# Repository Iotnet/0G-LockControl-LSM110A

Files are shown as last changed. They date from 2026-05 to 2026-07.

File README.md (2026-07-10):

# 0G LockControl — Alarma IoT dual (acelerómetro + magnético)

> Alarma inalámbrica compacta con detección de movimiento y apertura de puerta/ventana, comunicación Sigfox RC2 sobre el SoC LSM110A.

## Descripción

**0G LockControl** es un dispositivo electrónico autónomo que combina **dos modos de detección de eventos** y los transmite por la red **Sigfox (0G)**:

- **Movimiento / vibración** vía acelerómetro **LIS2DW12** (I²C).
- **Apertura de puerta o ventana** vía sensor magnético — **reed switch NA** o **hall DRV5032** (ambos footprints en la PCB).

El dispositivo es **event-driven**: duerme en modo Stop2 (~3 µA total) y solo despierta por interrupción de hardware. El firmware se ejecuta directamente sobre el **STM32WL** integrado en el LSM110A (firmware API, sin MCU externo).

### Características

- Comunicación **Sigfox RC2** (902-928 MHz, México) — sin WiFi ni red celular.
- Tamaño objetivo **< 5 cm** — instalación adhesiva en interior (oficina, bodega, cuarto frío).
- Batería desechable **CR2450 (3 V, 620 mAh)** + capacitor de soporte 470 µF para pulsos de TX.
- Vida útil estimada de meses a años según frecuencia de eventos.
- Costo reducido de operación y manufactura.

## Arquitectura del sistema

### Ciclo de operación

```
Sleep (3µA)  →  Wake por INT (accel o magnético)  →  Leer sensor
        →  Armar payload 12 bytes  →  TX Sigfox (~50 mA × 2 s)  →  Sleep
```

### Bloques del sistema

Arquitectura del producto — 0G LockControl

<details>
<summary>Ver arquitectura del sistema completo (dispositivo → Sigfox → nube → app)</summary>

Sistema completo

</details>

<details>
<summary>Ver diagrama anterior (v1)</summary>

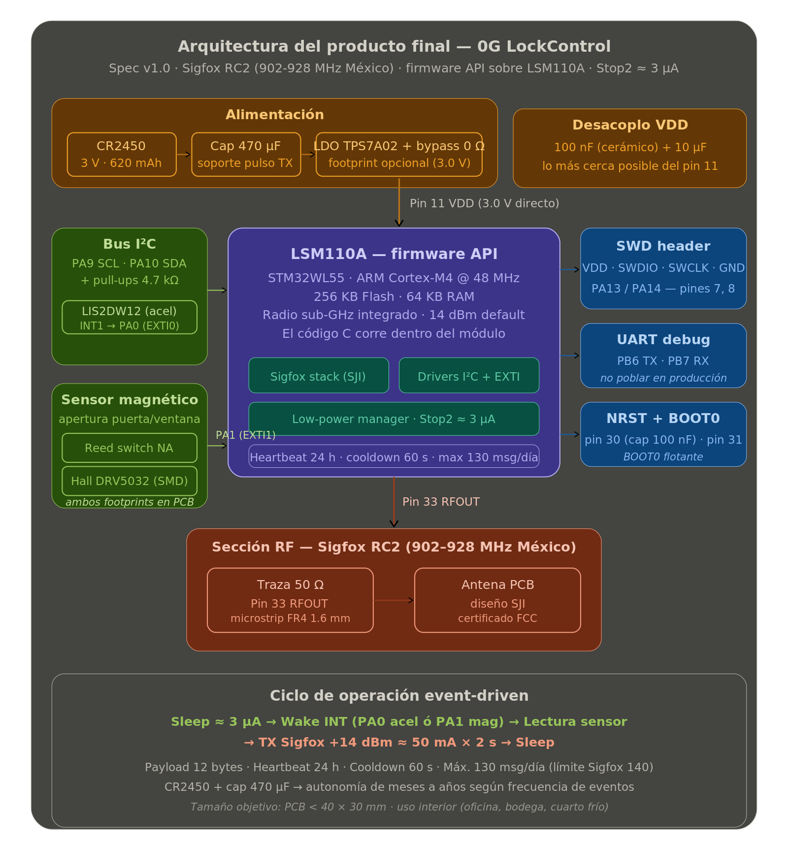
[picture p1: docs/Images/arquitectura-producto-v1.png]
Arquitectura del producto final — 0G LockControl (v1)


> Diagrama disponible también en formato vectorial: [arquitectura-producto-v1.svg](./docs/Images/arquitectura-producto-v1.svg)

</details>

### Flujo de operación

1. **Detección.** El acelerómetro o el sensor magnético genera una interrupción de hardware.
2. **Despierta.** El LSM110A sale del modo Stop2 vía EXTI.
3. **Lectura.** Se leen sensores (accel via I²C, estado del magnético).
4. **Transmisión.** Se arma el payload de 12 bytes y se envía un mensaje Sigfox.
5. **Entrega.** El backend de Sigfox ejecuta un callback HTTP hacia el servidor de la app.
6. **Notificación.** La app móvil muestra la alerta con timestamp e ID del dispositivo.

## Justificación de arquitectura y cumplimiento normativo

Este dispositivo utiliza el LSM110A con **firmware API** — el código de aplicación corre directamente dentro del STM32WL del módulo, sin MCU externo. Esta es una variante oficial ofrecida por el fabricante SJI.

**¿Por qué no se usa un MCU externo con comandos AT?**
- Menor consumo (un solo MCU en sleep vs dos)
- Menor tamaño (cumple objetivo <5cm)
- Menor costo (~$2-4 USD menos por unidad)
- Menor complejidad de firmware

**¿Se pierden certificaciones?**
No. La certificación Sigfox Verified cubre la capa de RF/protocolo, que es la misma en las versiones AT y API. Para nuestro producto final aplicaremos el enfoque modular de Sigfox Ready, que hereda la conformidad RF del módulo certificado. La FCC del módulo tampoco se afecta mientras no se modifique la capa de radio ni la antena.

Ver documento completo: [docs/arquitectura-justificacion.md](docs/arquitectura-justificacion.md)

### Certificaciones requeridas para comercialización

| Certificación | Qué cubre | Estado |
|---|---|---|
| Sigfox Verified | RF y protocolo del módulo | ✅ Heredada del LSM110A |
| Sigfox Ready | Rendimiento radiado del producto final | ☐ Post-MVP (prueba en lab acreditado) |
| FCC | Radiofrecuencia (USA) | ✅ Heredada del LSM110A (ID: 2AS8LLSM110A) |
| NOM-208 / IFT-008 | Regulación México 902-928 MHz | ☐ Post-MVP (homologación IFT) |

## Componentes principales

| Componente | Parte | Función |
|---|---|---|
| SoC + radio | **LSM110A** (STM32WL55) | MCU Cortex-M4 + radio Sigfox integrado |
| Acelerómetro | **LIS2DW12** (I²C) | Detección de movimiento, INT1 → PA0 |
| Sensor magnético A | **Reed switch NA** | Detección de apertura (opción A) |
| Sensor magnético B | **DRV5032** (hall) | Detección de apertura (opción B) |
| Batería | **CR2450** (3 V, 620 mAh) | Alimentación desechable |
| Cap. soporte | 470 µF electrolítico | Soporte para el pulso de TX Sigfox |
| LDO (opcional) | **TPS7A02** + bypass 0 Ω | Regulación opcional |
| Antena | Traza PCB 50 Ω | Diseño SJI (certificado FCC) |

## Plataforma de desarrollo

| Herramienta | Uso |
|---|---|
| **STM32CubeIDE** | Desarrollo de firmware (C, bare-metal) |
| **STM32CubeMX** | Configuración de periféricos y clocks |
| **KiCad** | Diseño esquemático y PCB |
| **ST-Link + SWD** | Programación y debug |
| **Sigfox Backend** | Dashboard y callbacks |

## Plan de milestones

| Milestone | Entregable | Semana |
|---|---|---|
| **M0** | Repo + spec + CubeIDE setup | 1-2 |
| **M1** | Esquemático KiCad | 2-5 |
| **M2** | FW en Nucleo (accel + reed + Sigfox) | 2-5 |
| **M3** | PCB layout + gerbers | 5-7 |
| **M4** | Low power validado en Nucleo | 7-8 |
| **M5** | PCB fabricada y ensamblada | 8-11 |
| **M6** | Integración FW en PCB custom | 11-12 |
| **M7** | Prueba de campo | 12 |

> **[Ver dashboard interactivo del plan MVP](https://jdiaznxt.github.io/0G-LockControl-LSM110A/docs/dashboard-mvp.html)** — Gantt con checklist por tarea, clic para expandir detalles.

## Estructura del repositorio

```
0G-LockControl-LSM110A/
├── Hardware/
│   ├── kicad/             # Proyecto KiCad (esquemático + PCB)
│   ├── Datasheets/        # Hojas de datos de componentes clave
│   ├── Schematic/
│   ├── PCB/
│   └── BOM/
├── Firmware/
│   ├── sdk/               # Fork del SDK de SJI (LSM110A)
│   ├── app/               # Código de aplicación
│   ├── drivers/           # Drivers de sensores I2C
│   ├── src/
│   ├── libs/
│   ├── config/
│   └── tools/
├── 3D-Models/
│   ├── Enclosure/
│   └── Assembly/
├── Tests/
│   ├── Lab/
│   └── Field/
├── App/
│   ├── Mobile/
│   └── Backend/
├── docs/
│   ├── spec-producto.md       # Especificación completa v1.0
│   ├── decisiones-tecnicas.md # Decisiones arquitectónicas (ADRs)
│   ├── pinout-lsm110a.md      # Asignación de pines
│   ├── Architecture/
│   ├── Images/
│   ├── References/
│   └── Guides/
├── .gitignore
└── README.md
```

## Antecedentes del desarrollo

Este proyecto es la evolución del trabajo realizado con la placa **NUCLEO-WL55JC2**, donde se validaron los siguientes hitos:

- Conexión exitosa a la red Sigfox (registro en backend, envío de mensajes).
- Conexión exitosa a LORIOT vía LoRaWAN (validación de stack).
- Implementación de detección de flanco con reed switch.
- Envío de payload Sigfox al detectar apertura.
- Caracterización del microcontrolador y periféricos del STM32WL55.

La transición al **LSM110A** permite pasar de una placa de desarrollo a un SoC integrado, habilitando el diseño de una PCB compacta y de bajo costo para producción. El firmware se programa directamente sobre el STM32WL del módulo (firmware API), sin necesidad de MCU externo ni de comandos AT.

## Protocolos de comunicación

### Sigfox (protocolo principal)

- **Zona:** RCZ2 (México / América Latina).
- **Frecuencia:** 902-928 MHz uplink.
- **Mensajes:** hasta 140 mensajes/día uplink, 4 downlink/día.
- **Payload:** máximo 12 bytes por mensaje.
- **Alcance:** hasta 50 km en zona rural, 3-10 km en zona urbana.
- **Potencia TX:** configurable, default +14 dBm (~50 mA).

### Comunicación local (futuro)

- BLE (Bluetooth Low Energy) para activación y configuración desde la app móvil.

## Documentación adicional

- 📕 **[Especificación de producto v1.0 (PDF)](./docs/References/spec-producto-lsm110a-v1.pdf)
- 📄 [Especificación de producto v1.0 (Markdown)](./docs/spec-producto.md)
- 📄 [Decisiones técnicas (ADRs)](./docs/decisiones-tecnicas.md)
- 📄 [Asignación de pines del LSM110A](./docs/pinout-lsm110a.md)
- 📄 [Justificación de arquitectura API + certificaciones](./docs/arquitectura-justificacion.md)

## Empresa

**0G IoT Net Solutions** — [iotnet.mx](https://iotnet.mx)

## Desarrollador

**José Francisco Díaz Figueroa** — Embedded Systems R&D Engineer
jdiaz@iotnet.mx

## Referencias

- [Documentación STM32WL Series](https://www.st.com/en/microcontrollers-microprocessors/stm32wl-series.html)
- [Repositorio LSM110A (Support-SJI)](https://github.com/Support-SJI/LSM110A)
- [Sigfox Build — Development](https://build.sigfox.com/development)
- [Sigfox Build — Industrialization](https://build.sigfox.com/industrialization#the-sigfox-credentials)
- [STM32CubeWL GitHub](https://github.com/STMicroelectronics/STM32CubeWL)
- [RF Board Layout Guide (AN5457)](https://www.st.com/resource/en/application_note/dm00660594.pdf)

## Licencia

Por definir.

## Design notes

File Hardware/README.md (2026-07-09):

# Hardware

Diseño electrónico del dispositivo 0G LockControl basado en el SoC LSM110A.

## Subcarpetas

### Schematic/
Esquemáticos del circuito. Incluye el sistema mínimo del LSM110A: alimentación (LDO), oscilador, protección ESD, conector de programación (SWD/UART), reed switch, y matching network de la antena.

### PCB/
Diseño de la tarjeta de circuito impreso. PCB de una sola capa para reducir costos. Considera separación entre circuitos digitales y RF, plano de tierra, y rutas críticas aisladas según guía AN5457 de ST.

### BOM/
Lista de materiales con referencias de proveedores (Mouser, DigiKey, LCSC), cantidades, costos unitarios y alternativas.

### Datasheets/
Hojas de datos de los componentes principales: LSM110A, reed switch, regulador LDO, antena, conectores.

### validation/
Evidencia de los gates de validación de hardware. `gate2-tx-pulse/` contiene la
[guía de fuente variable y emulación de CR2450](validation/gate2-tx-pulse/setup-fuente-variable.md)
para medir el pulso TX (issue #6); el reporte GO/NO-GO va en `REPORT.md`.

## Consideraciones de Diseño

- El LSM110A integra el STM32WL (Cortex-M4 + radio Sub-GHz), eliminando la necesidad de un módulo RF externo
- Programación vía ST-LINK externo o UART para reducir costo del BOM
- Diseño EMC/EMI según guía de ST para RF layout optimizado
- Antena: PCB trace antenna o chip antenna (868 MHz) por evaluar

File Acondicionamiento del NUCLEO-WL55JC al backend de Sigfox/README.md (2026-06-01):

# Acondicionamiento del NUCLEO-WL55JC al backend de Sigfox

Guía resumida del procedimiento de vinculación end-to-end de una placa **STMicroelectronics NUCLEO-WL55JC** (MB1389, MCU `STM32WL55JCI`) a la red Sigfox 0G bajo **Radio Configuration 2 (RC2 México)**, operada por **0G IoT Solutions** (previamente WND México). Procedimiento ejecutado y validado el **29 de mayo de 2026**.

El flujo cubre desde la instalación del entorno de desarrollo hasta el primer uplink confirmado en el backend de Sigfox, incluyendo los 10 errores reales encontrados durante el proceso y sus soluciones.

Empresa operadora: **0G IoT Solutions** — [0giotsolutions.com](https://0giotsolutions.com/)

---

# Contenido

- [Resultado obtenido](#resultado-obtenido)
- [Requisitos](#requisitos)
- [Mapa de las 8 fases](#mapa-de-las-8-fases)
- [Fase 1 · Instalar entorno](#fase-1--instalar-entorno)
- [Fase 2 · Conexión física](#fase-2--conexión-física)
- [Fase 3 · Compilar y flashear firmware](#fase-3--compilar-y-flashear-firmware)
- [Fase 4 · Extraer chip certificate](#fase-4--extraer-chip-certificate)
- [Fase 5 · Portal sfxp y credentials.zip](#fase-5--portal-sfxp-y-credentialszip)
- [Fase 6 · Escribir sigfox_data al flash](#fase-6--escribir-sigfox_data-al-flash)
- [Fase 7 · Registro en backend](#fase-7--registro-en-backend)
- [Fase 8 · Primer uplink](#fase-8--primer-uplink)
- [Errores frecuentes (los 10 reales encontrados)](#errores-frecuentes-los-10-reales-encontrados)
- [Direcciones de memoria críticas](#direcciones-de-memoria-críticas)
- [Comandos AT V1.5.0](#comandos-at-v150)
- [Documento completo](#documento-completo)
- [Referencias](#referencias)

---

# Resultado obtenido

| Variable | Valor |
|---|---|
| **Device ID Sigfox** | `033E07FC` |
| **PAC inicial (emitido por ST)** | `B06EA49C9E0F11F4` |
| **PAC post-registro (rotado)** | `BC07485F3FFF8B71` |
| **Device Type** | `Nucleo_WL` |
| **Group** | `DHW` |
| **Contract** | `UnaTag_test` |
| **Frecuencia uplink medida** | `902.1782 MHz` |
| **Base station receptora** | `6BCE` |
| **RSSI primer uplink** | `-127.00 dBm` |
| **Link Quality** | AVERAGE (3/5) |
| **Frames recibidos** | 1 de 3 |
| **Payload** | `48656C6C6F` ("Hello") |
| **Delay backend** | 3.2 s |
| **Versiones firmware** | APP V1.5.0 · MW_SIGFOX V1.8.0 · MW_RADIO V1.4.0 |



---

# Requisitos

**Hardware:**

- Placa NUCLEO-WL55JC (MB1389) con MCU `STM32WL55JCI`.
- Antena SMA compatible con banda 868/915 MHz (incluida en el kit).
- Cable USB micro-B.

**Software:**

- STM32CubeIDE 2.0.0+
- **STM32CubeProgrammer 2.6+** (crítico: el menú Sigfox Credentials existe desde 2.6).
- **STM32CubeWL V1.5.0** descargado de [st.com](https://www.st.com/en/embedded-software/stm32cubewl.html) — **NO** clonar desde GitHub (ver error #1).
- Cliente serial (Arduino Serial Monitor, `screen`, CoolTerm).

**Cuentas:**

- myST con acceso a `my.st.com/sfxp`.
- Admin en `backend.sigfox.com` con permisos en el grupo correspondiente.

---

# Mapa de las 8 fases

```
┌──────────────────────┐   ┌──────────────────────┐
│ 1 · Instalar entorno │ → │ 5 · Portal sfxp      │
└──────────┬───────────┘   └──────────┬───────────┘
           ↓                          ↓
┌──────────────────────┐   ┌──────────────────────┐
│ 2 · Conexión física  │   │ 6 · Escribir flash   │
└──────────┬───────────┘   └──────────┬───────────┘
           ↓                          ↓
┌──────────────────────┐   ┌──────────────────────┐
│ 3 · Flashear firmware│   │ 7 · Registro backend │
└──────────┬───────────┘   └──────────┬───────────┘
           ↓                          ↓
┌──────────────────────┐   ┌──────────────────────┐
│ 4 · Chip certificate │ ⮕ │ 8 · Primer uplink ✓  │
└──────────────────────┘   └──────────────────────┘
```

Las fases **4 y 5** son la extracción y validación de credenciales (etapa crítica). La fase **8** es la validación end-to-end del flujo completo.

---

# Fase 1 · Instalar entorno

```bash
# Crear carpeta limpia para el SDK
mkdir -p ~/ST
cd ~/Downloads
unzip stm32cubewl-v1-5-0.zip -d ~/ST/

# Verificar que SÍ trae la app Sigfox (a diferencia del GitHub público)
find ~/ST -type d -name "Sigfox_AT_Slave"
```

Salida esperada:

```
~/ST/STM32Cube_FW_WL_V1.5.0/Projects/NUCLEO-WL55JC1/Applications/Sigfox/Sigfox_AT_Slave
```

> El proyecto del SDK se llama `NUCLEO-WL55JC1` (banda alta 865–928 MHz), que es la apropiada para Sigfox RC2 México (902.2 MHz uplink).

---

# Fase 2 · Conexión física

1. Antena SMA → conector **CN12**.
2. Jumpers de fábrica: JP1 ON, JP3 ON, JP4 [1-2], JP7 ON.
3. USB micro-B → **CN1** (lado ST-LINK).
4. **LED5 verde (PWR)** encendido.

Verificación en macOS:

```bash
ls /dev/cu.usbmodem*                 # Debe enumerar al menos un puerto
ioreg -p IOUSB -l | grep -i stlink   # Debe mostrar STLINK-V3
```

En STM32CubeProgrammer:

| Parámetro | Valor |
|---|---|
| Port | SWD |
| **Mode** | **Under reset** ⚠️ |
| **Reset mode** | **Hardware reset** ⚠️ |
| Frequency | 12000 kHz |
| Speed | Reliable |

Click **Connect**. Target esperado: `STM32WLxx · Device ID 0x497 · Rev Y · 256 KB · Cortex-M4 · 3.27 V`.

---

# Fase 3 · Compilar y flashear firmware

**Importar proyecto en STM32CubeIDE:**

`File → Open Projects from File System` → ruta:

```
~/ST/STM32Cube_FW_WL_V1.5.0/Projects/NUCLEO-WL55JC1/Applications/Sigfox/Sigfox_AT_Slave/STM32CubeIDE/
```

**Build:** click derecho sobre `Sigfox_AT_Slave` → Clean → Build.

Resultado esperado:

```
text     data    bss    dec    hex   filename
75512    312     10544  86368  15160 Sigfox_AT_Slave.elf
Build Finished. 0 errors, 0 warnings.
```

**Flashear con CubeProgrammer** (NO usar `Run As` de CubeIDE — pide ST-Link Server, ver error #2):

1. Connect (Mode: Under reset).
2. Erasing & Programming → Browse → seleccionar `Sigfox_AT_Slave.elf`.
3. ✓ Verify programming · ✓ Run after programming.
4. **Start Programming**.

> Tras `Run`, aparece `Warning: Connection to device is lost`. **Es esperado**, el firmware Sigfox entra en low-power y suelta SWD (ver error #4).

**Verificación AT (Serial Monitor 9600 baud, Carriage return):**

Boot banner esperado:

```
APPLICATION_VERSION: V1.5.0
MW_SIGFOX_VERSION:   V1.8.0
MW_RADIO_VERSION:    V1.4.0
ATtention command interface
SIGFOX APPLICATION READY
```

Test:

```
AT             → OK
AT$ID          → FEDCBA98          (valor TEST, sin credenciales)
AT$PAC         → 0000000000000000  (valor TEST, sin credenciales)
```

> **Sintaxis V1.5.0:** comando sin `?` (`AT$ID`, no `AT$ID?`). El `?` muestra ayuda en lugar del valor.

---

# Fase 4 · Extraer chip certificate

1. Cerrar Serial Monitor (libera VCP/ST-LINK).
2. CubeProgrammer → Connect (Mode: Under reset).
3. Sidebar izquierdo → ícono **Sigfox Credentials**.
4. Pestaña **Read** → botón **Read** → aparecen 136 bytes en hex.
5. **Save chip certificate** → guardar como `chip_cert_<id_o_descripcion>.bin`.
6. **Copy chip certificate** → queda en clipboard.

Log esperado:

```
Size:    136 Bytes
Address: 0x1FFF3F04
Data read successfully
```

---

# Fase 5 · Portal sfxp y credentials.zip

1. Abrir [my.st.com/sfxp](https://my.st.com/sfxp) → login myST.
2. Pegar el chip certificate en el textarea (Cmd+V) o subir el `.bin`.
3. Click el botón **Sigfox™ credentials**.
4. Descarga automática de `sigfox_credentials.zip`.

Contenido del ZIP:

```bash
unzip -l sigfox_credentials.zip
  Length      Date    Time    Name
       48  ...                sigfox_data_033E07FC.bin   ← este flashearemos
     1607  ...                sigfox_data_033E07FC.h     ← header alternativo
```

> El sufijo del nombre **es el Device ID Sigfox**. En este caso `033E07FC`.

---

# Fase 6 · Escribir sigfox_data al flash

**Estructura del .bin (48 bytes):**

```bash
xxd sigfox_data_033E07FC.bin
00000000: fc07 3e03 b06e a49c 9e0f 11f4 0100 0000  ← ID LE + PAC + flags
00000010: 51ad 0eba 0e92 e90b 7fa6 78f1 bf23 3e5d  ← KEY AES-128 cifrada
00000020: 4d5f 3030 3438 5f41 4237 375f 3031 3fd5  ← chip serial ASCII + CRC
```

| Offset | Contenido |
|---|---|
| `0x00-0x03` | Device ID (little-endian) |
| `0x04-0x0B` | PAC |
| `0x0C-0x0F` | Flags |
| `0x10-0x1F` | KEY AES-128 cifrada |
| `0x20-0x2D` | Identificador interno ASCII |
| `0x2E-0x2F` | Checksum |

**Procedimiento en CubeProgrammer:**

1. Click ícono **Sigfox Credentials**.
2. Sección **SigFox credential provisioning** (abajo):
   - Configuration: `Binary-Raw`
   - **Address: `0x0803E500`** (autocompletado)
   - Binary file: Browse → `sigfox_data_033E07FC.bin`
   - Header file: vacío
3. Click **Write data** → mensaje `SigFox credential provisioning succeeded`.

**Verificación tras reset (botón B4):**

```
AT$ID    → 033E07FC          ✓ (ya no FEDCBA98)
AT$PAC   → B06EA49C9E0F11F4  ✓ (ya no ceros)
```

---

# Fase 7 · Registro en backend

URL: [backend.sigfox.com](https://backend.sigfox.com/auth/login)

**Caso A — Device pre-existente** (el más frecuente con placas de lab reutilizadas):

El device ya aparece en el backend con un PAC **diferente** al del `.h`. Esto es **normal**: el PAC se consume y rota al primer registro. La KEY AES-128 (que es lo que importa) no cambia y el device transmite correctamente.

**Caso B — Device nuevo:**

```
Menu Group       → New (si no existe)
Menu Device Type → New:
    Name: NUCLEO-WL55JC-RC2-DevTest
    Keep alive period: 0 (o 1440 min para 1/día)
    Payload display: Regular (raw)
    Downlink mode: Direct
Menu Device      → New:
    Device ID: 033E07FC
    PAC: B06EA49C9E0F11F4  ← se consumirá
    Device Type: el creado arriba
    Prototype: ☐ (producción real)
```

---

# Fase 8 · Primer uplink

Con la placa lista, Arduino Serial Monitor abierto (9600 baud, CR):

```
AT$RC=2                   → OK   (región RC2 México, persistida en EEPROM)
ATS302=22                 → OK   (potencia TX 22 dBm, máx FCC RC2)
AT$SF=48656C6C6F          → OK   (después de ~6 s)
```

`48656C6C6F` = "Hello" en hex. La placa transmite 3 réplicas (TX1/TX2/TX3) en frecuencias de hopping distintas.

**Verificar en backend:**

`Device 033E07FC → Messages`. En 2–30 segundos debe aparecer:

| Time | Data | Station | RSSI | Freq | Frames | LQI |
|---|---|---|---|---|---|---|
| 2026-05-29 11:41:05 | `48656c6c6f` | `6BCE` | `-127 dBm` | `902.1782 MHz` | 1 | AVERAGE |

---

# Errores frecuentes (los 10 reales encontrados)

| # | Síntoma | Solución express |
|---|---|---|
| **1** | GitHub clone de STM32CubeWL no trae carpeta `Sigfox/` | Descargar ZIP de [st.com](https://www.st.com/en/embedded-software/stm32cubewl.html) (incluye licencia UnaBiz). |
| **2** | CubeIDE 2.0.0 pide *ST-Link Server* al hacer Run | Flashear el `.elf` directamente con CubeProgrammer (acepta ELF). |
| **3** | Error `Unable to get core ID` / `No STM32 target found` | Mode: **Under reset** + Reset mode: **Hardware reset** en CubeProgrammer. |
| **4** | `Connection to device is lost` después de Run | **No es error** — firmware Sigfox entra en low-power y suelta SWD. Es esperado. |
| **5** | `AT$ID?` devuelve texto de ayuda en lugar del valor | Usar el comando **sin `?`** en V1.5.0: `AT$ID` (no `AT$ID?`). |
| **6** | No existe `rfconf.h` para definir `REGION_RC2` | En V1.5.0 la región es **runtime**, no compile-time. Usar `AT$RC=2`. |
| **7** | Workspace de CubeIDE muestra dos proyectos con Sigfox | Cerrar el SDK genérico (`LSM1x0A_SDK_LoRaWAN_Sigfox`), trabajar solo en `Sigfox_AT_Slave`. |
| **8** | PAC en backend ≠ PAC del `.h` | Normal: PAC rota al primer registro. KEY (lo que firma uplinks) no cambia. |
| **9** | Portal sfxp descarga ZIP de 0 bytes / Service unavailable | Cache, browser distinto, horario distinto. Inestabilidad documentada desde 2023. |
| **10** | Mass storage `NODE_WL55JC` no monta en macOS | No bloqueante — flasheamos por SWD, no por drag-and-drop. |

---

# Direcciones de memoria críticas

| Dirección | Tamaño | Región | Contenido |
|---|---|---|---|
| `0x08000000` | 256 KB | Flash | Firmware `Sigfox_AT_Slave_CM4` |
| `0x0803E500` | 2 KB | `USER_Key_region_ROM` | `sigfox_data.bin` (credenciales) |
| `0x1FFF3F04` | 136 B | System memory | Chip certificate (wafer probe) |
| `0x20000000` | 64 KB | SRAM | RAM de trabajo |

---

# Comandos AT V1.5.0

| Comando | Función |
|---|---|
| `AT` | Test (responde OK) |
| `AT$ID` | Lee Device ID (4 bytes hex) |
| `AT$PAC` | Lee PAC (8 bytes hex) |
| `AT$RC=N` | Configura región (N=1..7), persiste en EEPROM |
| `AT$SF=<hex>` | Envía uplink (≤ 12 bytes payload) |
| `AT$SF=<hex>,1` | Uplink con downlink request (consume 2 tokens) |
| `AT$SB=<bit>` | Envía 1 bit (mínimo overhead) |
| `ATS302=N` | Potencia TX en dBm (máx 22 para RC2 FCC) |
| `AT$RST` | Reset del MCU |

---

# Documento completo

La guía detallada de 29 páginas en LaTeX está en:

```
~/Documents/VS/Latex/Aprovisionamiento_Sigfox_RC2_NUCLEO-WL55JC2/
├── Guia_Sigfox_RC2_NUCLEO-WL55JC2.tex   ← fuente LaTeX
├── Guia_Sigfox_RC2_NUCLEO-WL55JC2.pdf   ← PDF compilado
└── img/                                 ← assets (logo 0G)
```

El PDF incluye portada, índice, las 8 fases con tablas y código, el diagrama TikZ del flujo, sección extendida de errores y soluciones, anexos técnicos (memory map, parámetros RF de RC2 México, comandos AT), referencias completas y resumen ejecutivo.

---

# Referencias

| Documento | URL |
|---|---|
| Producto NUCLEO-WL55JC | https://www.st.com/en/evaluation-tools/nucleo-wl55jc.html |
| UM2592 (HW manual MB1389) | https://www.st.com/resource/en/user_manual/um2592-stm32wl-nucleo64-board-mb1389-stmicroelectronics.pdf |
| AN5480 (Sigfox + CubeWL) | https://www.st.com/resource/en/application_note/an5480-how-to-build-a-sigfox-application-with-stm32cubewl-stmicroelectronics.pdf |
| STM32CubeWL (st.com, **NO GitHub**) | https://www.st.com/en/embedded-software/stm32cubewl.html |
| Portal credenciales sfxp | https://my.st.com/sfxp |
| Backend Sigfox | https://backend.sigfox.com/ |
| Sigfox API docs | https://support.sigfox.com/apidocs |
| Cobertura Sigfox México | https://coverage.sigfox.com |
| 0G IoT Solutions | https://0giotsolutions.com/ |

---

**Autor:** Yahir Flores — `yflores@iotnet.mx`
**Empresa:** 0G IoT Solutions (previamente WND México)
**Fecha:** 29 de mayo de 2026
**Versión:** 1.0

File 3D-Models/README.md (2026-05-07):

# 3D Models

Diseño mecánico del encapsulado (carcasa) del dispositivo 0G LockControl.

## Subcarpetas

### Enclosure/
Archivos CAD de la carcasa (STL, STEP, F3D):
- Protección IP54 mínima (polvo y salpicaduras)
- Resistencia a impactos
- Orificios/ranuras para antena
- Montaje mediante tornillos o cinta adhesiva industrial
- Compatible con marcos, muros y estructuras metálicas

### Assembly/
Ensamblaje completo del dispositivo mostrando la integración de PCB, batería, sensor y carcasa.

## Notas

- Prototipado inicial por impresión 3D (FDM/SLA)
- Futuras iteraciones: moldeo por inyección
- Considerar interferencia electromagnética del encapsulado sobre la antena

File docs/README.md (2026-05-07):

# Documentación

Documentación técnica, de arquitectura y guías del proyecto 0G LockControl.

## Subcarpetas

### Architecture/
Documentos de arquitectura del sistema, decisiones de diseño (ADR), y diagramas de bloques.

### Images/
Diagramas, fotos de prototipos, capturas de pantalla, y material visual del proyecto.

### References/
PDFs de referencia:
- Application notes de ST (AN5457 - RF Board Layout)
- Guías de activación Sigfox
- Documentación de Sigfox Build
- Paper: "Sigfox and LoRaWAN combined for Smarter Meters"

### Guides/
Guías operativas:
- Guía de instalación del dispositivo
- Guía de manufactura y ensamblaje
- Guía de activación y registro en red Sigfox
- Manual de usuario

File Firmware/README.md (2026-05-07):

# Firmware

Código fuente y configuración del firmware para el LSM110A (STM32WL core).

## Subcarpetas

### src/
Código fuente principal: `main.c`, handlers de interrupción, rutinas de transmisión Sigfox, gestión de bajo consumo, y detección de flancos del reed switch.

### libs/
Librerías y stacks externos:
- HAL STM32WLxx (Hardware Abstraction Layer)
- Stack Sigfox (SIGFOX_API)
- BSP del LSM110A
- CMSIS

### config/
Archivos de configuración del proyecto:
- `.ioc` (STM32CubeMX pinout y periféricos)
- Linker scripts (`.ld`)
- Archivos de configuración de credenciales Sigfox (ID, PAC, KEY)

### tools/
Scripts auxiliares:
- Scripts de programación (flash via UART/SWD)
- Scripts de pruebas automatizadas
- Utilidades de compilación

## Flujo del Firmware

```
[RESET/Power On]
       │
       ▼
[Inicialización]
  - HAL_Init()
  - SystemClock_Config()
  - GPIO_Init() (reed switch en EXTI)
  - Sigfox_Init()
       │
       ▼
[Modo STOP/Sleep] ◄──────────────┐
  (ultra bajo consumo)            │
       │                          │
  [Interrupción EXTI]            │
  (flanco del reed switch)       │
       │                          │
       ▼                          │
[Procesar Evento]                │
  - Debounce (filtro anti-rebote) │
  - Armar payload Sigfox          │
  - SIGFOX_API_send_frame()       │
  - Confirmar transmisión         │
       │                          │
       └──────────────────────────┘
```

## Referencia del Código Base (NUCLEO-WL55JC2)

El firmware se basa en el código validado con la placa NUCLEO:
- Detección de flanco en PB1 (reed switch)
- Función `GestionarFlancoPB1()` con anti-rebote
- Función `EnviarMensajeFranco()` para transmisión Sigfox
- Configuración de reloj MSI a 32 MHz

## Herramientas

| Herramienta | Uso |
|---|---|
| STM32CubeIDE v1.18.1+ | Compilación y depuración |
| STM32CubeProgrammer | Flash del binario |
| Repositorio LSM110A | [Support-SJI/LSM110A](https://github.com/Support-SJI/LSM110A) |

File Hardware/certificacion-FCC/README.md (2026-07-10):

# Certificación FCC — LSM110A (FCC ID: 2AS8LLSM110A / IC: 25119-LSM110A)

Documentos del expediente FCC. Fuente: fcc.report/FCC-ID/2AS8LLSM110A

## Datos críticos de diseño (User Manual, doc 5937666)

**PCB de referencia SJI:** 50×80 mm · 2 capas · FR4 1.6 mm · εr = 4.3

**Línea RF:** CPWG 50 Ω — ancho 1.0 mm / clearance 0.15 mm (NO es microstrip)

**Matching network (pin 33 RFOUT → antena):** L101 = 0 Ω serie · C101 = 2.2 pF shunt · C102 = DNI

**Antena:** patrón "EVB_LSM ANT" de SJI · monopolo serpentín · 1.9 dBi pico · cuasi-omni.
SOLO se acepta este patrón — otra antena invalida la certificación modular.
El Gerber es CONFIDENCIAL: solicitar a GREATECH (distribuidor) o SJI bajo NDA.

## Requisitos de integración (KDB 996369 D03)
- Separación mínima antena-personas: 20 cm (documentar en manual del producto)
- Etiquetado del producto final: "Contains FCC ID: 2AS8LLSM110A" y "Contains IC: 25119-LSM110A"
- El producto final requiere prueba Part 15 Subpart B (radiadores no intencionales)
- TX máx +21 dBm ±2 dB

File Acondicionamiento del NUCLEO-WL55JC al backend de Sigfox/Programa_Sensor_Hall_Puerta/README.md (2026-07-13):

# Programa Sensor Hall Puerta (NUCLEO-WL55JC1 → Sigfox)

Monitoreo de **apertura de puerta** con sensor magnético **sin polaridad** (contacto reed de 2 hilos o Hall omnipolar AH1815/SL353/DRV5032-FB/FC). Envía uplink Sigfox al **ABRIR y al CERRAR**, por **interrupción EXTI de ambos flancos** — ya no por sondeo como `Programa_Sensor_Hall_Magnetico`.

Backend Sigfox de **0G IoT Solutions** (previamente WND México) — https://0giotsolutions.com/

---

## ⚠️ Este programa es un proyecto STANDALONE (regla nueva)

A diferencia de los programas anteriores (parches sobre el `Sigfox_AT_Slave` compartido), este es el **primer programa bajo la regla "1 programa = 1 proyecto = 1 `.ioc` = 1 app"**:

- El proyecto CubeIDE completo vive en **`~/Documents/Programa_Sensor_Hall_Puerta/`** (árbol autocontenido: Drivers + Middlewares con libs Sigfox + Utilities + proyecto). GitHub solo documenta el código.
- El pin del sensor se declara en el **`.ioc` propio** y CubeMX genera `gpio.c` / EXTI1 / NVIC — cero hacks manuales de interrupciones.
- Los módulos de otros programas (buttons/distance/hall/flow) **no existen** en este proyecto.
- Esta carpeta contiene el módulo completo (`src/*.c/.h`) y los deltas vs el AT_Slave base (`src/*.patch`) para entender/reproducir el proyecto.

## Contenido de la carpeta

```
Programa_Sensor_Hall_Puerta/
├── README.md
├── backend/
│   └── sigfox_time_server.py    Callback BIDIR de hora (pruebas laptop+túnel)
└── src/
    ├── hall_door_app.c / .h     Módulo de la app (EXTI→debounce→task→TX)   [NUEVO -> Sigfox/App]
    ├── app_features.h           Un solo flag: USE_DOOR_APP                  [NUEVO -> Core/Inc]
    ├── ioc.patch                PA1=HALL_DOOR ambos flancos + NVIC EXTI1    [MOD -> .ioc]
    ├── sgfx_app.c.patch         DoorHall_Init() en Sigfox_Init()            [MOD]
    ├── utilities_def.h.patch    Task CFG_SEQ_Task_DoorTx                    [MOD]
    ├── stm32wlxx_it.c.patch     EXTI1 generado + callback → módulo          [MOD]
    ├── gpio.c.patch             PA1 rising+falling + NVIC (como CubeMX)     [MOD]
    ├── main.h.patch             Defines HALL_DOOR_Pin                       [MOD]
    ├── at_time.patch            Comando AT$TIME=HH:MM:SS (hora del payload) [MOD]
    └── dot_project.patch        Linked resource de hall_door_app.c          [MOD]
```

## Hardware / cableado

Contacto seco de 2 hilos (reed de puerta) — sin polaridad, sin alimentación:

| Sensor | Pin Nucleo | Header |
|---|---|---|
| Hilo 1 | **PA1** | Morpho **CN10 pin 36** |
| Hilo 2 | GND | Morpho **CN10 pin 20** |

- Pull-up **interno** activado desde el `.ioc`. Imán presente (puerta cerrada) = contacto cerrado = PA1 en BAJO.
- **B2 comparte PA1**: sirve de simulador sin cablear nada (presionado = puerta cerrada).
- Hall omnipolar de 3 pines: VDD→3V3, GND→GND, OUT→PA1 (misma lógica activo-bajo).
- Si el reed fuera normalmente-cerrado (lectura invertida): `DOOR_ACTIVE_LOW = 0` en `hall_door_app.h`.
- Instalación real con cable largo: filtro RC en el pin (10 kΩ a 3V3 + 1 nF a GND).

## Cómo funciona

```
EXTI (cualquier flanco en PA1)
  └─► re-arma DebounceTimer (one-shot 200 ms)
        └─► agenda CFG_SEQ_Task_DoorTx en el sequencer
              └─► lee nivel ESTABLE; si cambió vs último TX:
                    ├─ ventana libre → TX Sigfox + arma GapTimer (10 s)
                    └─ en ventana   → queda pendiente; al expirar GapTimer
                                      se re-chequea y se reporta el estado FINAL
```

- Una ráfaga de aperturas/cierres colapsa en **un solo uplink coherente** (el estado final nunca se pierde).
- Tope diario `DOOR_MAX_TX_PER_DAY = 100` (contrato RC2: 140/día) + reset por timer de 24 h.
- La interfaz AT (LPUART1 115200) sigue activa en paralelo.

### Parámetros (`hall_door_app.h`)

| Define | Default | Controla |
|---|---|---|
| `DOOR_DEBOUNCE_MS` | 200 | Estabilidad tras el último flanco |
| `DOOR_TX_MIN_GAP_MS` | 10000 | Ventana mínima entre uplinks |
| `DOOR_MAX_TX_PER_DAY` | 100 | Tope diario (0 = sin tope) |
| `DOOR_TX_STARTUP_STATE` | 0 | 1 = reporta estado inicial al arrancar |
| `DOOR_ACTIVE_LOW` | 1 | Nivel con imán presente |

## Payload Sigfox (6 bytes)

| Byte | Contenido |
|---|---|
| 0 | bit1 = estado (**0=ABIERTA / 1=CERRADA**) · bit0 = **hora confiable** (1 = reloj sincronizado por downlink). Valores: `0x00`/`0x01` abierta, `0x02`/`0x03` cerrada |
| 1–3  | Hora del evento **HH MM SS** (hora local, `DOOR_TZ_OFFSET_S` = UTC-6) |
| 4–5  | Contador de eventos confirmados (uint16 BE, con wrap) |

Ej.: `03 10 05 2A 00 07` = CERRADA a las 16:05:42 con hora confiable, 7.º evento. El uplink `F0` es la **petición de hora** (no es evento de puerta). El backend además timestampea cada mensaje del lado servidor. En el producto LSM110A este evento migra al payload de 12 bytes (spec §4.4, byte 5 = estado magnético).

**Hora automática — 3 niveles** (todo en `hall_door_app.c`, flags en el `.h`):

1. **Downlink Sigfox**: al boot (+8 s) manda `F0` con `initiate_downlink_flag`; el backend responde **8 bytes = epoch Unix UTC uint32 BE + 4 reservados** → reloj exacto con fecha, guardado en hora local. Sin respuesta: reintento cada 24 h; sincronizado: re-sync cada `DOOR_TIME_RESYNC_DAYS` (7). Máximo 1 downlink/día de los 4 que permite Sigfox. **Requiere callback BIDIR en el backend** (pendiente de configurar).
2. **Siembra de compilación** (`__TIME__`): automática al arrancar si el reloj viene en cero (best-effort, bit0=0, base epoch-2000).
3. **Manual**: `AT$TIME=HH:MM:SS` / `AT$TIME?` (ver `src/at_time.patch`; best-effort, sin fecha).

El reloj sobrevive resets/re-flasheos (backup domain); un power-cycle regresa a la siembra hasta el siguiente downlink. Umbral de confiabilidad: epoch ≥ 2025-01-01 (`DOOR_CLOCK_REAL_EPOCH_MIN`), que solo el downlink puede producir. **Importante**: el reset NO corrige un desfase de la siembra — el reloj sobrevive con todo y su error (que nace del gap compilar→encender); la hora exacta solo llega por downlink (o `AT$TIME`).

### Configurar el callback BIDIR (hora por downlink) — pruebas con laptop

1. **Servidor** (Terminal 1):
   ```
   python3 backend/sigfox_time_server.py     # escucha en :8000, solo stdlib
   ```
2. **Túnel público** (Terminal 2), cualquiera de los dos:
   ```
   ngrok http 8000                                        # requiere cuenta
   cloudflared tunnel --url http://localhost:8000         # sin cuenta
   ```
   Copiar la URL `https://...` que entregue.
3. **backend.sigfox.com** → Device Type del dispositivo → **Callbacks → New → Custom callback**:

   | Campo | Valor |
   |---|---|
   | Type | **DATA / BIDIR** |
   | Channel | URL |
   | Url pattern | `https://<tu-tunel>/sigfox/time` |
   | HTTP method | POST |
   | Content-Type | `application/json` |
   | Body | `{"device":"{device}","time":{time},"data":"{data}","ack":{ack}}` |

   ⚠️ En la lista de callbacks, marcar el **radiobutton de la columna "Downlink"** en este callback, y en el Device Type verificar **Downlink data = CALLBACK**.
4. Reset a la Nucleo → a los ~8 s pide (`F0`), el servidor loguea la petición y responde el epoch → en la serie: `Reloj sincronizado por downlink: HH:MM:SS (local, UTC-6)`. Desde ahí los eventos salen con bit0=1 y hora exacta.

El servidor responde `{"<device>":{"downlinkData":"<epoch hex 8c>00000000"}}` solo cuando `ack=true` (petición `F0`); a los uplinks normales responde 204 sin downlink. Para producción, mover la misma lógica a una función serverless o UnaConnect (URL permanente).

## Compilación / flasheo

1. Importar `~/Documents/Programa_Sensor_Hall_Puerta/` en CubeIDE (*Import → Existing Projects*, sin copiar).
2. Build → Run (ST-LINK). El linker ya trae el fix **NOLOAD**: las credenciales Sigfox en `0x0803E500` sobreviven al re-flasheo (ver `Persistencia_Credenciales_NOLOAD/`).
3. Serie 115200: banner `DOOR HALL APP LISTA` + eventos `[DOOR] >> TX evento #N: puerta CERRADA/ABIERTA`.

> Nota macOS: si CubeIDE pide "ST-Link Server", instalar el paquete **ST-LINK-SERVER** de st.com; si el GUI no lo encuentra (macOS 15+), lanzar CubeIDE desde Terminal.

---
*Fecha: Julio 2026 · Autor: Yahir Flores · Base: Sigfox_AT_Slave V1.5.0 (NUCLEO-WL55JC1, RC2 México)*
*Empresa: 0G IoT Solutions (previamente WND México) — https://0giotsolutions.com/*

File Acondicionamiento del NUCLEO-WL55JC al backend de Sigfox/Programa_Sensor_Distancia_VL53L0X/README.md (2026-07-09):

# Programa Sensor de Distancia / Puerta — VL53L0X (NUCLEO-WL55JC → Sigfox)

Añade al firmware `Sigfox_AT_Slave` V1.5.0 la lectura de un sensor ToF **VL53L0X** por I2C y la detección **puerta abierta / cerrada** con histéresis, con envío Sigfox **solo por evento**. Mantiene en paralelo la interfaz AT.

Backend Sigfox de **0G IoT Solutions** (previamente WND México) — https://0giotsolutions.com/

---

## Contenido de la carpeta

```
Programa_Sensor_Distancia_VL53L0X/
├── README.md
└── src/
    ├── app_features.h            Selector de apps (feature flags)         [NUEVO -> Core/Inc]
    ├── i2c.h / i2c.c             Periférico I2C2 (bus del VL53)           [NUEVO -> Core/Inc, Core/Src]
    ├── distance_app.h / .c       Lógica de distancia / puerta             [NUEVO -> Sigfox/App]
    ├── vl53l0x.h / .c            Driver propio VL53L0X (8 bits)           [NUEVO -> Sigfox/App]
    ├── vl53l1_platform.h / .c    Shim ULD VL53L1X (opcional, no usado)    [NUEVO -> Sigfox/App]
    ├── sgfx_app.c.patch          Llamada Distance_Init() en Sigfox_Init() [MOD]
    ├── utilities_def.h.patch     ID de tarea CFG_SEQ_Task_DistanceTx      [MOD]
    ├── stm32wlxx_hal_conf.h.patch Habilita HAL_I2C_MODULE_ENABLED         [MOD]
    └── dot_project.patch         Recursos enlazados (.c + driver I2C)     [MOD]
```

---

## Hardware / cableado

Sensor **VL53L0X** (ToF, registros de 8 bits, WHO_AM_I `0xC0 = 0xEE`) por **I2C2**:

| Señal sensor | Pin Nucleo | Header |
|---|---|---|
| SCL | **PA12** | Arduino D15 ("SCL") |
| SDA | **PA11** | Arduino D14 ("SDA") |
| VIN | 3.3 V | |
| GND | GND | |
| XSHUT | 3.3 V | (habilita el sensor) |

Pull-ups **4.7 kΩ a 3.3 V** en SDA y SCL. Se usó PA11/PA12 porque **PB7 (D0) está cargado por el ST-LINK**.

> El multiplexor **PCA9548A** (para 2 sensores) resultó **dañado**; este programa corre con **un sensor directo** (`DIST_DIRECT_ONE_SENSOR=1`). El soporte de mux queda en el código para reactivarlo.

---

## Cómo funciona

- Driver **VL53L0X propio y autocontenido** (`vl53l0x.c`): init estándar (config 2.8 V, SPAD, tuning, calibración de referencia, presupuesto de medición) + lectura por **disparo único**.
- `distance_app` muestrea cada 5 s y decide **puerta**:
  - CERRADA si distancia `< DIST_NEAR_MM` (45 mm)
  - ABIERTA si distancia `> DIST_FAR_MM` (60 mm)
  - banda `[NEAR, FAR]` = **histéresis** (no rebota en el límite).
- **Envío solo por cambio de estado** (sin periodicidad); tope diario `DIST_MAX_TX_PER_DAY` (100).

### Parámetros (`distance_app.h`)
```c
#define DIST_USE_VL53L0X        1     // usa el driver L0X (8 bits)
#define DIST_DIRECT_ONE_SENSOR  1     // sin mux (1 sensor directo)
#define DIST_PAYLOAD_MODE       DIST_MODE_FLAGS
#define DIST_NEAR_MM            45U   // < 45 mm -> CERRADA
#define DIST_FAR_MM            60U    // > 60 mm -> ABIERTA
#define DIST_SAMPLE_MS         5000U  // muestreo
#define DIST_HEARTBEAT_MS      0U     // solo evento
```
El VL53L0X trae offset de fábrica → para mm exactos requiere calibración; para umbral/puerta no importa. **Ajusta NEAR/FAR según lo que veas en el log** de tu montaje.

---

## Payload Sigfox

Modo FLAGS → **1 byte**: `bit0` = sensor A cerca/CERRADA, `bit1` = sensor B.
(`0x00` abierta, `0x01` cerrada.)

---

## Integración y compilación

1. Copiar de `src/`: `app_features.h`, `i2c.h` → `Core/Inc`; `i2c.c` → `Core/Src`; `distance_app.*`, `vl53l0x.*`, `vl53l1_platform.*` → `Sigfox/App`.
2. Aplicar los `.patch` (`sgfx_app.c`, `utilities_def.h`, `stm32wlxx_hal_conf.h`, `.project`).
3. En `app_features.h`: `USE_DISTANCE_APP=1` (y las demás en 0).
4. Cerrar/reabrir el proyecto → Clean → Build → flash.

---

## Notas / aprendizajes

- El chip es **VL53L0X (8 bits)**, no L1X (leerlo en 16 bits daba `0x0F01`).
- **I2C no sobrevive STOP2** → `distance_app` bloquea el modo STOP mientras corre (`UTIL_LPM_SetStopMode`).
- Conectar **XSHUT a 3.3V** o el sensor no arranca.

---
*0G IoT Solutions (previamente WND México) — https://0giotsolutions.com/*

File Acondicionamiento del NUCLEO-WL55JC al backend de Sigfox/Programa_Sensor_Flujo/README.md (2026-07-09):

# Programa Sensor de Flujo — YF-S201 (NUCLEO-WL55JC → Sigfox)

Añade al firmware `Sigfox_AT_Slave` V1.5.0 la medición de un **sensor de flujo de efecto Hall (YF-S201, 1-30 L/min)** como **totalizador de volumen**, con envío Sigfox del total acumulado. Pensado para **caracterización** (log por Vcom) y para reporte a backend. Mantiene en paralelo la interfaz AT.

Backend Sigfox de **0G IoT Solutions** (previamente WND México) — https://0giotsolutions.com/

---

## Contenido de la carpeta

```
Programa_Sensor_Flujo/
├── README.md
└── src/
    ├── app_features.h        Selector de apps (feature flags)          [NUEVO -> Core/Inc]
    ├── flow_app.h / .c       Lógica del sensor de flujo                [NUEVO -> Sigfox/App]
    ├── sgfx_app.c.patch      Llamada Flow_Init() en Sigfox_Init()      [MOD]
    ├── utilities_def.h.patch ID de tarea CFG_SEQ_Task_FlowTx           [MOD]
    └── dot_project.patch     Recurso enlazado (flow_app.c)             [MOD]
```

---

## Hardware / cableado

El YF-S201 tiene una turbina cuyo Hall genera un **tren de pulsos** cuya frecuencia es proporcional al caudal.

| Cable sensor | Pin Nucleo | Nota |
|---|---|---|
| Señal (amarillo) | **PB8 / D5** | open-collector → pull-up **10k a 3.3V** |
| VCC (rojo) | **5 V** | el sensor requiere 5 V |
| GND (negro) | GND | |
| Botón externo | **PB5 / D4** | pull-up + cierre a GND (uplink manual) |

---

## Cómo funciona

- Cuenta pulsos por **interrupción (EXTI)**; cada 1 s calcula **frecuencia (Hz) → caudal (L/min)** y acumula **volumen total (totalizador)**.
- Relación típica YF-S201: `F(Hz) = 7.5 × Q(L/min)` ≈ **450 pulsos/litro** (verificar en caracterización).
- **Envío (totalizador):**
  - Automático: un uplink **cada `FLOW_UPLINK_LITERS` (10 L)** acumulados.
  - Manual: **botón** → envía el total actual sin reiniciar (con `FLOW_BTN_TX=1`).
  - El total es **acumulativo** y no se reinicia → robusto ante mensajes perdidos.

### Parámetros (`flow_app.h`)
```c
#define FLOW_PULSES_PER_LITER 450U   // K típico. AJUSTAR por caracterización con agua
#define FLOW_WINDOW_MS        1000U
#define FLOW_UPLINK_LITERS    10U    // uplink cada 10 L
#define FLOW_TX_ENABLE        1
#define FLOW_BTN_TX           0/1    // 1 = boton fuerza uplink del total actual
```

### Caracterización (con agua)
Pasar volúmenes conocidos, leer `pulsos`, calcular `K = pulsos / litro`, ajustar `FLOW_PULSES_PER_LITER` y verificar linealidad en 1-30 L/min.

Salida por Vcom (115200):
```
[FLOW] f=84 Hz  Q=11200 mL/min (11.20 L/min)  Vol=20177 mL  pulsos=9080  btn=0
[FLOW] >> UPLINK (10 L) total=20177 mL (20.177 L)  caudal=11200 mL/min
```

---

## Payload Sigfox (6 de 12 bytes)

```
byte 0..3 : volumen total acumulado en mL (uint32, big-endian)
byte 4..5 : caudal instantáneo en mL/min  (uint16, big-endian)
```
Decodificación backend: `litros = bytes[0..3] / 1000`, `L/min = bytes[4..5] / 1000`.
**Ejemplo:** `000027626ef0` → `0x2762 = 10082 mL = 10.082 L` y `0x6EF0 = 28400 mL/min = 28.4 L/min`.

> Sigfox: máx 12 bytes, ~140 msg/día → con 10 L/uplink cubres ~1400 L/día. Sube `FLOW_UPLINK_LITERS` para caudales altos. Quedan 6 bytes libres (batería, flags, contador de resets).

---

## Integración y compilación

1. Copiar de `src/`: `app_features.h` → `Core/Inc`; `flow_app.*` → `Sigfox/App`.
2. Aplicar los `.patch` (`sgfx_app.c`, `utilities_def.h`, `.project`).
3. En `app_features.h`: `USE_FLOW_APP=1` (y las demás en 0, en especial `USE_BUTTONS_APP=0`, ver nota EXTI).
4. Cerrar/reabrir el proyecto → Clean → Build → flash.

---

## Notas / aprendizajes

- `flow_app.c` define su **propio `EXTI9_5_IRQHandler` + `HAL_GPIO_EXTI_Callback`** (pulsos + botón) → **no activar junto con `buttons_app`** (colisión de handlers).
- **Brown-out por energía:** el pico del TX Sigfox (o un corto por mal cableado del botón a una salida de voltaje) hunde el VDD → reset. Mitigación: fuente sólida + **capacitores de bulk (100–470 µF + 100 nF)** en 3.3V/5V y GND firme.
- El total está en **RAM** → se pierde en un reset. Pendiente: **persistencia en EEPROM** para un totalizador real.

---
*0G IoT Solutions (previamente WND México) — https://0giotsolutions.com/*

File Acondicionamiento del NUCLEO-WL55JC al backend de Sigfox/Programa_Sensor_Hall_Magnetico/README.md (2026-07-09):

# Programa Sensor Hall Magnético + Botón (NUCLEO-WL55JC → Sigfox)

Añade al firmware `Sigfox_AT_Slave` V1.5.0 la lectura de un **sensor Hall magnético** (tipo puerta: imán presente / ausente) y un **botón externo**, ambos con **filtro RC por hardware (10k + 1nF)**, con envío Sigfox **solo por evento**. Mantiene en paralelo la interfaz AT.

Backend Sigfox de **0G IoT Solutions** (previamente WND México) — https://0giotsolutions.com/

---

## Contenido de la carpeta

```
Programa_Sensor_Hall_Magnetico/
├── README.md
└── src/
    ├── app_features.h        Selector de apps (feature flags)          [NUEVO -> Core/Inc]
    ├── hall_app.h / .c       Lógica Hall + botón                       [NUEVO -> Sigfox/App]
    ├── sgfx_app.c.patch      Llamada Hall_Init() en Sigfox_Init()      [MOD]
    ├── utilities_def.h.patch ID de tarea CFG_SEQ_Task_HallTx           [MOD]
    └── dot_project.patch     Recurso enlazado (hall_app.c)             [MOD]
```

---

## Hardware / cableado

Dos entradas digitales, cada una con filtro RC (10k a 3.3V + 1nF a GND; el sensor/botón cierra a GND → reposo ALTO, activo en BAJO):

| Entrada | Pin Nucleo | Header |
|---|---|---|
| Sensor Hall (salida) | **PB8** | Arduino D5 |
| Botón externo | **PB5** | Arduino D4 |

> El filtro RC (`fc ≈ 16 kHz`) filtra ruido/EMI y limpia flancos; el rebote mecánico lo termina el debounce por software.

---

## Cómo funciona

- Sondeo cada **200 ms** (`hall_app`), con debounce por software (2 lecturas coincidentes).
- **Envío solo por cambio de estado** (sin periodicidad); tope diario `HALL_MAX_TX_PER_DAY` (100).
- Activo en bajo por defecto (`HALL_ACTIVE_LOW=1`).

### Parámetros (`hall_app.h`)
```c
#define HALL_Pin            GPIO_PIN_8   // PB8 / D5
#define BTN_EXT_Pin         GPIO_PIN_5   // PB5 / D4
#define HALL_SAMPLE_MS      200U
#define HALL_MAX_TX_PER_DAY 100U
```

---

## Payload Sigfox

**1 byte**: `bit0` = Hall (imán presente / puerta CERRADA), `bit1` = botón presionado.
(`0x00` abierta/suelto, `0x01` cerrada, `0x02` botón, `0x03` ambos.)

---

## Integración y compilación

1. Copiar de `src/`: `app_features.h` → `Core/Inc`; `hall_app.*` → `Sigfox/App`.
2. Aplicar los `.patch` (`sgfx_app.c`, `utilities_def.h`, `.project`).
3. En `app_features.h`: `USE_HALL_APP=1` (y las demás en 0).
4. Cerrar/reabrir el proyecto → Clean → Build → flash.

---

## Notas

- Usa **sondeo** (no EXTI) → sin conflicto con otros handlers y compatible con bajo consumo (solo GPIO).
- **PB5 (D4):** cablear con cuidado; un mal cableado a una salida de voltaje provoca corto → *brown-out* → reinicio.

---
*0G IoT Solutions (previamente WND México) — https://0giotsolutions.com/*

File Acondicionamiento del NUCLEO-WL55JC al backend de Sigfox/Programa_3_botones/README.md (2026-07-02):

# Programa de los 3 botones — Envío Sigfox por push-button

Documentación técnica del código que añade envíos Sigfox disparados por los botones **B1**, **B2** y **B3** de la placa **NUCLEO-WL55JC**, manteniendo en paralelo la interfaz AT del firmware `Sigfox_AT_Slave` V1.5.0.

- **B1 (PA0)** → payload `"Hola"` = hex `48 6F 6C 61` (4 bytes)
- **B2 (PA1)** → payload `"Mundo"` = hex `4D 75 6E 64 6F` (5 bytes)
- **B3 (PC6)** → payload `"0G"` = hex `30 47` (2 bytes)

Al presionar los 3 botones en secuencia se forma la frase **"Hola Mundo 0G"** — demo end-to-end del backend Sigfox operado por **0G IoT Solutions**.

---

## Contenido

- [Arquitectura general](#arquitectura-general)
- [Mapa de pines](#mapa-de-pines)
- [Flujo de ejecución paso a paso](#flujo-de-ejecución-paso-a-paso)
- [Debounce, rate-limit y feedback visual](#debounce-rate-limit-y-feedback-visual)
- [Archivos nuevos](#archivos-nuevos)
- [Archivos modificados y por qué](#archivos-modificados-y-por-qué)
- [Cómo compilar](#cómo-compilar)
- [Cómo probar](#cómo-probar)
- [Interacción con la interfaz AT](#interacción-con-la-interfaz-at)
- [Notas de bajo consumo](#notas-de-bajo-consumo)

---

## Arquitectura general

El diseño sigue el patrón oficial del SDK **STM32CubeWL** con **stm32_seq** (sequencer cooperativo de bajo consumo). El flujo de un click es:

```
┌────────────┐  presión física
│   BOTÓN    │──────────────┐
│  (Bx)      │              │
└────────────┘              ▼
                   ┌──────────────────────┐
                   │  EXTI0/EXTI1/EXTI9_5 │ ISR corta
                   │  IRQ Handler         │ (~microsegundos)
                   └──────────┬───────────┘
                              │
                              ▼
                   ┌──────────────────────┐
                   │ HAL_GPIO_EXTI_       │ limpia pending bit
                   │ Callback()           │ delega en app
                   └──────────┬───────────┘
                              │
                              ▼
                   ┌──────────────────────┐
                   │ Buttons_HandleEXTI() │ debounce SW
                   │ [contexto ISR]       │ setea pendingButton
                   └──────────┬───────────┘
                              │
                              ▼
                   ┌──────────────────────┐
                   │ UTIL_SEQ_SetTask()   │ marca tarea pendiente
                   │ (retorna a main loop)│
                   └──────────┬───────────┘
                              │
              ═══════════════ ISR termina ═══════════════
                              │
                              ▼
                   ┌──────────────────────┐
                   │ Buttons_Process()    │ CONTEXTO MAIN LOOP
                   │ (sequencer task)     │ Verifica rate-limit
                   └──────────┬───────────┘
                              │
                              ▼
                   ┌──────────────────────┐
                   │ SIGFOX_API_send_     │ Bloquea ~6 s
                   │ frame()              │ TX1/TX2/TX3 en 902 MHz
                   └──────────┬───────────┘
                              │
                              ▼
                   ┌──────────────────────┐
                   │ LEDs + log en VCP    │ Feedback visual
                   └──────────────────────┘
```

**Principio clave:** la ISR **NO** llama directamente a `SIGFOX_API_send_frame()`. Esa función bloquea ~6 segundos mientras la radio transmite las 3 réplicas — hacerlo en contexto ISR bloquearía el resto del sistema. En su lugar, la ISR sólo _marca_ que hay una TX pendiente y retorna. El main loop, vía el sequencer `stm32_seq`, ejecuta la TX en contexto de usuario.

---

## Mapa de pines

Verificado desde `Core/Inc/main.h` del proyecto:

| Función | Pin MCU | EXTI line | ISR handler |
|---|---|---|---|
| Botón B1 | PA0 | EXTI0 | `EXTI0_IRQHandler` |
| Botón B2 | PA1 | EXTI1 | `EXTI1_IRQHandler` |
| Botón B3 | PC6 | EXTI6 (grupo [5:9]) | `EXTI9_5_IRQHandler` |
| LED azul LD1 | PB15 | — | (output) |
| LED verde LD2 | PB9 | — | (output) |
| LED rojo LD3 | PB11 | — | (output) |

Los 3 botones ya venían **configurados** desde el `gpio.c` del proyecto original (`GPIO_MODE_IT_FALLING` + `GPIO_PULLUP`). Lo que faltaba —y que el código nuevo agrega— es habilitar las NVIC interrupts, escribir los handlers, y la lógica de aplicación.

---

## Flujo de ejecución paso a paso

### 1. Inicialización (una sola vez, al boot)

En `Sigfox_Init()` de `sgfx_app.c` se agrega la llamada a `Buttons_Init()`. Dentro se ejecuta:

```c
void Buttons_Init(void)
{
  /* Apaga los 3 LEDs */
  LED_BUSY_OFF(); LED_OK_OFF(); LED_ERR_OFF();

  /* Habilita NVIC para las 3 lineas EXTI */
  HAL_NVIC_SetPriority(EXTI0_IRQn, 5, 0);   HAL_NVIC_EnableIRQ(EXTI0_IRQn);
  HAL_NVIC_SetPriority(EXTI1_IRQn, 5, 0);   HAL_NVIC_EnableIRQ(EXTI1_IRQn);
  HAL_NVIC_SetPriority(EXTI9_5_IRQn, 5, 0); HAL_NVIC_EnableIRQ(EXTI9_5_IRQn);

  /* Registra la tarea del sequencer */
  UTIL_SEQ_RegTask((1U << CFG_SEQ_Task_ButtonTx), UTIL_SEQ_RFU, Buttons_Process);

  APP_PPRINTF("BOTONES LISTOS: B1=Hola  B2=Mundo  B3=0G\r\n");
}
```

**Prioridad NVIC 5:** intermedia. No pisa al radio Sigfox (que corre en prioridades más altas, típicamente 0-3) y garantiza que la ISR se ejecute rápido después de una presión.

### 2. Presión del botón (evento asíncrono)

Cuando el usuario presiona físicamente un botón:

1. La línea EXTI genera IRQ.
2. El **NVIC** llama al handler correspondiente en `stm32wlxx_it.c`:

   ```c
   void EXTI0_IRQHandler(void) {  HAL_GPIO_EXTI_IRQHandler(BUT1_Pin);  }
   ```

3. `HAL_GPIO_EXTI_IRQHandler()` (de HAL, no lo escribimos nosotros):
   - Limpia el pending bit de EXTI.
   - Llama a la función `__weak` `HAL_GPIO_EXTI_Callback(GPIO_Pin)`.

4. Nuestro override de `HAL_GPIO_EXTI_Callback()` (también en `stm32wlxx_it.c`):

   ```c
   void HAL_GPIO_EXTI_Callback(uint16_t GPIO_Pin) {
     Buttons_HandleEXTI(GPIO_Pin);
   }
   ```

5. `Buttons_HandleEXTI()` (en `buttons_app.c`):

   ```c
   void Buttons_HandleEXTI(uint16_t GPIO_Pin)
   {
     uint32_t now = HAL_GetTick();

     /* --- Debounce software --- */
     if ((now - lastIsrTick) < BTN_DEBOUNCE_MS) return;
     lastIsrTick = now;

     /* --- Mapea pin a ID --- */
     ButtonId_t btn = BTN_NONE;
     if (GPIO_Pin == BUT1_Pin)      btn = BTN_B1;
     else if (GPIO_Pin == BUT2_Pin) btn = BTN_B2;
     else if (GPIO_Pin == BUT3_Pin) btn = BTN_B3;
     if (btn == BTN_NONE) return;

     /* --- Set flag + agenda tarea --- */
     if (pendingButton == BTN_NONE) {
       pendingButton = btn;
       UTIL_SEQ_SetTask((1U << CFG_SEQ_Task_ButtonTx), CFG_SEQ_Prio_0);
     }
   }
   ```

   Puntos clave:

   - **Debounce por software:** si dos ISR llegan en < 200 ms, se descarta la segunda. Los pulsadores mecánicos rebotan varios milisegundos al cierre — sin debounce, un solo click podría ser leído como 2-3 pulsaciones y disparar múltiples uplinks (**cada uno consume 1 token del contrato Sigfox**).
   - **Descartar dobles:** si `pendingButton` ya tiene un ID, no se sobreescribe. La primera pulsación gana.
   - **No hay `printf` ni operaciones largas** en la ISR — solo comparaciones y una asignación atómica.

6. `UTIL_SEQ_SetTask()` marca el bit correspondiente al `CFG_SEQ_Task_ButtonTx` en un bitmask global del sequencer. La ISR termina inmediatamente y el MCU vuelve al main loop.

### 3. Ejecución de la tarea (contexto main loop)

En el ciclo `while(1)` de `main.c` se llama continuamente a `MX_Sigfox_Process()`, que a su vez llama a `UTIL_SEQ_Run(UTIL_SEQ_DEFAULT)`. Éste chequea el bitmask, ve que `CFG_SEQ_Task_ButtonTx` está pendiente y ejecuta `Buttons_Process()`:

```c
static void Buttons_Process(void)
{
  ButtonId_t btn = pendingButton;
  pendingButton = BTN_NONE;                 /* Listo para el siguiente click */
  if (btn == BTN_NONE) return;

  /* --- Rate limit --- */
  uint32_t now = HAL_GetTick();
  if (lastTxTick != 0U && (now - lastTxTick) < BTN_RATE_LIMIT_MS) {
    APP_PPRINTF("[BTN] Rate limit activo. Faltan %u ms\r\n",
                (unsigned)(BTN_RATE_LIMIT_MS - (now - lastTxTick)));
    Buttons_BlinkBlue(6);                   /* Feedback: 6 parpadeos rapidos */
    return;
  }

  Buttons_SendPayload(btn);
}
```

**Rate limit:** rechaza el envío si han pasado menos de **30 segundos** desde el último uplink exitoso. Diseño intencional: cada uplink consume un token del contrato Sigfox `UnaTag_test` (recordar el budget limitado del device de laboratorio). El rate limit previene el gasto masivo si alguien presiona en ráfaga.

### 4. Envío efectivo

`Buttons_SendPayload()` es donde se llama al stack Sigfox:

```c
static void Buttons_SendPayload(ButtonId_t button)
{
  const uint8_t *payload; uint8_t length; const char *label;

  switch (button) {
    case BTN_B1: payload = PAYLOAD_B1; length = 4; label = "B1 = Hola";  break;
    case BTN_B2: payload = PAYLOAD_B2; length = 5; label = "B2 = Mundo"; break;
    case BTN_B3: payload = PAYLOAD_B3; length = 2; label = "B3 = 0G";    break;
    default: return;
  }

  APP_PPRINTF("[BTN] >> TX %s (%u bytes)\r\n", label, length);
  LED_OK_OFF(); LED_ERR_OFF();
  LED_BUSY_ON();                                     /* LED rojo durante TX */

  uint8_t dl_msg[8] = {0};
  sfx_error_t err = SIGFOX_API_send_frame(
      (sfx_u8*)payload,
      (sfx_u8)length,
      dl_msg,
      (sfx_u8)BTN_TX_REPLICAS,                       /* 1 replica */
      SFX_FALSE                                      /* Sin downlink request */
  );

  LED_BUSY_OFF();

  if (err == SFX_ERR_NONE) {
    LED_OK_ON();                                     /* LED verde */
    lastTxTick = HAL_GetTick();                      /* Arranca rate-limit */
    APP_PPRINTF("[BTN] << TX OK\r\n");
    HAL_Delay(BTN_LED_OK_HOLD_MS);
    LED_OK_OFF();
  } else {
    LED_ERR_ON();                                    /* LED azul */
    APP_PPRINTF("[BTN] << TX ERROR 0x%04X\r\n", err);
    HAL_Delay(BTN_LED_ERR_HOLD_MS);
    LED_ERR_OFF();
  }
}
```

Payloads como constantes en `.rodata` (no ocupan RAM):

```c
static const uint8_t PAYLOAD_B1[] = { 0x48, 0x6F, 0x6C, 0x61 };          /* "Hola" */
static const uint8_t PAYLOAD_B2[] = { 0x4D, 0x75, 0x6E, 0x64, 0x6F };    /* "Mundo" */
static const uint8_t PAYLOAD_B3[] = { 0x30, 0x47 };                       /* "0G" */
```

---

## Debounce, rate-limit y feedback visual

| Parámetro | Valor default | Símbolo (buttons_app.h) | Rationale |
|---|---|---|---|
| Debounce ISR | 200 ms | `BTN_DEBOUNCE_MS` | Suprime rebotes mecánicos y triple-click accidental. |
| Rate limit entre TX | 30 s | `BTN_RATE_LIMIT_MS` | Presupuesto de tokens Sigfox (contrato `UnaTag_test` limitado). |
| Réplicas TX | 1 | `BTN_TX_REPLICAS` | Uplinks de bajo costo. Aumentar a 3 para link más robusto (consume 1 token igual, pero más energía). |
| LED verde tras TX OK | 3 s | `BTN_LED_OK_HOLD_MS` | Confirmación visual, evita duda del operador. |
| LED azul tras TX ERR | 3 s | `BTN_LED_ERR_HOLD_MS` | Idem para error. |

**Codificación de LEDs:**

| LED | Pin | Color | Significa |
|---|---|---|---|
| LD3 | PB11 | Rojo | TX en curso (radio activo) |
| LD2 | PB9 | Verde | TX OK — mensaje aceptado por el stack |
| LD1 | PB15 | Azul | TX error o rate-limit rechazado (6 parpadeos rápidos si es rate-limit) |

---

## Archivos nuevos

### `Sigfox/App/buttons_app.h`

API pública del módulo. Solo declara `Buttons_Init()` y `Buttons_HandleEXTI()`. Ver [`src/buttons_app.h`](src/buttons_app.h) para el contenido completo.

### `Sigfox/App/buttons_app.c`

Implementación completa: init, ISR handler, tarea del sequencer, send payload, blink azul. **Único archivo con lógica de aplicación nueva.** Ver [`src/buttons_app.c`](src/buttons_app.c).

---

## Archivos modificados y por qué

Se hicieron 4 modificaciones puntuales en archivos existentes del SDK. Cada una está documentada con su diff conceptual en la carpeta `src/`:

| Archivo | Cambio | Motivo | Diff |
|---|---|---|---|
| `Core/Inc/utilities_def.h` | +1 línea en enum de tareas del sequencer | Registrar `CFG_SEQ_Task_ButtonTx` para poder invocar `UTIL_SEQ_SetTask()` desde la ISR | [`utilities_def.h.patch`](src/utilities_def.h.patch) |
| `Core/Src/stm32wlxx_it.c` | +37 líneas: 3 EXTI handlers + `HAL_GPIO_EXTI_Callback` | El proyecto original NO tenía handlers para EXTI0/1/9_5. Sin ellos, la IRQ dispararía el `Default_Handler` (loop infinito) | [`stm32wlxx_it.c.patch`](src/stm32wlxx_it.c.patch) |
| `Sigfox/App/sgfx_app.c` | 2 líneas: `#include "buttons_app.h"` + llamada a `Buttons_Init()` | Enganchar el módulo al ciclo de inicialización oficial del stack Sigfox | [`sgfx_app.c.patch`](src/sgfx_app.c.patch) |
| `STM32CubeIDE/.project` | +5 líneas: `<link>` a `buttons_app.c` | STM32CubeIDE usa **linked resources**; sin este entry, el `.c` no entra al build (linker tira "undefined reference to Buttons_Init") | [`dot_project.patch`](src/dot_project.patch) |

> **Nota importante:** todos los cambios se realizaron dentro de bloques `USER CODE BEGIN` / `USER CODE END` de CubeMX/CubeIDE. Esto significa que **si en el futuro se regenera el proyecto desde el `.ioc` de CubeMX, las modificaciones se preservan**. Es una práctica obligatoria para no perder trabajo custom al re-generar código.

---

## Cómo compilar

Con el proyecto abierto en STM32CubeIDE:

1. Confirmar que en Project Explorer aparece `buttons_app.c` bajo:
   `Sigfox_AT_Slave/Application/User/Sigfox/App/`
   Si no aparece → click derecho en el proyecto → **Refresh** (F5).
2. Click derecho sobre `Sigfox_AT_Slave` → **Clean Project**.
3. Click derecho → **Build Project** (o `Cmd+B`).

**Salida esperada:**

```
arm-none-eabi-size Sigfox_AT_Slave.elf
   text    data     bss     dec     hex   filename
  ~77500    312    ~10550  ~88K   16XXX   Sigfox_AT_Slave.elf

Build Finished. 0 errors, X warnings.
```

Los `X warnings` son cosméticos del SDK (encoding, unused variable en `lora_at.c` de otra región). Ignorables.

**El firmware compilado queda en:**

```
STM32CubeIDE/Debug/Sigfox_AT_Slave.elf
```

---

## Cómo probar

### 1. Flashear el firmware nuevo

Con STM32CubeProgrammer (o `STM32_Programmer_CLI`):

- Mode: `Under reset` · Reset mode: `Hardware reset` · Connect.
- Erasing & Programming → Browse → `Sigfox_AT_Slave.elf`.
- ✓ Verify programming · ✓ Run after programming · ☐ Skip flash erase.
- Start Programming.

> **⚠️ Credenciales Sigfox:** el fix del linker documentado en la carpeta `Persistencia_Credenciales_NOLOAD/` garantiza que este flasheo **no borre** las credenciales `sigfox_data_<ID>.bin` en `0x0803E500`. Si es la primera vez que flasheas este firmware sobre un chip que aún tenía credenciales TEST, tienes que hacer un `Write data` con el `.bin` real del portal sfxp primero. Ver README de esa carpeta.

### 2. Abrir Serial Monitor

Configuración: **9600 baud · Carriage return · sin flow control**.

**Boot banner esperado:**

```
APPLICATION_VERSION: V1.5.0
MW_SIGFOX_VERSION:   V1.8.0
MW_RADIO_VERSION:    V1.4.0
ATtention command interface

SIGFOX APPLICATION READY

BOTONES LISTOS:
  B1 (PA0) --> Hola  (48 6F 6C 61)
  B2 (PA1) --> Mundo (4D 75 6E 64 6F)
  B3 (PC6) --> 0G    (30 47)
  Debounce: 200 ms  |  Rate limit: 30 s
```

Si aparece **`BOTONES LISTOS`**, el módulo se compiló y se ejecutó correctamente.

### 3. Probar cada botón

Con el device previamente registrado en `backend.sigfox.com`:

1. Presionar **B1** → esperar ~6 s.
2. En el Serial Monitor debe aparecer:
   ```
   [BTN] >> TX B1 = Hola (4 bytes)
   [BTN] << TX OK
   ```
3. En backend Sigfox → **Messages**: aparece nueva fila con payload `486f6c61` en 2-30 s.
4. Esperar **30 segundos** (rate limit).
5. Presionar **B2** → verificar `4d756e646f`.
6. Esperar 30 s. Presionar **B3** → verificar `3047`.

Los 3 mensajes juntos forman la frase **"Hola Mundo 0G"** en el backend.

### 4. Comportamientos secundarios a probar

- **Doble-click rápido en el mismo botón (< 200 ms):** solo debe llegar 1 mensaje al backend (debounce funcionando).
- **Segundo click antes de 30 s desde el primero:** LED azul parpadea 6 veces, Serial imprime `[BTN] Rate limit activo. Faltan XXXX ms`, NO se envía.
- **Comandos AT sin presionar botón:** siguen funcionando en paralelo (`AT`, `AT$ID`, `AT$SF=...`), ver siguiente sección.

---

## Interacción con la interfaz AT

**El módulo de botones NO reemplaza la interfaz AT.** Ambos coexisten:

- La ISR de UART sigue registrada y escuchando comandos.
- La tarea `CFG_SEQ_Task_Vcom` sigue registrada y procesando comandos AT en el main loop.
- La nueva tarea `CFG_SEQ_Task_ButtonTx` se ejecuta en paralelo (no simultáneamente — el sequencer es cooperativo, pero ambas tareas alternan cuando corresponde).

**Casos típicos:**

- Enviar `AT$SF=48656C6C6F` por Serial → envía "Hello" (5 bytes).
- Presionar B1 → envía "Hola" (4 bytes).
- Los dos canales comparten el mismo device ID, KEY, región RC2, y el mismo budget de tokens del contrato Sigfox.

**No debes:** llamar `SIGFOX_API_send_frame()` desde AT mientras un envío por botón está en curso. El stack Sigfox es single-threaded en cuanto al radio. En la práctica, dado que ambos canales atraviesan `SIGFOX_API_send_frame()` en la misma capa de aplicación y el radio se turna via sequencer, no hay condición de carrera si el usuario espera el `OK` de una operación antes de disparar la siguiente.

---

## Notas de bajo consumo

El proyecto original `Sigfox_AT_Slave` usa **stm32_lpm** (Low Power Manager) para poner al MCU en modo **STOP** entre eventos. Esto es lo que causa el mensaje `Warning: Connection to device is lost` en CubeProgrammer post-flasheo — el MCU se durmió y las patas SWD se apagaron.

**Los botones despiertan al MCU correctamente** porque:

1. Las líneas EXTI0/EXTI1/EXTI9_5 son **wakeup-capable** en STM32WL: cualquier IRQ EXTI configurada saca al chip de STOP y ejecuta la ISR normalmente.
2. En particular, **PA0 corresponde a `WAKEUP1`**, uno de los pines más eficientes para wakeup en STM32WL.
3. Después de ejecutar la tarea (`Buttons_Process()` + `SIGFOX_API_send_frame`), el sequencer devuelve control al `MX_Sigfox_Process()` que vuelve a permitir modo bajo consumo hasta el próximo evento.

**Consecuencia:** el firmware es apto para operación con batería. En idle, consumo típico STM32WL55JC en STOP2 con RTC = ~2-5 µA (según datasheet). Durante un TX Sigfox: pico de ~90 mA por ~1.5 s totales (3 réplicas de 500 ms cada una), lo cual promedia bien para presiones ocasionales.

---

## Referencias

- Guía completa (PDF, 29 páginas): [`../Guia_completa.pdf`](../Guia_completa.pdf)
- Fix del linker que protege credenciales al re-flashear: [`../Persistencia_Credenciales_NOLOAD/`](../Persistencia_Credenciales_NOLOAD/)
- ST **AN5480 Rev 8** — How to build a Sigfox application with STM32CubeWL
- ST **UM2609** — STM32CubeIDE user guide (Modificar linker script)
- ST **UM2592** — NUCLEO-WL55JC (MB1389) hardware manual

---

**Autor:** Yahir Flores — `yflores@iotnet.mx`
**Empresa:** 0G IoT Solutions (previamente WND México) — [0giotsolutions.com](https://0giotsolutions.com/)
**Versión:** 1.0 · Julio 2026

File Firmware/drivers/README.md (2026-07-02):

# Drivers

Drivers de bajo nivel para los sensores del 0G LockControl LSM110A.

## Archivos

| Archivo | Sensor | Pin | Funcion |
|---|---|---|---|
| `lis2dw12.c/.h` | Acelerometro LIS2DW12 | PA0 (INT1) + PA9/PA10 (I2C1) | Wake-up por movimiento |
| `reed_switch.c/.h` | Reed switch / DRV5032 | PA1 (EXTI1) | Apertura puerta |

---

## Uso conjunto — patron ISR + main loop

Ambos drivers siguen el mismo patron:
1. Una funcion `*_on_interrupt()` se llama desde el callback EXTI (contexto ISR, sin I/O).
2. Una funcion `*_process_event()` se llama desde el main loop para leer registros / pines y decidir si transmitir.

### 1. Configurar pines en CubeMX (.ioc del proyecto SDK)

| Pin | Modo | Pull | EXTI |
|---|---|---|---|
| PA0 | GPIO_EXTI0 | Pull-down | Rising edge |
| PA1 | GPIO_EXTI1 | Pull-up | Both edges  |
| PA9 | I2C1_SCL | None | — |
| PA10 | I2C1_SDA | None | — |

Habilitar `EXTI Line0 interrupt` y `EXTI Line1 interrupt` en NVIC con prioridad media (ej. 5).
Habilitar `I2C1` en Fast Mode (400 kHz).

### 2. En `app_sigfox.c` (o `main.c` segun donde manejes la app)

```c
#include "lis2dw12.h"
#include "reed_switch.h"

extern I2C_HandleTypeDef hi2c1;

static lis2dw12_t   g_accel;
static reed_switch_t g_reed;

void app_sensors_init(void)
{
    /* Acelerometro */
    lis2dw12_init_handle(&g_accel, &hi2c1);

    uint8_t id = 0;
    if (lis2dw12_who_am_i(&g_accel, &id) != LIS2DW12_OK) {
        /* I2C roto o chip no responde 0x44 */
        Error_Handler();
    }
    lis2dw12_config_wakeup(&g_accel, 200);   /* 200 mg default */

    /* Reed switch */
    reed_switch_init(&g_reed, GPIOA, GPIO_PIN_1, 50);  /* 50 ms debounce */
}

void app_sensors_poll(void)
{
    /* Eventos del acelerometro */
    if (lis2dw12_has_pending_event(&g_accel)) {
        lis2dw12_event_t evt;
        if (lis2dw12_process_event(&g_accel, &evt) == LIS2DW12_OK
            && evt.detected) {
            /* TODO: armar payload con bit0 = 1 (accel) y enviar Sigfox */
        }
    }

    /* Eventos del reed switch */
    if (reed_switch_has_pending_event(&g_reed)) {
        reed_state_t st;
        reed_switch_process_event(&g_reed, &st);
        /* TODO: armar payload con bit1 = 1 (magnetico) y estado st */
    }
}
```

### 3. En `stm32wlxx_it.c` o donde tengas el callback EXTI

El HAL provee un weak `HAL_GPIO_EXTI_Callback(uint16_t GPIO_Pin)`. Override en
**un solo lugar** del proyecto. Sugerido: en `app_sigfox.c` o en un nuevo
`event_dispatch.c` colgando de `Application/User/`.

```c
extern lis2dw12_t   g_accel;
extern reed_switch_t g_reed;

void HAL_GPIO_EXTI_Callback(uint16_t GPIO_Pin)
{
    if (GPIO_Pin == GPIO_PIN_0) {
        lis2dw12_on_interrupt(&g_accel);
    }
    else if (GPIO_Pin == GPIO_PIN_1) {
        reed_switch_on_interrupt(&g_reed);
    }
}
```

### 4. En el main loop (o stm32_seq task)

Llamar `app_sensors_poll()` periodicamente, o despues de salir de Stop2 por
EXTI. Si usas el scheduler del SDK (`stm32_seq.h`), registra `app_sensors_poll`
como una tarea y dispara `UTIL_SEQ_SetTask` desde el callback EXTI.

---

## Integracion al proyecto CubeIDE del SDK

El SDK SJI vive en `~/GitHub/LSM110A`. El proyecto Eclipse esta en:

```
Projects/NUCLEO-WL55JC/Applications/LoRaWAN_SigFox/LSM1x0A/STM32CubeIDE/
```

Pasos para sumar estos drivers al proyecto:

1. En CubeIDE, click derecho sobre el proyecto -> `New` -> `Folder`.
   Nombrelo `drivers` colgando de `Application/User/`.
2. Click derecho sobre la carpeta -> `Import` -> `General` ->
   `File System` -> seleccionar `Firmware/drivers/` del repo principal.
   Marcar los 4 archivos `.c/.h`. En `Advanced`, marcar **"Create links
   in workspace"** para que no se copien — asi quedan versionados
   en `0G-LockControl-LSM110A`.
3. `Project -> Properties -> C/C++ General -> Paths and Symbols -> Includes`:
   agregar la ruta de los headers.
4. Habilitar I2C1 + EXTI0/1 en el `.ioc` (ver tabla arriba) y
   regenerar el codigo.
5. Build. Debe quedar 0 errores.

---

## Notas de diseño

### LIS2DW12
- Umbral configurable en runtime (default 200 mg, spec sec 4.4).
- En FS=2g, 1 LSB ≈ 31 mg (6 bits).
- En low-power mode 1 a 12.5 Hz consume ~1 uA.
- Anti-rebote: `WAKE_UP_DUR=0` (instantaneo). Subir a 1-2 si hay falsos.

### Reed switch / DRV5032
- Debounce por software con `HAL_GetTick()`. Default 50 ms.
- Misma logica para reed y DRV5032 (ambos open-drain con pull-up).
- Convencion: LOW = iman presente = CLOSED. HIGH = sin iman = OPEN = alarma.

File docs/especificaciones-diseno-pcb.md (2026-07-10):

# Especificaciones de diseño PCB — 0G LockControl v1

Fuentes: User Manual FCC 5937666 · datasheet LSM110A R03 · decisiones DT-001 a DT-011

## Stackup
- 2 capas, FR4 1.6 mm, 1 oz cobre, εr = 4.3 (igual a referencia SJI)
- Top: componentes + señales · Bottom: plano GND sólido SIN cortes bajo módulo ni antena

## Reglas RF (obligatorias — certificación)
- Línea RF: CPWG 50 Ω, 1.0 mm ancho / 0.15 mm clearance a GND coplanar
- Matching en pin 33: L101 0 Ω (serie) + C101 2.2 pF (shunt) + C102 DNI — footprints 0402
- Antena: patrón EVB_LSM ANT de SJI, copia exacta del Gerber (pendiente NDA GREATECH)
- Keepout total bajo/alrededor de antena: sin cobre, sin componentes, sin plano
- Via stitching perimetral en zona RF (paso ≈ 8 mm ≈ λ/20 @ 915 MHz)
- Línea RF: mínima longitud, sin ángulos de 90° (usar 45° o curvas)

## Dimensiones
- Referencia SJI: 50×80 mm — la antena serpentín + keepout dominan un extremo
- El ancho de la antena puede forzar ≥ 50 mm en un eje; confirmar al recibir Gerber
- Restricción de producto: caja compacta (objetivo < 5 cm en el eje visible) — revisar contra antena real

## Placement (orden de prioridad)
1. Antena en borde superior, keepout respetado, lejos de batería y metal
2. LSM110A adyacente al matching, línea RF corta y recta
3. CR2450 + 470 µF en extremo opuesto a la antena (la pila es plano metálico → detuning)
4. LIS2DW12 cerca del módulo (I²C corto), fuera de la zona RF
5. Reed/DRV5032 en el borde que da al imán (definir orientación de montaje)
6. SWD accesible con el dispositivo ensamblado

## Reglas generales
- Desacoplo 100 nF a < 2 mm de cada pin VDD; 10 µF bulk en la entrada del rail
- 470 µF lo más cerca del lazo batería→módulo (corriente de TX)
- GPIOs sin usar: no rutear (se configuran analog en FW)
- Serigrafía: versión, polaridad batería, pinout SWD, "Contains FCC ID: 2AS8LLSM110A"
- DRC JLCPCB 2 capas: track/space ≥ 0.127 mm, via ≥ 0.3/0.6 mm

## Checklist pre-gerber
- [ ] Impedancia CPWG verificada (1.0 / 0.15 / 1.6 mm / εr 4.3 ≈ 50 Ω)
- [ ] Antena importada del Gerber oficial SJI (NO redibujada a mano)
- [ ] GND continuo bajo módulo + stitching RF
- [ ] GATE 2 cerrado → confirma CR2450 + 470 µF (o pivot CR2477 / 1000 µF)
- [ ] Revisión cruzada con Yahir (pines vs firmware)
- [ ] DRC = 0 errores

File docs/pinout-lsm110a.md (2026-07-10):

# Asignación de pines — LSM110A en 0G LockControl

| Pin LSM110A | GPIO STM32WL | Función | Configuración | Notas |
|---|---|---|---|---|
| 11 | VDD | Alimentación | 3.0V directo o 2.5V LDO | 100nF + 10µF desacoplo |
| 1,10,12,20,23,32,34 | GND | Tierra | Plano GND | Todos conectados |
| 7 | PA13 | SWDIO | Debug SWD | Header 4 pines |
| 8 | PA14 | SWCLK | Debug SWD | Header 4 pines |
| 26 | PA9 | I2C1_SCL | Open-drain + pullup 4.7kΩ | Acelerómetro LIS2DW12 |
| 27 | PA10 | I2C1_SDA | Open-drain + pullup 4.7kΩ | Acelerómetro LIS2DW12 |
| 14 | PA0 | EXTI0 wake-up | Input, pull-down | INT1 del LIS2DW12 |
| 15 | PA1 | EXTI1 wake-up | Input | Reed switch o DRV5032 |
| 18 | PB7 | UART1_RX | Input (debug) | No poblar en producción |
| 19 | PB6 | UART1_TX | Output (debug) | No poblar en producción |
| 16 | PA2 | GPIO | Output push-pull | LED debug |
| 30 | NRST | Reset | Cap 100nF a GND | Botón reset opcional |
| 31 | BOOT0 | Boot mode | Flotante (pulldown interno) | No conectar |
| 33 | RF_OUT | Salida RF 50Ω | Traza CPWG 50 Ω (1.0 mm / gap 0.15 mm) | Antena PCB diseño SJI |

## Notas de diseño
- Todos los pines GND deben conectarse al plano de tierra sólido
- Capacitores de desacoplo lo más cerca posible de pin VDD
- Traza RF: CPWG 50 Ω, 1.0 mm ancho / 0.15 mm gap (FR4 1.6 mm, εr 4.3 — User Manual FCC doc 5937666). Matching: 0 Ω + 2.2 pF + DNI.
- UART y LED debug: poner footprint pero no poblar en producción

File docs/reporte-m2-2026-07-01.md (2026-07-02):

# Reporte de avance M2 — Pipeline de sensores completo (Y1/Y2/Y3/Y5)

**Empresa:** 0G IoT Solutions (previamente WND México)
**Proyecto:** 0G LockControl LSM110A
**Autor:** Yahir Flores — yflores@iotnet.mx (con Claude Code)
**Fecha:** 1 de julio de 2026
**Milestone:** M2 Firmware (semanas 2-5)

---

## ⚠️ Estado: trabajo 100% LOCAL — todavía NO está en la nube

Todo lo descrito en este reporte se realizó **directamente sobre los
repositorios locales de la Mac de Yahir**:

| Repo | Ruta local | Estado |
|---|---|---|
| `0G-LockControl-LSM110A` | `~/GitHub/0G-LockControl-LSM110A` | Archivos nuevos y modificados **en working tree, SIN commit y SIN push** |
| SDK `Support-SJI/LSM110A` | `~/GitHub/LSM110A` | Parches aplicados directo al clone (nunca se versiona en nuestro remoto) |

**Nada de esto existe aún en GitHub.** Hasta que no se hagan los commits y el
`git push` (ver sección 7), el único respaldo es esta máquina. Si se trabaja
desde otro equipo o Franco hace pull, **no verá ninguno de estos cambios**.

---

## 1. Resumen ejecutivo

Se implementó, compiló y linkeó **el pipeline completo de eventos por primera
vez**: EXTI → task del sequencer → lectura del sensor → payload de 12 bytes →
transmisión Sigfox real con cooldown.

Del backlog de Yahir quedaron cerradas **Y1, Y2, Y3 y Y5** (esta última con un
rediseño necesario, ver hallazgo 3). Solo falta **Y4** (test bench físico en el
Nucleo). Además quedaron **desbloqueadas F3 y F4 de Franco** con la API
`app_sensors_get_last_event()` + helpers de batería/temperatura.

**Build verificado (headless STM32CubeIDE, local):** `0 errors, 6 warnings`
(los 6 pre-existentes del SDK, cero de nuestro código), 18.7 s. El
`LSM1x0A_SDK_LoRaWAN_Sigfox.hex` flasheable quedó regenerado en el `Debug/`
local del proyecto.

---

## 2. Las 3 trampas encontradas (y desactivadas)

### Hallazgo 1 — Los drivers custom nunca se habían compilado
El "build 0 errors" registrado en el handoff era de las 08:46 del 2-jun; los
linked resources de los drivers se importaron al proyecto a las 16:47 del mismo
día. **Ningún build había incluido realmente nuestros archivos.**

### Hallazgo 2 — El primer build real habría fallado
- `HAL_I2C_MODULE_ENABLED` estaba **comentado** en `stm32wlxx_hal_conf.h` y
  `stm32wlxx_hal_i2c.c/_ex.c` no estaban en el proyecto → sin ellos no existe
  `I2C_HandleTypeDef` y el BSP no compila.
- Los include paths `../Application/User/*` apuntan a **carpetas virtuales de
  Eclipse que no existen en disco** — GCC jamás los resuelve. Se añadieron las
  rutas físicas reales al `.cproject`.

### Hallazgo 3 — El IWDG de 4 s (Y5 original) era una bomba doble
- `SIGFOX_API_send_frame` bloquea **7-9 s** en RC2 (3 frames de 12 bytes a
  600 bps) → un watchdog de 4 s cortaría **cada transmisión**.
- El build define `LPUART` → `LOW_POWER_DISABLE=0` → el MCU duerme en **Stop2**
  en idle, donde el IWDG (reloj LSI) sigue corriendo sin que nadie lo refresque
  → **reset cíclico en reposo**.

Solución aplicada: IWDG parametrizado con `LOCKCONTROL_IWDG_ENABLE` (default
`0`) y timeout de 16 s cuando se habilita. Habilitar solo en bench con
`LOW_POWER_DISABLE=1`. Solución definitiva en M4: option byte
`IWDG_STOP=frozen`.

---

## 3. Qué se construyó

### 3.1 Repo principal (nuevo código, local sin commitear)

| Archivo | Contenido |
|---|---|
| `Firmware/app/app_sensors.c/.h` | **Nuevo.** Capa de aplicación de sensores: WHO_AM_I con 3 reintentos + config wake-up 200 mg (Y1); tasks `CFG_SEQ_Task_ACCEL_EVENT`/`REED_EVENT` (Y3); armado del payload con el codec de Franco y `SIGFOX_API_send_frame` con cooldown 60 s (Y2); API para F3/F4: `app_sensors_get_last_event()`, `app_sensors_battery_pct()` (curva CR2450), `app_sensors_temp_c()`, `app_sensors_read_reed_now()`. |
| `Firmware/drivers/bsp_lockcontrol.c/.h` | IWDG opcional (Y5) + fix de `Error_Handler` implícito. |
| `Firmware/app/app_sensors.c` | Fix: `SYS_GetBatteryLevel`/`SYS_GetTemperatureLevel` se declaran en `adc_if.h`, no en `sys_app.h`. |
| `docs/sdk-patches.md` | **Nuevo.** Registro reproducible de cada edit al SDK (requisito §9.3 del handoff). |
| `docs/Guides/HANDOFF-FW-M2.md` | Actualizado: secciones 2.4, 3.3, 4 y 5.1 reflejan el estado real para que nadie siga instrucciones obsoletas. |

### 3.2 SDK local (`~/GitHub/LSM110A` — clone externo, parches documentados)

| Archivo | Cambio |
|---|---|
| `Core/Src/main.c` | `BSP_LockControl_Init()` + `HAL_GPIO_EXTI_Callback` que despacha PA0/PA1 a `app_sensors_notify_*_isr()` |
| `Core/Inc/utilities_def.h` | Task IDs del sequencer (USER CODE block) |
| `Core/Inc/stm32wlxx_hal_conf.h` | `HAL_I2C_MODULE_ENABLED` + `HAL_IWDG_MODULE_ENABLED` habilitados |
| `Sigfox/App/app_sigfox.c` | `app_sensors_init()` en init; watchdog refresh + `app_sensors_poll()` en process |
| `STM32CubeIDE/.project` | 7 linked resources nuevos: `app_sensors.c/.h`, `payload_codec.c/.h`, `hal_i2c.c`, `hal_i2c_ex.c`, `hal_iwdg.c` |
| `STM32CubeIDE/.cproject` | Include paths físicos hacia `Firmware/drivers`, `Firmware/app`, `Firmware/app/payload` |

> Nota de diseño: el plan original ponía `g_accel`/`g_reed` como globales de
> `main.c` (SDK). Se encapsularon como estáticos de `app_sensors.c` para que
> toda la lógica viva en el **repo principal versionado** y `main.c` del SDK
> quede mínimo.

### 3.3 Flujo implementado

```
EXTI PA0/PA1 (ISR, solo flags — sin I2C, sin bloqueo)
   └─> UTIL_SEQ_SetTask(ACCEL_EVENT / REED_EVENT)
        └─> Task en main loop (sequencer stm32_seq del SDK)
             ├─ LIS2DW12: lee WAKE_UP_SRC por I2C, decodifica eje
             ├─ Reed: lee estado con debounce 50 ms
             ├─ payload_encode() — 12 bytes spec sec 4.4 (codec de F1/F2)
             └─ SIGFOX_API_send_frame() — cooldown 60 s, hex dump en log
```

---

## 4. Verificación realizada (local)

- **Syntax-check** con el GCC ARM del propio CubeIDE (13.3.rel1) sobre los 7
  archivos tocados → 0 errores.
- **Build headless completo** de CubeIDE en workspace temporal →
  `0 errors, 6 warnings, 18.7 s`, con los objetos
  `Debug/Application/User/app/*.o`, `Debug/Application/User/drivers/*.o` y los
  HAL I2C/IWDG presentes en el `.elf`.
- Los 6 warnings son pre-existentes del SDK: 3× `usart.h:32`,
  `lora_at.c:2970`, `sgfx_app_api.c:175` y el aviso RWX del linker.

**Comando de reproducción** (documentado también en `docs/sdk-patches.md`):

```bash
/Applications/STM32CubeIDE.app/Contents/MacOS/STM32CubeIDE \
  --launcher.suppressErrors -nosplash \
  -application org.eclipse.cdt.managedbuilder.core.headlessbuild \
  -data /tmp/ws-limpio \
  -import "$HOME/GitHub/LSM110A/Projects/NUCLEO-WL55JC/Applications/LoRaWAN_SigFox/LSM1x0A/STM32CubeIDE" \
  -build "LSM1x0A_SDK_LoRaWAN_Sigfox/Debug"
```

---

## 5. Estado del backlog M2 (Yahir)

| ID | Estado | Nota |
|---|---|---|
| Y1 | ✅ | WHO_AM_I + wake-up 200 mg + log "Accel OK, WHO_AM_I=0x44" |
| Y2 | ✅ | Tasks procesan y transmiten; `app_sensors_poll()` como red de seguridad |
| Y3 | ✅ | Sequencer enganchado end-to-end desde el callback EXTI |
| Y4 | ⬜ | Test bench físico — único pendiente (requiere el Nucleo) |
| Y5 | ⚠️ | Implementado con rediseño (16 s, default off) — ver hallazgo 3 |

**Desbloqueos para Franco:** F3 (`sigfox_send_alarm` puede montarse sobre
`TrySendAlarm`/`app_sensors_get_last_event()`) y F4 (helpers de batería %,
temperatura y estado reed listos para el heartbeat).

---

## 6. Y4 — Cómo probar en bench (siguiente sesión)

1. Flashear `Debug/LSM1x0A_SDK_LoRaWAN_Sigfox.hex` (regenerado hoy, local).
2. Abrir VCOM del ST-Link a 9600 8N1.
3. Verificar en el log de boot: `Accel OK, WHO_AM_I=0x44`, config wake-up,
   `Reed inicial: CERRADO/ABIERTO`.
4. Golpear la mesa → `EVT accel: src=0x.. eje=..` + `TX Sigfox: 01...`
   (hex de 12 bytes para validar contra el backend — F5).
5. Acercar/alejar imán → `EVT reed: ABIERTO/CERRADO` + TX.
6. Segundo evento en <60 s → `TX suprimido: cooldown ... restantes`.
7. Confirmar recepción en backend.sigfox.com (device `033E07FC`, RC2 México).

---

## 7. Plan de subida a la nube (pendiente de ejecutar)

Commits atómicos propuestos en `0G-LockControl-LSM110A` (formato conventional,
§6.5 del handoff), y después `git push origin main`:

1. `feat(drivers): event API lis2dw12 + BSP con IWDG parametrizado`
   — `Firmware/drivers/*` + `Firmware/drivers/README.md`
2. `feat(app): app_sensors — pipeline evento→payload→TX Sigfox (Y1/Y2/Y3)`
   — `Firmware/app/app_sensors.c/.h`
3. `docs(fw): parches al SDK documentados + handoff M2 actualizado`
   — `docs/sdk-patches.md`, `docs/Guides/HANDOFF-FW-M2.md`, este reporte

**Pendiente de decisión antes del push:** en el working tree también hay
cambios previos no relacionados (`docs/spec-producto.md`, `.issues_cerrados.json`)
que conviene commitear por separado o revisar primero.

Los parches del SDK (`~/GitHub/LSM110A`) **no se pushean** — el SDK es un clone
externo; su reproducibilidad queda garantizada por `docs/sdk-patches.md`.

---

**Empresa operadora:** 0G IoT Solutions (previamente WND México) — https://0giotsolutions.com/

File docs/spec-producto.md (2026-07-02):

# Especificación de producto — Alarma IoT dual (acelerómetro + magnético)

**Proyecto:** LSM110A Alarm Device  
**Versión:** 1.0 (decisiones resueltas)  
**Fecha:** 2026-05-07  
**Estado:** Aprobado para MVP

---

## 1. Descripción general

Dispositivo compacto de alarma inalámbrica que detecta movimiento/vibración (acelerómetro I2C) y apertura de puerta/ventana (sensor magnético). Transmite alertas por Sigfox RC2 (902-928 MHz, México). Event-driven: duerme en ultra-bajo consumo y solo despierta por interrupción de hardware.

**Caso de uso:** Se adhiere a puerta, ventana, gabinete o equipo en interior (oficina, bodega, cuarto frío). Al detectar evento, envía alerta a la nube Sigfox → notificación al usuario.

## 2. Decisiones técnicas resueltas

| # | Pregunta | Decisión | Justificación |
|---|---|---|---|
| P1 | Reed vs Hall | Ambos footprints en PCB | Flexibilidad; mismo pin EXTI |
| P2 | Batería | CR2450 + cap soporte 470µF | Tamaño compacto; cap compensa pulso TX |
| P3 | LDO | Footprint con bypass 0Ω | Probar directo vs regulado sin re-hacer PCB |
| P4 | Umbral accel | 200mg default, configurable | Balance sensibilidad vs falsos positivos |
| P4b | Cooldown | 60 seg (max 1 msg/min) | Protege límite diario Sigfox |
| P5 | Downlink | Estructura preparada, no implementar | Struct en flash listo; parser para v2 |
| P6 | NOM/IFT | Post-MVP | NOM-208/IFT-008 aplica; LSM110A tiene FCC |
| P7 | Heartbeat | Cada 24 horas | Máxima vida de batería |
| P8 | Potencia TX | Configurable, default +14dBm | ~50mA, seguro con CR2450 |

## 3. Arquitectura del sistema

Arquitectura del producto final — 0G LockControl

### Ciclo de operación

```
Sleep (3µA) → Wake por INT → Leer sensor → Armar payload → TX Sigfox (~50mA x 2s) → Sleep
```

### Bloques del sistema

| Bloque | Componente | Conexión | Función |
|---|---|---|---|
| Procesador + Radio | LSM110A (STM32WL55) | Integrado | MCU Cortex-M4 + radio sub-GHz |
| Acelerómetro | LIS2DW12 | I2C: PA9/PA10 | Detección movimiento |
| Wake-up accel | LIS2DW12 INT1 | PA0 (EXTI0) | Interrupción hardware |
| Sensor magnético A | Reed switch NA | PA1 (EXTI1) | Opción A: apertura puerta |
| Sensor magnético B | DRV5032 hall | PA1 (EXTI1) | Opción B: apertura puerta |
| Alimentación | CR2450 3V 620mAh | Pin 11 VDD | Batería desechable |
| Cap soporte | 470µF | Paralelo VDD | Pulso TX |
| Regulador (opc.) | TPS7A02 + bypass 0Ω | Entre bat y VDD | Regulación opcional |
| Antena | Traza PCB 50Ω | Pin 33 RFOUT | 902-928 MHz |
| Debug | Header SWD 4 pines | PA13/PA14 | Programación |

### Asignación de pines

| Pin | GPIO | Función | Config |
|-----|---|---|---|
| 11 | VDD | Alimentación | 3.0V directo o 2.5V LDO |
| 1,10,12,20,23,32,34 | GND | Tierra | Plano GND |
| 7 | PA13 | SWDIO | Debug SWD |
| 8 | PA14 | SWCLK | Debug SWD |
| 26 | PA9 | I2C1_SCL | Pullup 4.7kΩ |
| 27 | PA10 | I2C1_SDA | Pullup 4.7kΩ |
| 14 | PA0 | EXTI0 | INT1 acelerómetro |
| 15 | PA1 | EXTI1 | Sensor magnético |
| 18 | PB7 | UART1_RX | Debug (no poblar prod) |
| 19 | PB6 | UART1_TX | Debug (no poblar prod) |
| 16 | PA2 | GPIO | LED debug |
| 30 | NRST | Reset | Cap 100nF a GND |
| 31 | BOOT0 | Boot | Flotante |
| 33 | RF_OUT | RF 50Ω | Traza antena |

## 4. Payload Sigfox (12 bytes)

| Byte | Campo | Tipo | Descripción |
|---|---|---|---|
| 0 | Tipo mensaje | uint8 | 0x01=alarma, 0x02=heartbeat |
| 1 | Fuente evento | bitfield | bit0=accel, bit1=magnético |
| 2-3 | Magnitud | uint16 BE | mg |
| 4 | Eje dominante | uint8 | 0=X, 1=Y, 2=Z |
| 5 | Estado magnético | uint8 | 0=cerrado, 1=abierto |
| 6 | Batería | uint8 | 0-100% |
| 7 | Temperatura | int8 | °C + offset 40 |
| 8-9 | Conteo eventos | uint16 BE | Desde último heartbeat |
| 10-11 | Reservado | uint16 | 0x0000 |

## 5. Config struct (preparado para downlink v2)

```c
typedef struct {
    uint16_t accel_threshold_mg;  // default 200
    uint16_t cooldown_seconds;    // default 60
    int8_t   tx_power_dbm;        // default 14
    uint8_t  heartbeat_hours;     // default 24
    uint8_t  daily_msg_limit;     // default 130
} device_config_t;
```

## 6. Plan MVP

| Milestone | Entregable | Semana | Responsable |
|---|---|---|---|
| M0 | Repo + spec + CubeIDE setup | 1-2 | Ambos |
| M1 | Esquemático KiCad | 2-5 | Tú |
| M2 | FW en Nucleo (accel+reed+Sigfox) | 2-5 | Tu persona |
| M3 | PCB layout + gerbers | 5-7 | Tú |
| M4 | Low power validado en Nucleo | 7-8 | Tu persona |
| M5 | PCB fabricada y ensamblada | 8-11 | Fábrica |
| M6 | Integración FW en PCB custom | 11-12 | Ambos |
| M7 | Prueba de campo | 12 | Ambos |

## 7. Siguientes pasos (esta semana)

1. Crear repo GitHub con estructura: `docs/`, `hardware/`, `firmware/`
2. Subir esta spec como `docs/spec-producto.md`
3. Tu persona: clonar repo SJI/LSM110A, compilar SDK, flashear Nucleo
4. Tú: crear símbolo + footprint LSM110A en KiCad
5. Ambos: validar TX Sigfox desde Nucleo (confirmar cobertura)
6. Tú: conseguir CR2450 + cap 470µF, medir voltaje durante TX

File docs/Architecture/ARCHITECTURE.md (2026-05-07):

# Arquitectura del Sistema - 0G LockControl

## 1. Visión General

El sistema 0G LockControl es un dispositivo IoT de monitoreo de apertura de puertas que utiliza la red Sigfox para transmitir alertas en tiempo real. El diseño se basa en el SoC **LSM110A** (STM32WL core) como unidad central de procesamiento y comunicación.

## 2. Diagrama de Bloques

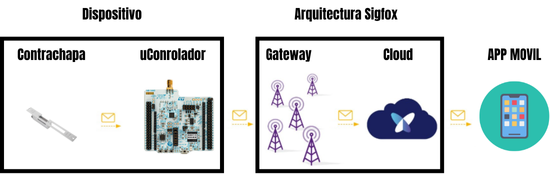
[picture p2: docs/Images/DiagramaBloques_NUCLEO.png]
Diagrama de Bloques - Concepto NUCLEO


*Nota: El diagrama original fue creado durante la fase de pruebas con el NUCLEO-WL55JC2. La arquitectura final sustituye la placa NUCLEO por el SoC LSM110A en una PCB dedicada.*

```
DISPOSITIVO                          RED SIGFOX                    USUARIO
┌────────────────────────┐     ┌──────────────────┐     ┌─────────────────┐
│                        │     │                  │     │                 │
│  [Reed Switch] ──EXTI──┤     │   Base Stations  │     │  Backend API    │
│                        │     │   (Gateways)     │     │  (Callback)     │
│  [LSM110A SoC]         │────▶│                  │────▶│       │         │
│   - Cortex-M4          │ RF  │   868/902 MHz    │ IP  │       ▼         │
│   - Radio Sub-GHz      │     │                  │     │  App Móvil      │
│   - Sigfox Stack       │     │                  │     │  (Push Notif.)  │
│                        │     │                  │     │                 │
│  [Batería] ──LDO──VCC  │     │                  │     │                 │
│                        │     │                  │     │                 │
└────────────────────────┘     └──────────────────┘     └─────────────────┘
```

## 3. Subsistemas

### 3.1 Subsistema de Sensado Magnético

- **Sensor**: Reed switch (normalmente cerrado)
- **Principio**: Interrupción de campo magnético al abrir la puerta
- **Montaje**: Dispositivo en marco fijo, imán en hoja móvil
- **Señal**: Binaria (abierto/cerrado) conectada a GPIO con EXTI
- **Acondicionamiento**: Resistor pull-up + filtro RC anti-rebote

**Alternativa evaluada**: Sensor Hall digital (requiere alimentación constante, descartado por consumo)

### 3.2 Unidad de Procesamiento (LSM110A)

| Característica | Detalle |
|---|---|
| Módulo | LSM110A (SJI) |
| Core | STM32WL (ARM Cortex-M4) |
| Radio | Sub-GHz integrado |
| Protocolo | Sigfox (RCZ2 para México) |
| Frecuencia | 902 MHz (uplink) |
| Modos de bajo consumo | STOP, Sleep, Standby |
| Programación | SWD (ST-LINK externo) o UART |
| Repositorio | [Support-SJI/LSM110A](https://github.com/Support-SJI/LSM110A) |

### 3.3 Alimentación

- Batería (tipo por evaluar: CR2032, LiPo, o AA)
- Regulador LDO de bajo dropout
- Objetivo: meses a años de autonomía en modo sleep con transmisiones esporádicas

### 3.4 Antena

- Frecuencia: 868/902 MHz (Sigfox RCZ2)
- Opciones: PCB trace antenna o chip antenna
- Diseño según AN5457 de ST (Optimized RF Board Layout for STM32WL)

### 3.5 Comunicación Sigfox

- **Uplink**: Máx. 140 mensajes/día, payload 12 bytes
- **Downlink**: Máx. 4 mensajes/día, payload 8 bytes
- **Callbacks**: HTTP/HTTPS configurados en backend.sigfox.com
- **Credenciales**: ID + PAC + KEY provistos por Sigfox Build

## 4. Evolución desde NUCLEO-WL55JC2

### Hitos completados con NUCLEO

1. Conexión a red Sigfox (backend.sigfox.com, device ID: 54396924)
2. Conexión a LORIOT vía LoRaWAN (device 0080E1)
3. Código de detección de flanco en PB1 con reed switch
4. Envío de payload Sigfox al detectar apertura
5. Certificados y credenciales Sigfox cargados
6. Caracterización de periféricos (GPIO, UART, LEDs, botones)
7. Pruebas de comandos AT para Sigfox

### Transición a LSM110A

- El NUCLEO incluye programador ST-LINK integrado (caro para producción)
- El LSM110A permite PCB dedicada con solo los componentes necesarios
- Se mantiene compatibilidad de código (mismo core STM32WL)
- Programación externa vía ST-LINK o UART reduce costo

## 5. Decisiones de Diseño

| Decisión | Opción Elegida | Alternativa | Justificación |
|---|---|---|---|
| SoC | LSM110A | STM32WL55CCU7 standalone | Módulo integrado, más fácil de diseñar PCB |
| Protocolo LPWAN | Solo Sigfox | Sigfox + LoRa dual | Simplicidad, menor costo, suficiente para el caso de uso |
| Sensor | Reed switch | Sensor Hall | Consumo nulo en reposo, bajo costo |
| Programación | ST-LINK externo / UART | ST-LINK integrado | Reduce costo del BOM |
| PCB | Una sola capa | Dos capas | Reducción de costos de manufactura |
| App framework | Flutter / React Native | Nativo (Kotlin/Swift) | Multiplataforma, desarrollo más rápido |

## 6. Recursos y Enlaces

- [Documentación STM32WL](https://www.st.com/en/microcontrollers-microprocessors/stm32wl-series/documentation.html)
- [Repositorio LSM110A (SJI)](https://github.com/Support-SJI/LSM110A)
- [STM32CubeWL GitHub](https://github.com/STMicroelectronics/STM32CubeWL)
- [Sigfox Build Development](https://build.sigfox.com/development)
- [Sigfox Industrialization](https://build.sigfox.com/industrialization#the-sigfox-credentials)
- [Octopart - STM32WL55JCI7U](https://octopart.com/es/part/stmicroelectronics/STM32WL55JCI7U)
- [Notion - Documentación NUCLEO](https://star-muskmelon-e73.notion.site/NUCELO-STM32WL55JC2-20f00f12d64280879a8fe57968791522)
- [Video: LoRaWAN + Sigfox Coexistence](https://www.youtube.com/watch?v=HsrL-7WmhUE)
- [TrueStepByStep - LoRa](https://www.youtube.com/watch?v=xwhwI3P_Xro)

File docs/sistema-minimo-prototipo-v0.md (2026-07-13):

# Sistema mínimo LSM110A — Prototipo v0 (PCB mínima)

**0G IoT Solutions** (previamente WND México) — https://0giotsolutions.com/
Julio 2026 · Autor: Yahir Flores · Cierra milestones **M1** (esquemático) y **M3** (layout+gerbers) del Plan MVP.

> Estado de partida: firmware M2 con reed+accel **ya funciona** (Y1–Y3 ✅, validado en NUCLEO-WL55JC con contacto magnético en PA1). BOM v0 verificada en LCSC. Footprint del módulo listo. **Lo único vacío es `Hardware/Schematic/` — esta guía lo cierra.**

---

## 1. Alcance del prototipo v0

Tarjeta mínima de ~35×45 mm con: LSM110A + CR2450 + sensor magnético + acelerómetro + SWD + antena. Sin display, sin downlink, sin carcasa. Objetivo: **uplink Sigfox RC2 real desde el módulo** con los mismos eventos de puerta ya validados en la Nucleo.

## 2. Esquemático — conexiones (net por net)

Fuente de verdad de pines: `docs/pinout-lsm110a.md` (datasheet R03). Referencias = `Hardware/BOM/bom-mvp-v0.csv`.

### 2.1 Alimentación

```
BAT1 (CR2450) ──┬── U4b 0Ω (default)  ──┬── VDD (pin 11)
                └── U4a TPS7A02 2.5V ───┘   (poblar solo UNO — decisión P3)
VDD ── C_TX 470µF tántalo ── GND      (pulso TX, decisión P2)
VDD ── C11 4.7µF ── GND               (bulk)
VDD ── C1 100nF ── GND                (pegado al pin 11)
GND: pines 1,10,12,20,23,32,34 → plano sólido
```

### 2.2 Sensor magnético (el corazón del producto)

```
U3 DRV5032 (SOT-23): VCC→VDD + C2 100nF · GND→GND · OUT (pin 2) → PA1 (pin 15 del módulo)
J3 bornera/JST 2P:   terminal para contacto reed EXTERNO, en paralelo: PA1 ↔ GND
R1 10k pull-up VDD→PA1 (respaldo del pull-up interno; DNP si molesta el consumo)
```

Ambos son activo-bajo con imán presente → **cero cambio de firmware** (`reed_switch.c` sirve para los dos). El J3 permite usar el mismo contacto de puerta ya probado en la Nucleo.

### 2.3 Acelerómetro

```
U2 LIS2DW12: VDD+VDDIO→VDD + C3/C4 100nF · SCL→PA9 (pin 26) · SDA→PA10 (pin 27)
R2,R3 pull-ups I2C → VDD (ver §3, discrepancia 4.7k vs 10k)
INT1 → PA0 (pin 14), pull-down interno en firmware
```

### 2.4 Debug / misc

```
J1 SWD 5p: VDD · SWDIO PA13 (pin 7) · SWCLK PA14 (pin 8) · NRST (pin 30) · GND
J2 UART 3p (footprint, NO poblar en producción): PB6 TX (pin 19) · PB7 RX (pin 18) · GND
LED1 verde + R8 1k ← PA2 (pin 16)
NRST ── C5 100nF ── GND
BOOT0 (pin 31): flotante (pull-down interno) + testpoint TP1 (recovery por bootloader)
```

### 2.5 RF

```
RF_OUT (pin 33) ── traza 50Ω ── ANT1 antena PCB (diseño de referencia SJI)
Opcional v0: footprint u.FL + 0Ω selector en la traza, para probar con whip
y comparar RSSI en el backend antes de congelar la antena PCB.
```

El módulo ya integra matching + filtro armónico + TCXO → **no lleva matching externo**, solo la traza a 50Ω.

## 3. Correcciones a la BOM v0 (hallazgos)

| # | Hallazgo | Acción |
|---|---|---|
| 1 | **U3 `DRV5032DU` NO es omnipolar** — datasheet TI tabla 5-1: DU = **unipolar (solo polo sur), push-pull, 20 Hz**. La BOM lo describe como omnipolar. Con DU, el imán del kit debe montarse con orientación controlada o no dispara. | Cambiar a **DRV5032FB** (omnipolar, push-pull, **5 Hz = ~3× menos consumo**, ideal puerta) o al sustituto ya listado **FCDBZR C527532** (omnipolar, open-drain 20 Hz, requiere el pull-up R1). **Mismo footprint SOT-23, mismo pin de salida** — cero cambio de layout. |
| 2 | Pull-ups I2C: `pinout-lsm110a.md` dice **4.7kΩ**, la BOM solo lista 10k. A 100 kHz Standard Mode con trazas cortas, 10k funciona; 4.7k da más margen. | Decidir uno y alinear ambos documentos (sugerencia: 10k de la BOM, bus corto). |
| 3 | La BOM no incluye conector para el sensor externo ni u.FL de pruebas. | Agregar J3 (JST-XH 2P o bornera 5.08 mm) y opcional u.FL (C2557956 o similar) + 0Ω. |
| 4 | Spec §6 dice "Esquemático KiCad"; la ruta real es **EasyEDA Pro → JLCPCB**. | Actualizar spec (decisión de hoy). |

## 4. Layout — reglas para 2 capas JLCPCB

- Stackup: FR4 **1.6 mm, 2 capas**, cobre 1 oz. Traza RF microstrip ≈ **2.8 mm** (ya calculado, nota en pinout doc). Si el ancho estorba, pasar a coplanar waveguide con gap y recalcular en la herramienta de impedancia de JLCPCB.
- **Plano GND sólido bajo el módulo y la traza RF** en bottom; sin trazas cruzando debajo.
- **Keep-out de la antena**: sin cobre (ni planos) bajo el área de antena en AMBAS capas; respeta el área del diseño de referencia SJI.
- Stitching vias a lo largo de la traza RF cada ~3 mm (λ/10 @ 915 MHz ≈ 3.3 cm → sobra con 3-5 mm).
- C1/C11/C_TX pegados al pin 11; el DRV5032 y su 100nF cerca del borde donde va el imán.
- CR2450 en bottom (holder MY-2450-01) para dejar top limpio para RF/sensores.
- Módulo LSM110A: half-through holes hacia el borde de la PCB si es posible (facilita soldado e inspección a mano).

## 5. Orden en JLCPCB

- PCB: 5 pzas, 2 capas, 1.6 mm, HASL sin plomo (suficiente para v0), verde.
- **SMT assembly económico (un lado)**: solo los Basic (R, C, LED, U4b) + Extended baratos (U2, U3, BAT1 holder, C_TX). Cada Extended agrega fee de setup — con la BOM v0 son ~4-5 fees, aceptable.
- **Hand-load (tú)**: U1 LSM110A (no está en LCSC — cautín + flux en los half-holes, 10 min), U4a si se prueba la config regulada, conectores.
- Pedir **stencil** solo si ensamblas todo a mano; con SMT de JLC no hace falta.

## 6. Bring-up post-fab (checklist)

1. Inspección visual + continuidad: VDD↔GND sin corto **antes** de poner la pila.
2. Con fuente de banco a 3.0 V limitada a 50 mA: corriente reposo (sin firmware ≈ decenas de µA).
3. ST-LINK al J1 → `STM32CubeProgrammer` debe detectar el **STM32WLE5** del módulo.
4. Flashear firmware (§7) → logs por J2 (UART debug).
5. Evento de puerta (imán) → LED + log + **uplink visible en backend Sigfox RC2**.
6. Comparar RSSI backend: antena PCB vs whip (si montaste el u.FL).
7. Medir consumo sleep con multímetro en serie (meta: <5 µA con pila directa).

## 7. Firmware (ya casi listo)

- Proyecto: `LSM1x0A_SDK_LoRaWAN_Sigfox` (SDK SJI, `~/GitHub/LSM110A`), con `reed_switch.c` + `app_sensors.c` ya integrados y disparando TX (Y1–Y3 ✅).
- Pendiente para el prototipo: **Y4** (test bench Nucleo documentado) y **F1–F3** de Franco (payload 12 B de spec §4.4 + `sigfox_send_alarm()`); mientras no estén, el TX actual ya sirve para validar RF de la tarjeta.
- El módulo es **STM32WLE5 (single-core)** — el SDK SJI ya lo contempla; flashear por SWD (J1) con el ST-LINK externo, o el de la Nucleo en modo "external target".
- Credenciales Sigfox del módulo: el LSM110A trae ID/PAC propios de fábrica (contrato UnaTag_test / registrar en backend con el PAC de SJI).

## 8. Ruta a prototipo (2-3 semanas)

| Días | Actividad |
|---|---|
| 1–3 | Esquemático en EasyEDA Pro (este doc §2) + ERC + revisar con Franco |
| 4–6 | Layout (§4) + DRC JLCPCB + gerbers → **pedir** (BOM §3 corregida) |
| 7–14 | Fab + envío a MX. En paralelo: Y4 en Nucleo y F1–F3 |
| 15–17 | Bring-up (§6) + flasheo + uplink real desde el módulo |
| 18+ | M6: integración FW final en PCB custom, prueba de campo |

---
*Referencias: `docs/pinout-lsm110a.md`, `docs/spec-producto.md` (decisiones P1–P8, payload §4.4), `Hardware/BOM/bom-mvp-v0.csv`, HANDOFF-FW-M2 §5, datasheet TI DRV5032 (tabla 5-1), manual integrator SJI (antena/certificación FCC 2AS8LLSM110A).*

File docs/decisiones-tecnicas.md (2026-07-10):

# Decisiones técnicas — 0G LockControl

Registro de decisiones arquitectónicas del proyecto. Cada entrada documenta el contexto, las opciones evaluadas y la decisión final.

## DT-001: Sensor magnético — Reed switch + Hall (ambos)
- **Fecha:** 2026-05-07
- **Contexto:** Necesitamos detectar apertura de puerta. Reed es más barato (0µA), Hall (DRV5032) es más robusto y SMD.
- **Decisión:** Poner ambos footprints en la PCB. Mismo pin PA1 (EXTI1). Probar en prototipo.
- **Consecuencia:** Layout de PCB necesita espacio para ambos footprints.

## DT-002: Batería — CR2450 + cap soporte 470µF
- **Fecha:** 2026-05-07
- **Contexto:** Necesitamos batería desechable, tamaño <5cm. CR2450 tiene resistencia interna alta para pulsos de TX Sigfox.
- **Decisión:** CR2450 + capacitor 470µF de soporte. Si falla, pivot a CR2477 (mismo diámetro).
- **Consecuencia:** Validar con osciloscopio que VDD no cae debajo de 1.8V durante TX.

## DT-003: LDO — Footprint con bypass 0Ω
- **Fecha:** 2026-05-07
- **Contexto:** Alimentar directo desde CR2450 (3V→2V) maximiza vida útil. Con LDO a 2.5V se pierde headroom.
- **Decisión:** Footprint de TPS7A02 con bypass de 0Ω. Probar ambas configs sin re-hacer PCB.
- **Consecuencia:** BOM tiene componente opcional.

## DT-004: Firmware — API (sin MCU externo)
- **Fecha:** 2026-05-07
- **Contexto:** AT commands requiere MCU externo. API permite programar directo en el STM32WL del LSM110A.
- **Decisión:** Firmware API. Código en C corre dentro del módulo. Stack Sigfox de SJI no se modifica.
- **Consecuencia:** Curva de aprendizaje en C bare-metal. Mayor control de bajo consumo.

## DT-005: Potencia TX — +14dBm default, configurable
- **Fecha:** 2026-05-07
- **Contexto:** +14dBm consume ~50mA (seguro con CR2450). +22dBm consume ~123mA (riesgoso).
- **Decisión:** Default +14dBm, configurable en firmware. Subir solo si cobertura insuficiente.
- **Consecuencia:** Alcance de 2-5km en zona urbana. Suficiente para interiores con cobertura Sigfox.

## DT-006: Heartbeat — Cada 24 horas
- **Fecha:** 2026-05-07
- **Decisión:** 1 mensaje keepalive/día con: nivel batería, temperatura, conteo eventos.
- **Consecuencia:** Máxima vida de batería. Detección de falla en máximo 24h.

## DT-007: Cooldown — 60 segundos entre mensajes
- **Fecha:** 2026-05-07
- **Decisión:** Mínimo 60s entre transmisiones + contador diario max 130 msgs (guarda 10 para heartbeats).
- **Consecuencia:** Protege límite Sigfox de 140 msgs/día.

## DT-008: Certificación NOM — Post-MVP
- **Fecha:** 2026-05-07
- **Decisión:** NOM-208/IFT-008 aplica para 902-928 MHz. LSM110A tiene FCC + MRA México-USA. Gestionar después del MVP.
- **Consecuencia:** No bloquea prototipado. Necesario para comercialización.

## DT-009: Watchdog IWDG como red de seguridad
- **Fecha:** 2026-05-07
- **Contexto:** Con firmware API sin MCU externo, un bug en el código de aplicación puede colgar todo el sistema.
- **Decisión:** Habilitar IWDG (Independent Watchdog) con timeout de 4 segundos. Refresh en el loop principal.
- **Consecuencia:** El dispositivo se recupera automáticamente de cuelgues de firmware en máximo 4 segundos.

## DT-010: Antena — diseño de referencia SJI sin modificaciones
- **Fecha:** 2026-05-07
- **Contexto:** La certificación FCC del LSM110A requiere usar exclusivamente la antena tipo traza PCB diseñada por SJI. Cualquier cambio de antena invalida la FCC.
- **Decisión:** Copiar exactamente el diseño de antena del EVB de SJI. Agregar conector U.FL como opción de pruebas con jumper 0Ω.
- **Consecuencia:** El layout de la antena PCB no puede modificarse sin re-certificar. El conector U.FL es solo para pruebas de desarrollo.
- **Referencia:** FCC ID: 2AS8LLSM110A — fccid.io/2AS8LLSM110A
- **Actualización (datos FCC verificados, doc 5937666):** La referencia SJI usa CPWG 50Ω (1.0 mm / 0.15 mm), no microstrip. Matching: L101=0Ω, C101=2.2pF, C102=DNI. Placa de referencia 50×80 mm, εr 4.3. Separación RF mínima 20 cm a personas (requisito de certificación). El Gerber de la antena es confidencial — en gestión con GREATECH/SJI bajo NDA.

## DT-011: Certificaciones — plan de cumplimiento
- **Fecha:** 2026-05-07
- **Contexto:** Para vender el dispositivo en México se necesitan: Sigfox Ready, NOM-208/IFT-008, y suscripción Sigfox.
- **Decisión:** Todas las certificaciones se tramitan post-MVP. El diseño cumple desde ahora las condiciones para no invalidar certificaciones heredadas.
- **Condiciones para preservar certificaciones:**
  1. No modificar la stack de Sigfox del SDK de SJI
  2. Usar antena PCB del diseño de referencia SJI
  3. No cambiar frecuencia de operación (RC2, 902-928 MHz)
  4. No exceder potencia máxima certificada (+22dBm)
  5. Etiquetar producto con "Contains FCC ID: 2AS8LLSM110A"

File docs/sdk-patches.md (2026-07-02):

# Parches aplicados al SDK (Support-SJI/LSM110A)

**Empresa:** 0G IoT Solutions
**Proyecto:** 0G LockControl LSM110A — Milestone M2
**Ultima actualizacion:** 1-julio-2026

El SDK del fabricante (`~/GitHub/LSM110A`) es un clone externo sin control de
versiones nuestro. Este documento registra **cada edicion** hecha a archivos del
SDK para poder reproducirlas tras un re-clone o update del fabricante.

Base de rutas: `~/GitHub/LSM110A/Projects/NUCLEO-WL55JC/Applications/LoRaWAN_SigFox/LSM1x0A/`

---

## Estado tras los parches (1-jul-2026)

Build headless verificado: **0 errores, 6 warnings (todos pre-existentes del
SDK), 18.7 s**. Primer build en incluir realmente los drivers custom (ver
hallazgo 1).

---

## Hallazgos que motivaron parches

1. **Los drivers custom nunca se habian compilado.** Los linked resources se
   anadieron al `.project` el 2-jun a las 16:47; el ultimo `.elf` era de las
   08:46 del mismo dia. El "build 0 errores" previo compilo el SDK *sin*
   nuestros archivos.
2. **`HAL_I2C_MODULE_ENABLED` estaba comentado** en `stm32wlxx_hal_conf.h` y
   `stm32wlxx_hal_i2c.c/_ex.c` no estaban en el proyecto. El primer build real
   de `bsp_lockcontrol.c`/`lis2dw12.c` habria fallado (no existe
   `I2C_HandleTypeDef`).
3. **Los include paths `../Application/User/...` apuntan a carpetas virtuales
   de Eclipse** que no existen en disco: GCC nunca los resuelve. Los sources
   linkeados si compilan (CDT pasa su ruta real), pero los `-I` requieren rutas
   fisicas.
4. **IWDG de 4 s (Y5 original) es inviable en este firmware:**
   - `SIGFOX_API_send_frame` bloquea ~7-9 s en RC2 (3 frames de 12 bytes a
     600 bps) → el watchdog cortaria cada transmision.
   - El build define `LPUART` → `LOW_POWER_DISABLE=0` → el MCU duerme en Stop2
     en idle, donde nadie refresca y el IWDG (que corre desde LSI) resetearia
     el equipo ciclicamente. Solucion definitiva para M4: option byte
     `IWDG_STOP = frozen` o refresh al despertar. Por ahora el IWDG queda
     compilado pero deshabilitado por default (`LOCKCONTROL_IWDG_ENABLE=0`,
     timeout 16 s cuando se habilita).

---

## Parche 1 — `Core/Inc/stm32wlxx_hal_conf.h`

Habilitar los modulos HAL que usa el BSP:

```c
/* antes */  /*#define HAL_I2C_MODULE_ENABLED   */
/* ahora */  #define HAL_I2C_MODULE_ENABLED

/* antes */  /*#define HAL_IWDG_MODULE_ENABLED   */
/* ahora */  #define HAL_IWDG_MODULE_ENABLED
```
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

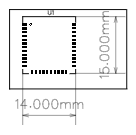
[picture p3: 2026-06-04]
Hardware/EasyEDA/Screenshots/PCB_PCB_LSM_Module_2026-06-04.png

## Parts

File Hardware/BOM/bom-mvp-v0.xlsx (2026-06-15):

Bill of Materials (BOM) — MVP v0
0G-LockControl-LSM110A · 0G IoT Solutions (previamente WND México)
https://0giotsolutions.com/ | Fecha: 2026-06-15 | GitHub issue #4 - Verificar stock y precios de componentes en LCSC
U4a/U4b comparten footprint: poblar SOLO uno. Precios/stock verificados en LCSC (salvo U1 y U4a).
Ref | Qty | Tipo de componente | Descripción | MPN | Fabricante | LCSC# | Basic/Ext | Fuente | Precio@100u (USD) | Precio@1ku (USD) | Stock | Sustituto | Link | Notas | Subtotal@100u | Subtotal@1ku
U1 | 1 | Módulo RF transceptor sub-GHz (Sigfox/LoRa) | Módulo Sigfox/LoRa SiP | LSM110A (WSLSM110A00) | SJI / SeongJi Industrial | — | Extended | GREATECH / Yadom / SJI | $10.1000 | $7.9400 | rollo 500/1000 | — | https://www.greatech.de/store/p/seongji-lsm110a-sigfox-lorawan-module | No en LCSC; hand-load. Precio GREATECH: ≥10u ≈€9.35/u; 500u=€3675 y 1000u=€7350 → €7.35/u (≈$7.94). @100u usa €9.35 (≈$10.10) conservador, tier-100 sin confirmar. Sigfox Partners/Yadom/ThingPark bloquean precio (login). Confirmar MOQ con SeongJi/GREATECH (EXW). | $10.1000 | $7.9400
U2 | 1 | Acelerómetro MEMS 3 ejes | Acelerómetro digital ±2/4/8/16g, LGA-12 | LIS2DW12TR | STMicroelectronics | C189624 | Extended | LCSC | $0.7727 | $0.7093 | 29,551 | LIS2DH12TR | https://www.lcsc.com/product-detail/C189624.html | CORREGIDO: el C400557 del issue es un conector JILN, no el acelerómetro. | $0.7727 | $0.7093
U3 | 1 | Sensor de efecto Hall (switch omnipolar) | Hall switch omnipolar 1.6µA, SOT-23 | DRV5032DUDBZR | Texas Instruments | C882721 | Extended | LCSC | $0.2200 | $0.1599 | 385 (bajo) | DRV5032FCDBZR (C527532) | https://www.lcsc.com/product-detail/C882721.html | Stock LCSC bajo (385). Reservar carrete (3,000) para producción >1k. | $0.2200 | $0.1599
U4a | 0 | Regulador LDO nanopower 2.5V (config REGULADA - opcional) | LDO 200mA, Iq 25nA, 2.5V, SOT-23-5 | TPS7A0225PDBVR | Texas Instruments | — | Extended | Mouser / DigiKey | $0.4900 | $0.4300 | ~3,700 (Mouser) | TPS7A0233PDBVR (C2887324, solo 3.3V) | https://www.digikey.com/en/products/detail/texas-instruments/TPS7A0225PDBVR/12165218 | VENTAJA: riel 2.5V estable aunque la CR2450 caiga en el pulso TX. No en LCSC; hand-load. MPN del issue 'TPS7A0225DBVR' incorrecto (falta la 'P'). Poblar U4a O U4b, no ambos. | $0.0000 | $0.0000
U4b | 1 | Jumper bypass 0Ω (config DIRECTA - default) | Resistor 0Ω 0402 (jumper) | 0402WGF0000TCE | UNI-ROYAL | C17168 | Basic | LCSC | $0.0012 | $0.0010 | masivo | — | https://www.lcsc.com/product-detail/C17168.html | VENTAJA: máxima vida de batería (sin pérdida de headroom ni Iq del LDO), $0 setup fee. Default si pasa el GATE 2 (#6). Poblar U4a O U4b, no ambos. | $0.0012 | $0.0010
BAT1 | 1 | Portapilas / battery holder (electromecánico) | Holder CR2450, SMD | MY-2450-01 | MYOUNG | C964845 | Extended | LCSC | $0.1643 | $0.1437 | 7,590 | Keystone (no en LCSC) | https://www.lcsc.com/product-detail/C964845.html | Equivalente Keystone no disponible en LCSC; MYOUNG es la opción real. | $0.1643 | $0.1437
C1-C10 | 10 | Capacitor cerámico MLCC (desacoplo) | MLCC 100nF 0402 X7R 16V | CL05B104KO5NNNC | Samsung | C1525 | Basic | LCSC | $0.0017 | $0.0013 | masivo | C131394 (50V X7R, Extended) | https://www.lcsc.com/product-detail/C1525.html | 16V suficiente para riel 3V (buen derating). El issue pedía 25V; si se exige ≥25V usar C131394 (50V, Extended). | $0.0170 | $0.0130
C11 | 1 | Capacitor cerámico MLCC | MLCC 4.7µF 0603 X5R 16V | CL10A475KO8NNNC | Samsung | C19666 | Basic | LCSC | $0.0115 | $0.0096 | 141,910 | — | https://www.lcsc.com/product-detail/C19666.html | Dieléctrico real X5R (no X7R); adecuado para 3V. | $0.0115 | $0.0096
C_TX | 1 | Capacitor de tántalo (bulk / soporte pulso TX) | Tántalo 470µF 6.3V CASE-D low-ESR | TAJD477K006RNJ | KYOCERA AVX | C7229 | Extended | LCSC | $0.8141 | $0.6731 | 8,046 | Polímero low-ESR (más caro) | https://www.lcsc.com/product-detail/C7229.html | ESR 400mΩ (estándar). Evaluar versión 10V por margen sobre 3V de batería. | $0.8141 | $0.6731
R1-R4 (10k) | 4 | Resistor chip película gruesa | Resistor 10kΩ 0402 1% | 0402WGF1002TCE | UNI-ROYAL | C25744 | Basic | LCSC | $0.0013 | $0.0011 | verificar | C60490 (Yageo) | https://www.lcsc.com/product-detail/C25744.html | Qty estimada (pull-ups/divisores). Confirmar contra esquemático final (ERC). | $0.0052 | $0.0044
R5-R7 (100k) | 3 | Resistor chip película gruesa | Resistor 100kΩ 0402 1% | RC0402FR-07100KL | YAGEO | C60491 | Basic | LCSC | $0.0008 | $0.0007 | en stock | — | https://www.lcsc.com/product-detail/C60491.html | Qty estimada. Confirmar contra esquemático final (ERC). | $0.0024 | $0.0021
R8-R10 (1k) | 3 | Resistor chip película gruesa | Resistor 1kΩ 0402 1% | RC0402FR-071KL | YAGEO | C106235 | Basic | LCSC | $0.0009 | $0.0007 | 8.9M | — | https://www.lcsc.com/product-detail/C106235.html | Qty estimada (serie LED + debug). Confirmar contra esquemático final (ERC). | $0.0027 | $0.0021
LED1 | 1 | Diodo emisor de luz (LED) | LED verde 0603 | YLED0603G | YONGYUTAI | C19273151 | Basic | LCSC | $0.0060 | $0.0050 | 100,300 | — | https://www.lcsc.com/product-detail/C19273151.html | CORREGIDO: el C72043 del issue está descontinuado (stock=1). Reemplazo verificado. | $0.0060 | $0.0050
RESUMEN DE COSTO (USD) |  |  |  |  |  |  |  |  | @precio 100u | @precio 1ku
Componentes LCSC por placa (config default U4b, excl. módulo U1) |  |  |  |  |  |  |  |  | $2.02 | $1.72
Módulo LSM110A (U1) por placa — precio GREATECH, confirmar con distribuidor |  |  |  |  |  |  |  |  | $10.10 | $7.94
COSTO POR PLACA (1 unidad terminada, config directa 3V) |  |  |  |  |  |  |  |  | $12.12 | $9.66
TOTAL CORRIDA 100 placas (= costo por placa @100u × 100) |  |  |  |  |  |  |  |  | $1211.71
TOTAL CORRIDA 1000 placas (= costo por placa @1ku × 1000) |  |  |  |  |  |  |  |  |  | $9663.20
Nota: @100u y @1ku son PRECIO UNITARIO al comprar en ese volumen (descuento). 'Por placa' ya multiplica por Qty. 'Corrida' = por placa × Nº de placas.
Si se puebla el LDO regulado U4a en vez del 0Ω: sumar +$0.49 (@100u) / +$0.43 (@1ku) por placa.
Setup fees JLCPCB SMT (one-time, no por placa): ~4 partes Extended ensamblables (U2, U3, BAT1, C_TX) × ~$3 = ~$12. U1 y U4a van hand-load (sin assembly).
Módulo LSM110A (GREATECH): 500u=€3675 y 1000u=€7350 → €7.35/u (≈$7.94). Domina el costo; confirmar MOQ con SeongJi/GREATECH antes de presupuestar en firme.

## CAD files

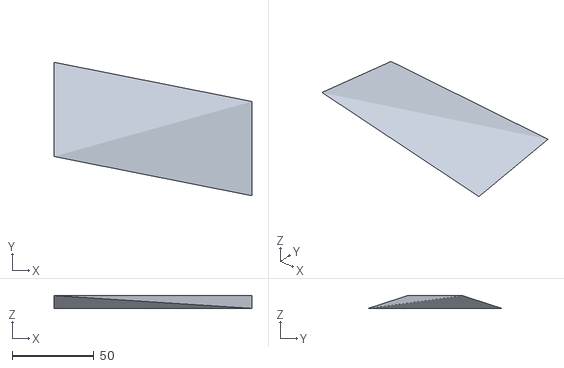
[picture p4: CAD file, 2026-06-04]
Hardware/EasyEDA/3DModels/OBJ_PCB_LSM_Module.obj
120.8 x 81.5 x 7.78

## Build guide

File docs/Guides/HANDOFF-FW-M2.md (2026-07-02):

# 0G LockControl LSM110A — Handoff Firmware (Milestone M2)

**Empresa:** 0G IoT Solutions (previamente WND México)
**Web:** https://0giotsolutions.com/
**Repo:** [github.com/jdiaznxt/0G-LockControl-LSM110A](https://github.com/jdiaznxt/0G-LockControl-LSM110A)
**Autor:** Yahir Flores — yflores@iotnet.mx
**Co-desarrollo:** José Francisco Díaz (Franco) — jdiaz@iotnet.mx
**Versión:** 1.0 — Junio 2026

---

## Índice

1. [Contexto del proyecto](#1-contexto-del-proyecto)
2. [Setup del entorno](#2-setup-del-entorno)
3. [Estado actual del firmware](#3-estado-actual-del-firmware)
4. [Cambios pendientes en main.c (SDK)](#4-cambios-pendientes-en-mainc-sdk)
5. [Backlog M2 dividido Yahir / Franco](#5-backlog-m2-dividido-yahir--franco)
6. [Convenciones de código](#6-convenciones-de-código)
7. [Prompt de arranque para Claude Code](#7-prompt-de-arranque-para-claude-code)
8. [Referencias rápidas](#8-referencias-rápidas)
9. [Mapa completo de archivos (rutas absolutas)](#9-mapa-completo-de-archivos-rutas-absolutas)

---

## 1. Contexto del proyecto

**Producto:** dispositivo de detección de apertura de puerta con transmisión Sigfox 0G RC2 México. Basado en el módulo **LSM110A** (STM32WL con firmware API integrado). Batería CR2450, low-power modo Stop2, wake-up por acelerómetro LIS2DW12 (I2C) y sensor magnético reed/DRV5032 (GPIO EXTI).

**Milestone actual:** M2 Firmware (semanas 2-5 del roadmap 12-week MVP).

**Estado M0/M1:**
- M0 Setup — completado: repo, spec v1.0, SDK clonado y compilado, TX Sigfox validado en Nucleo con backend 0G.
- M1 Esquemático — responsabilidad HW (Lead), avanza en paralelo.

**Roadmap posterior:**
| Milestone | Alcance | Semanas |
|---|---|---|
| M2 | FW Nucleo (accel + reed + Sigfox) | 2-5 |
| M3 | PCB layout + gerbers | 5-7 |
| M4 | Low power validado en Nucleo | 7-8 |
| M5 | PCB fabricada y ensamblada | 8-11 |
| M6 | Integración FW en PCB custom | 11-12 |
| M7 | Prueba de campo | 12 |

---

## 2. Setup del entorno

### 2.1 Repositorios

| Repo | Ruta local | Propósito |
|---|---|---|
| `0G-LockControl-LSM110A` | `~/GitHub/0G-LockControl-LSM110A` | Repo principal del producto (drivers, docs, spec) |
| `Support-SJI/LSM110A` | `~/GitHub/LSM110A` | SDK oficial del fabricante SJI (Nucleo + LSM110A) |

**Importante:** el SDK vive **fuera** del repo principal. Los drivers custom se enlazan vía linked resources (no se copian) para mantener una sola fuente de verdad versionada.

### 2.2 Proyecto STM32CubeIDE

**Ruta a importar:**
```
~/GitHub/LSM110A/Projects/NUCLEO-WL55JC/Applications/LoRaWAN_SigFox/LSM1x0A/STM32CubeIDE
```

**Nombre del proyecto:** `LSM1x0A_SDK_LoRaWAN_Sigfox`

**Toolchain:** GNU Tools for STM32 13.3.rel1 (viene con CubeIDE)

### 2.3 Reloj y periféricos

- **SYSCLK:** HSI a **16 MHz**
- **PCLK1:** 16 MHz (I2C1 usa PCLK1)
- **I2C1:** 100 kHz Standard Mode — `Timing = 0x10707DBC` (valor oficial ST para 16 MHz)
- **GPIO relevantes:**
  - `PA0` — INT1 del LIS2DW12 (EXTI0, rising, pull-down)
  - `PA1` — reed switch / DRV5032 (EXTI1, both edges, pull-up)
  - `PA9` — I2C1_SCL (AF4, open-drain, sin pull interno — usar pull-up externo 4.7 kΩ)
  - `PA10` — I2C1_SDA (AF4, open-drain, sin pull interno)

### 2.4 Import de drivers al proyecto CubeIDE

> **✅ Ya aplicado (1-jul-2026):** los linked resources de `drivers/` y `app/`
> (incluye `app_sensors.c/.h` y `payload_codec.c/.h`) ya están en el
> `.project`/`.cproject`, junto con los include paths físicos y los sources HAL
> de I2C/IWDG. **No repetir estos pasos.** Detalle en `docs/sdk-patches.md`.
> Los pasos siguientes quedan como referencia para un re-clone del SDK.

Los drivers custom viven en `~/GitHub/0G-LockControl-LSM110A/Firmware/drivers/` y se importan al proyecto como **linked resources**:

1. Click derecho sobre `Application/User` → `New` → `Folder` → nombre: `drivers`.
2. Click derecho sobre la nueva carpeta → `Import` → `General` → `File System`.
3. `From directory:` `/Users/yflores/GitHub/0G-LockControl-LSM110A/Firmware/drivers`.
4. Seleccionar los 6 archivos: `bsp_lockcontrol.c/.h`, `lis2dw12.c/.h`, `reed_switch.c/.h`. **NO** importar `.gitkeep` ni `README.md`.
5. Click `Advanced` → marcar:
   - ✅ **Create links in workspace**
   - ✅ **Create virtual folders**
   - ✅ **Create link locations relative to:** `PROJECT_LOC`
6. `Finish`.

**Include path:**
- `Project` → `Properties` → `C/C++ Build` → `Settings` → `MCU GCC Compiler` → `Include paths` → añadir `../Application/User/drivers`.

---

## 3. Estado actual del firmware

### 3.1 Drivers ya escritos y validados en build (0 errores)

**Ubicación:** `Firmware/drivers/` en el repo principal.

| Archivo | Propósito |
|---|---|
| `bsp_lockcontrol.c/.h` | BSP: init I2C1 + GPIO EXTI0/1 + IRQ handlers |
| `lis2dw12.c/.h` | Driver acelerómetro I2C (WHO_AM_I, wake-up config, event API) |
| `reed_switch.c/.h` | Driver sensor magnético con debounce 50 ms |
| `README.md` | Guía de integración y uso |

### 3.2 Filosofía de diseño

- **ISR minimalista, main loop procesa.** El callback EXTI solo levanta un flag `volatile bool event_pending`. La lectura de registros por I2C (LIS2DW12) o del pin (reed) se hace en el main loop / task.
- **Handles inyectados.** Los drivers reciben `I2C_HandleTypeDef*` y `GPIO_TypeDef*` por parámetro. Ningún acoplamiento a hardware específico.
- **Sin FreeRTOS ni RTOS.** Compatibles con super-loop simple y con el scheduler cooperativo `stm32_seq.h` del SDK.

### 3.3 Build actual

Último build (1-jul-2026, headless CubeIDE): `0 errors, 6 warnings, ~19 s` —
**primer build que compila y linkea realmente los drivers custom + app_sensors
+ payload codec** (los builds previos no incluían los linked resources; ver
`docs/sdk-patches.md`, hallazgo 1).

Los 6 warnings son pre-existentes del SDK (3× `usart.h:32`, `lora_at.c:2970`,
`sgfx_app_api.c:175`, linker RWX) — no de nuestro código. Ignorables.

---

## 4. Cambios pendientes en main.c (SDK)

> **✅ Ya aplicado (1-jul-2026)** con un diseño mejorado: `g_accel`/`g_reed` no
> viven en `main.c` sino como estáticos de `Firmware/app/app_sensors.c` (repo
> principal, versionado). `main.c` solo llama `BSP_LockControl_Init()` y
> despacha las EXTI a `app_sensors_notify_*_isr()`, que agendan tasks del
> sequencer (Y3). El detalle exacto de cada edit al SDK está en
> **`docs/sdk-patches.md`**. Las subsecciones 4.1-4.5 quedan como referencia
> histórica del plan original.

**Archivo a editar:** `Core/Src/main.c` (dentro del proyecto CubeIDE, es decir en `~/GitHub/LSM110A/Projects/NUCLEO-WL55JC/Applications/LoRaWAN_SigFox/LSM1x0A/Core/Src/main.c`).

**Advertencia:** este archivo vive en el SDK clonado, no en el repo principal. Los cambios se hacen directo. Documentar cada edit para reproducibilidad.

### 4.1 Cambio 1 — Includes

**Después de la línea `#include "radio_board_if.h"` (línea 26):**

```c
/* USER CODE BEGIN Includes */
#include "bsp_lockcontrol.h"
#include "lis2dw12.h"
#include "reed_switch.h"
/* USER CODE END Includes */
```

### 4.2 Cambio 2 — Variables globales

**Después de `uint32_t active_app;` (línea 30):**

```c
/* USER CODE BEGIN PV */
lis2dw12_t    g_accel;
reed_switch_t g_reed;
/* USER CODE END PV */
```

### 4.3 Cambio 3 — Init de BSP y drivers

**Después de `SystemClock_Config();` (línea 44) y antes de `active_app = SystemApp_Init();`:**

```c
  /* USER CODE BEGIN SysInit */
  BSP_LockControl_Init();

  lis2dw12_init_handle(&g_accel, &hi2c1);
  reed_switch_init(&g_reed, REED_GPIO_PORT, REED_PIN, 50);
  /* USER CODE END SysInit */
```

### 4.4 Cambio 4 — HAL_GPIO_EXTI_Callback

**Reemplazar el bloque vacío `USER CODE BEGIN 4` / `USER CODE END 4` (líneas 112-114) por:**

```c
/* USER CODE BEGIN 4 */
void HAL_GPIO_EXTI_Callback(uint16_t GPIO_Pin)
{
    if (GPIO_Pin == ACCEL_INT1_PIN) {
        lis2dw12_on_interrupt(&g_accel);
    }
    else if (GPIO_Pin == REED_PIN) {
        reed_switch_on_interrupt(&g_reed);
    }
}
/* USER CODE END 4 */
```

### 4.5 Verificación

Después de los 4 cambios: `Cmd+B`.

- **Esperado:** 0 errores, warnings pueden subir a 8 por `g_accel/g_reed defined but not used` (esperado hasta que se enganche el polling en `app_sigfox.c`).
- **Si falla:** verificar que el include path incluye `../Application/User/drivers`.

---

## 5. Backlog M2 dividido Yahir / Franco

Objetivo: cerrar M2 en las semanas restantes. División basada en fuerzas: Yahir en drivers / integración app, Franco en payload / networking / testing.

### 5.1 Yahir (drivers + wake-up completo)

| ID | Estado | Tarea | Archivo(s) | Criterio de aceptación |
|---|---|---|---|---|
| Y1 | ✅ 1-jul | Config wake-up LIS2DW12 en boot | `Firmware/app/app_sensors.c` | `lis2dw12_config_wakeup(200)` tras WHO_AM_I (con 3 reintentos). Log UART: "Accel OK, WHO_AM_I=0x44". |
| Y2 | ✅ 1-jul | Polling en main loop del Sigfox | `app_sensors.c` + `app_sigfox.c` | Tasks del sequencer procesan y disparan TX real (`SIGFOX_API_send_frame`, cooldown 60 s); `app_sensors_poll()` como red de seguridad en `MX_Sigfox_Process`. |
| Y3 | ✅ 1-jul | Enganche al scheduler `stm32_seq.h` | `utilities_def.h`, `main.c`, `app_sensors.c` | `CFG_SEQ_Task_ACCEL_EVENT`/`REED_EVENT` definidas, registradas con `UTIL_SEQ_RegTask`, disparadas con `UTIL_SEQ_SetTask` desde el callback EXTI. |
| Y4 | ⬜ | Test bench en Nucleo | — | Golpear la mesa → log `EVT accel` + TX. Alejar imán → log `EVT reed` + TX. Payload visible en backend. Documentar con foto/GIF en `docs/Images/`. |
| Y5 | ⚠️ ver nota | IWDG watchdog | `bsp_lockcontrol.c` + `app_sigfox.c` | Implementado con `LOCKCONTROL_IWDG_ENABLE` (default 0) y timeout 16 s. **4 s era inviable:** el TX Sigfox RC2 bloquea 7-9 s y el build actual duerme en Stop2 (IWDG resetearía en idle). Habilitar solo en bench con `LOW_POWER_DISABLE=1`; solución definitiva en M4 (option byte `IWDG_STOP=frozen`). Ver `docs/sdk-patches.md`, hallazgo 4. |

### 5.2 Franco (payload + Sigfox + testing)

| ID | Tarea | Archivo(s) | Criterio de aceptación |
|---|---|---|---|
| F1 | Serializer payload 12 bytes | `Firmware/app/payload.c/.h` (nuevo) | Struct `lockcontrol_payload_t` según spec sec 4.4. Función `payload_pack(*payload, uint8_t buf[12])` en big-endian. Unit test con vector conocido. |
| F2 | Parser payload 12 bytes | mismo archivo | Función `payload_unpack(uint8_t buf[12], *payload)`. Round-trip test: pack → unpack devuelve struct original. |
| F3 | Integración TX Sigfox | `app_sigfox.c` | Función `sigfox_send_alarm(source, magnitude, axis, reed_state)`. Usa `SGFX_APP_ExecUplink(...)` del SDK. Cooldown 60 s entre TX. |
| F4 | Heartbeat 24h | `app_sensors.c` | RTC alarm cada 24 h. Payload con `bateria%`, `temp`, `conteo_eventos`, `reed_state actual`. |
| F5 | Validación end-to-end backend Sigfox | — | Payload recibido en backend.sigfox.com. Decodificado correctamente en callback. Screenshot en `docs/Images/`. |

### 5.3 Bloqueos y dependencias

- **Y2 bloquea F3** — Franco necesita que Yahir exponga la API `sensors_get_last_event()` para armar payload.
- **F1 bloquea Y2** — Yahir necesita el serializer para armar el payload dentro del polling.
- **Solución:** F1 primero (2-3 horas), luego Y2 en paralelo con F3.

### 5.4 Fuera de M2 (para M4 y adelante)

- Stop2 low power validado con multímetro.
- FUOTA — no aplica al MVP (Sigfox uplink-first).
- Callback URL en backend — es rol **Persona (App)** en Notion, no FW.

---

## 6. Convenciones de código

### 6.1 Naming

- **Funciones públicas del driver:** `<driver>_<verb>()`. Ej: `lis2dw12_read_reg`, `reed_switch_process_event`.
- **Prefijos globales:** `g_` para singletons (`g_accel`, `g_reed`).
- **Macros:** `SNAKE_UPPER`. `#define ACCEL_INT1_PIN GPIO_PIN_0`.
- **Enums:** `PascalCase` para el tipo, `SNAKE_UPPER` para valores. Ej: `reed_state_t { REED_CLOSED, REED_OPEN }`.

### 6.2 Return types

- Drivers devuelven un enum de status (`lis2dw12_status_t`). Nunca `int` o `bool` para operaciones que pueden fallar.
- Funciones que no pueden fallar devuelven `void`.

### 6.3 ISR vs main loop

- **En ISR** — solo escritura a variables `volatile`. Nada de I/O bloqueante (I2C, UART, SPI). Máximo 5-10 µs por llamada.
- **En main loop / task** — todo lo demás. Se puede bloquear con timeouts razonables.

### 6.4 Comentarios

- Comentarios de header estilo Doxygen (`/**  ... */`).
- En línea: castellano técnico, sin acentos (para evitar problemas de encoding en toolchains viejos).
- Explicar el **por qué**, no el **qué**.

### 6.5 Git

- Rama principal: `main`.
- Feature branches: `feature/<milestone>-<tarea>`, ej: `feature/m2-payload`.
- Commits en formato conventional: `feat(fw):`, `fix(drivers):`, `docs:`, `chore:`.

### 6.6 Empresa en documentos

Todo documento entregado en el repo debe referirse a **0G IoT Solutions**. La forma "previamente WND México" o "IOTNET México" se puede usar en contexto formal donde aporte contexto histórico. URL: https://0giotsolutions.com/.

---

## 7. Prompt de arranque para Claude Code

**Contexto que debes proporcionarle en la primera interacción:**

```
Eres asistente de firmware embebido para el proyecto 0G LockControl LSM110A
de 0G IoT Solutions (previamente WND México).

Repositorios locales:
- Repo principal: ~/GitHub/0G-LockControl-LSM110A
- SDK del fabricante: ~/GitHub/LSM110A (Support-SJI/LSM110A)

Rol asignado: firmware developer trabajando en Milestone M2. El estado actual
y las tareas asignadas están en docs/Guides/HANDOFF-FW-M2.md del repo principal.
Léelo COMPLETO antes de responder cualquier cosa.

Hardware:
- MCU: STM32WL55JC (dev en Nucleo-WL55JC, luego LSM110A en PCB custom).
- Toolchain: STM32CubeIDE 1.18+, GCC arm-none-eabi.
- SYSCLK: 16 MHz HSI. PCLK1: 16 MHz.
- I2C1 PA9/PA10 a 100 kHz (Timing 0x10707DBC).
- EXTI0 = PA0 (accel INT1). EXTI1 = PA1 (reed switch).

Convenciones ya establecidas:
- Drivers en Firmware/drivers/ del repo principal, importados al proyecto
  CubeIDE con linked resources (no copias).
- ISR-safe: solo levantar flags en interrupciones, I/O en main loop.
- Sin RTOS. Compatibles con super-loop y con stm32_seq.h del SDK.
- Retornos de driver: enums de status, no int/bool.

Estilo de respuesta:
- Español conciso, sin acentos en comentarios de código.
- Cuando propongas cambios, incluye ruta absoluta y el diff exacto.
- Cuando toques main.c del SDK, avisa que es un archivo del clone del SDK
  (no del repo principal).
- Empresa: "0G IoT Solutions" en cualquier documento generado.

Primer request del usuario:
[AQUÍ VA LA TAREA CONCRETA — por ejemplo:
 "implementa la tarea F1 del backlog: serializer payload 12 bytes"
 "engancha el driver LIS2DW12 al scheduler stm32_seq del SDK"]
```

### 7.1 Buenas prácticas al usarlo

- **No pegarle todo el repo.** Claude Code puede navegar; solo dale rutas y él lee.
- **Una tarea a la vez.** Cerrar Y1 antes de pasar a Y2 o cambiar el foco.
- **Verificar builds antes de siguiente tarea.** `arm-none-eabi-gcc` debe salir con 0 errores.
- **Commits atómicos.** No dejar que combine dos features en un commit.

---

## 8. Referencias rápidas

### 8.1 Documentación técnica

- [Datasheet STM32WL55JC](https://www.st.com/en/microcontrollers-microprocessors/stm32wl55jc.html)
- [Reference Manual STM32WL (RM0453)](https://www.st.com/resource/en/reference_manual/rm0453-stm32wl5x-advanced-armbased-32bit-mcus-stmicroelectronics.pdf)
- [Datasheet LIS2DW12](https://www.st.com/resource/en/datasheet/lis2dw12.pdf)
- [Application Note LIS2DW12 (AN5038)](https://www.st.com/resource/en/application_note/an5038-lis2dw12-3axis-mems-accelerometer-ultralowpower-stmicroelectronics.pdf)
- [SDK Support-SJI/LSM110A](https://github.com/Support-SJI/LSM110A)

### 8.2 Backend y herramientas

- Backend Sigfox: https://backend.sigfox.com
- Grupo del proyecto: `DHW`
- Zona: **RC2 México** — 902.1782 MHz
- Device Nucleo actual (validado el 29-mayo-2026):
  - Device ID: `033E07FC`
  - PAC (rotado): `BC07485F3FFF8B71`

### 8.3 Recursos internos

- Notion Hub: [0G LockControl — Hub del Proyecto](https://star-muskmelon-e73.notion.site/0G-LockControl-Hub-del-Proyecto-35a00f12d6428186937acde842960f08)
- Notion Task Board: 53 tareas del MVP filtrables por milestone/responsable/semana.
- Guía de flujo de trabajo diario: notion.site/Flujo-de-trabajo-diario-Guia

### 8.4 Contactos

| Rol | Persona | Email |
|---|---|---|
| FW Lead | Yahir Flores | yflores@iotnet.mx |
| HW / co-FW | José Francisco Díaz (Franco) | jdiaz@iotnet.mx |

---

---

## 9. Mapa completo de archivos (rutas absolutas)

Toda ruta es local a la Mac de Yahir. Claude Code puede leer/editar directamente.

### 9.1 Repo principal — `~/GitHub/0G-LockControl-LSM110A`

**Documentación y specs:**

| Ruta | Descripción |
|---|---|
| `/Users/yflores/GitHub/0G-LockControl-LSM110A/README.md` | README del producto |
| `/Users/yflores/GitHub/0G-LockControl-LSM110A/docs/spec-producto.md` | Spec v1.0 |
| `/Users/yflores/GitHub/0G-LockControl-LSM110A/docs/pinout-lsm110a.md` | Pinout completo del LSM110A |
| `/Users/yflores/GitHub/0G-LockControl-LSM110A/docs/arquitectura-justificacion.md` | Justificación arquitectura |
| `/Users/yflores/GitHub/0G-LockControl-LSM110A/docs/decisiones-tecnicas.md` | Log de decisiones |
| `/Users/yflores/GitHub/0G-LockControl-LSM110A/docs/Guides/HANDOFF-FW-M2.md` | **Este documento** |
| `/Users/yflores/GitHub/0G-LockControl-LSM110A/docs/Guides/Guia_completa_NUCLEO-WL55JC_Sigfox.pdf` | Guía end-to-end del aprovisionamiento Sigfox |

**Drivers (linked resources en el proyecto CubeIDE):**

| Ruta | Descripción |
|---|---|
| `/Users/yflores/GitHub/0G-LockControl-LSM110A/Firmware/drivers/bsp_lockcontrol.h` | Header BSP |
| `/Users/yflores/GitHub/0G-LockControl-LSM110A/Firmware/drivers/bsp_lockcontrol.c` | Init I2C1 + EXTI + IRQ handlers |
| `/Users/yflores/GitHub/0G-LockControl-LSM110A/Firmware/drivers/lis2dw12.h` | Header driver acelerómetro |
| `/Users/yflores/GitHub/0G-LockControl-LSM110A/Firmware/drivers/lis2dw12.c` | Implementación LIS2DW12 |
| `/Users/yflores/GitHub/0G-LockControl-LSM110A/Firmware/drivers/reed_switch.h` | Header sensor magnético |
| `/Users/yflores/GitHub/0G-LockControl-LSM110A/Firmware/drivers/reed_switch.c` | Implementación reed / DRV5032 |
| `/Users/yflores/GitHub/0G-LockControl-LSM110A/Firmware/drivers/README.md` | Guía de uso de drivers |

**Carpetas destino para nuevo código (aún vacías, `.gitkeep` como placeholder):**

| Ruta | Uso previsto |
|---|---|
| `/Users/yflores/GitHub/0G-LockControl-LSM110A/Firmware/app/` | Lógica de aplicación (F1, F2, Y2) — `payload.c/.h`, `event_dispatch.c/.h`, etc. |
| `/Users/yflores/GitHub/0G-LockControl-LSM110A/Firmware/config/` | Config del proyecto — `.ioc`, linker scripts, `credenciales_sigfox.h` |
| `/Users/yflores/GitHub/0G-LockControl-LSM110A/Firmware/libs/` | Librerías externas si se aíslan del SDK |
| `/Users/yflores/GitHub/0G-LockControl-LSM110A/Firmware/tools/` | Scripts (flash, decoders Python, etc.) |
| `/Users/yflores/GitHub/0G-LockControl-LSM110A/Firmware/src/` | Reservado — actualmente vacío (se movió a app/ y drivers/) |

**Referencias históricas:**

| Ruta | Descripción |
|---|---|
| `/Users/yflores/GitHub/0G-LockControl-LSM110A/Firmware/src/main_reference_nucleo.c` | Código de referencia validado en Nucleo (Oct-Ene 2025-2026). NO es el código final; sirve como referencia. |
| `/Users/yflores/GitHub/0G-LockControl-LSM110A/Acondicionamiento del NUCLEO-WL55JC al backend de Sigfox/` | Procedimiento completo de vinculación al backend Sigfox 0G |

### 9.2 SDK del fabricante — `~/GitHub/LSM110A`

Base: `/Users/yflores/GitHub/LSM110A/Projects/NUCLEO-WL55JC/Applications/LoRaWAN_SigFox/LSM1x0A`

**Archivos del SDK que se editan en M2:**

| Ruta absoluta | Editar para |
|---|---|
| `/Users/yflores/GitHub/LSM110A/Projects/NUCLEO-WL55JC/Applications/LoRaWAN_SigFox/LSM1x0A/Core/Src/main.c` | Sección 4 de este doc — includes, globals, init BSP, HAL_GPIO_EXTI_Callback |
| `/Users/yflores/GitHub/LSM110A/Projects/NUCLEO-WL55JC/Applications/LoRaWAN_SigFox/LSM1x0A/Core/Inc/main.h` | Añadir `extern I2C_HandleTypeDef hi2c1;` si no se resuelve por include chain |
| `/Users/yflores/GitHub/LSM110A/Projects/NUCLEO-WL55JC/Applications/LoRaWAN_SigFox/LSM1x0A/Core/Src/stm32wlxx_it.c` | (Solo si el linker se queja de handlers duplicados — no debería) |
| `/Users/yflores/GitHub/LSM110A/Projects/NUCLEO-WL55JC/Applications/LoRaWAN_SigFox/LSM1x0A/Sigfox/App/app_sigfox.c` | Tareas Y2, F3 — enganche del polling / envío Sigfox |
| `/Users/yflores/GitHub/LSM110A/Projects/NUCLEO-WL55JC/Applications/LoRaWAN_SigFox/LSM1x0A/Sigfox/App/app_sigfox.h` | Declarar funciones expuestas de la app |
| `/Users/yflores/GitHub/LSM110A/Projects/NUCLEO-WL55JC/Applications/LoRaWAN_SigFox/LSM1x0A/Core/Src/sys_app.c` | Config de bajo nivel de la app del SDK (usualmente no se toca) |

**Archivos del SDK de solo lectura (referencia, NO editar):**

| Ruta | Descripción |
|---|---|
| `/Users/yflores/GitHub/LSM110A/Drivers/STM32WLxx_HAL_Driver/` | HAL de STM (I2C, GPIO, RCC, etc.) |
| `/Users/yflores/GitHub/LSM110A/Middlewares/Third_Party/Sigfox/` | Stack Sigfox propietario ST |
| `/Users/yflores/GitHub/LSM110A/Middlewares/Third_Party/SubGHz_Phy/` | Capa PHY de radio |
| `/Users/yflores/GitHub/LSM110A/Utilities/sequencer/stm32_seq.c` | Scheduler cooperativo (usarlo, no modificar) |
| `/Users/yflores/GitHub/LSM110A/Utilities/lpm/tiny/stm32_lpm.c` | Gestor de low power modes |

**Proyecto CubeIDE:**

| Ruta | Uso |
|---|---|
| `/Users/yflores/GitHub/LSM110A/Projects/NUCLEO-WL55JC/Applications/LoRaWAN_SigFox/LSM1x0A/STM32CubeIDE/.project` | Archivo del workspace CubeIDE (auto-gestionado) |
| `/Users/yflores/GitHub/LSM110A/Projects/NUCLEO-WL55JC/Applications/LoRaWAN_SigFox/LSM1x0A/STM32CubeIDE/.cproject` | Config del compilador CDT (linked resources aparecen aquí como `<link>`) |
| `/Users/yflores/GitHub/LSM110A/Projects/NUCLEO-WL55JC/Applications/LoRaWAN_SigFox/LSM1x0A/STM32CubeIDE/Debug/LSM1x0A_SDK_LoRaWAN_Sigfox.elf` | Output del build (regenerado en cada build) |
| `/Users/yflores/GitHub/LSM110A/Projects/NUCLEO-WL55JC/Applications/LoRaWAN_SigFox/LSM1x0A/STM32CubeIDE/Debug/LSM1x0A_SDK_LoRaWAN_Sigfox.hex` | Firmware flasheable |

### 9.3 Convención de acceso para Claude Code

- **Puede leer libremente:** todo lo listado arriba.
- **Puede editar sin preguntar:** el repo principal `0G-LockControl-LSM110A` completo.
- **Editar previo aviso:** archivos del SDK bajo `~/GitHub/LSM110A/Projects/...`. Es un clone de repo externo, así que documentar cada edit en el commit message del repo principal (via un archivo `docs/sdk-patches.md` si se acumulan varios).
- **No tocar:** todo lo que esté bajo `Drivers/`, `Middlewares/`, `Utilities/` del SDK (líneas HAL / stack Sigfox / scheduler). Si algo falta ahí, es señal de que se necesita otra estrategia (fork del SDK, submodule, etc.).

---

**Empresa operadora:** 0G IoT Solutions (previamente WND México) — https://0giotsolutions.com/

*Documento vivo — actualizar en cada cierre de milestone.*

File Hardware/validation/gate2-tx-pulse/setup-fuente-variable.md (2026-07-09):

# GATE 2 — Fuente variable y emulación de CR2450 (issue #6)

> Guía de equipo y setup para medir el pulso TX con soporte del cap de 470 µF.
> Complementa el checklist del [issue #6](https://github.com/jdiaznxt/0G-LockControl-LSM110A/issues/6).
> El reporte final GO/NO-GO va en `REPORT.md` en esta misma carpeta.

## 1. Por qué no sirve alimentar por USB / puerto serial

Hallazgo correcto: **con el Nucleo alimentado por el USB del ST-LINK la prueba del
GATE 2 es inválida.** Tres razones:

1. **Es una fuente "dura".** El riel 5 V USB → regulador 3.3 V del Nucleo tiene
   impedancia de salida de miliohms: entrega el pico de TX sin caída de voltaje.
   El cap de 470 µF nunca se descarga y no hay dip que medir. Lo que el GATE 2
   mide es justamente el efecto de la **resistencia interna (IR ~10–40 Ω) de la
   CR2450**, que el USB no tiene.
2. **No se puede variar el voltaje** para reproducir batería fresca / 50% / EOL.
3. **Lazo de tierra.** El USB une el GND de la placa con el GND de la PC, y el
   osciloscopio une su GND a tierra física → ruido y offsets en una medición de
   decenas/cientos de mV.

## 2. Requisitos de la fuente (esto pesa más que la marca)

| Requisito | Valor | Por qué |
|---|---|---|
| Topología | **Lineal** (no conmutada) | Ripple <1–2 mVrms; una conmutada mete spikes del orden del dip que buscamos |
| Resolución | 10 mV / 1 mA | Barrer 1.8–3.3 V con precisión |
| Límite de corriente (CC) | Ajustable, usar ~0.3–0.5 A | Solo como protección — ver §4 |
| Corriente máxima | ≥1 A (sobra) | Pico TX ~50 mA @+14 dBm; ~123 mA si se prueba +22 dBm |
| Salida | Flotante (aislada de tierra) | Evita lazos con osciloscopio y ST-LINK |
| Deseable | Programable USB/RS-232 (SCPI) | Automatizar barridos de voltaje y logging |

## 3. Modelos recomendados (disponibilidad México, jul-2026)

| Opción | Modelo | Specs | Precio aprox. | Dónde |
|---|---|---|---|---|
| **Recomendada (calidad/precio)** | **Korad KA3005D / KD3005D** | Lineal 30 V/5 A, 10 mV/1 mA | ~$2,500–5,500 MXN según vendedor | Mercado Libre MX, Amazon MX, DigiKey MX |
| Variante programable | Korad KA3005**P** / KD3005**P** | + USB/RS-232 SCPI | +$500–800 MXN aprox. | Ídem |
| Paso arriba | **Rigol DP711** | Lineal 30 V/5 A, SCPI RS-232, transitorio <50 µs, OVP/OCP | ~$7,500 MXN | Amazon MX, FinalTest, ACMax |

Notas:
- Tenma 72-2540 y Velleman LABPS3005D son **rebrands de la misma Korad** — si
  aparecen más baratas, sirven igual.
- La DP711 se justifica si después se automatiza la validación low-power (M4)
  y el bring-up de la PCB (M6); para el GATE 2 solo, la Korad basta.
- **Evitar:** módulos buck tipo DPS3005/RD6006 y eliminadores conmutados — su
  ripple/spikes de conmutación (decenas de mV) contaminan la medición del dip.
- **No hace falta** un emulador de batería dedicado (Keysight E36731A, ITECH
  IT6412 con resistencia de salida programable, >$40k MXN): la resistencia
  serie de §4 logra lo mismo para este gate.

## 4. Punto crítico: la fuente sola TAMPOCO muestra el dip

Una fuente de banco también es una fuente dura. Conectada directa al módulo se
comporta igual que el USB: cero caída, prueba inválida. **Hay que emular la
resistencia interna de la CR2450 con una resistencia serie Rs:**

```
Fuente (V_oc) ──── Rs ────┬──── VDD módulo / 3V3 Nucleo
                          │
                       470 µF          ← el cap bajo prueba, después de Rs
                          │
GND fuente ───────────────┴──── GND placa ──── GND punta osciloscopio
```

| Estado CR2450 emulado | V fuente (circuito abierto) | Rs serie |
|---|---|---|
| Fresca | 3.0–3.2 V | 10–15 Ω |
| ~50% descarga | 2.8–2.9 V | 22–33 Ω |
| EOL | 2.0–2.2 V | 39–47 Ω |

- Rs: resistencias de **1–2 W** (a 100 mA sobre 47 Ω son ~0.5 W). Valores E12
  útiles: 10, 22, 33, 47 Ω. Cables cortos, todo en la protoboard del setup.
- **El límite CC de la fuente se deja ARRIBA del pico esperado (0.3–0.5 A)**
  para que nunca entre en modo CC: quien limita es Rs. Si la fuente entra en
  CC, su respuesta transitoria distorsiona la forma del dip.
- La punta del osciloscopio va en VDD **después de Rs** (sobre el cap), tierra
  de la punta lo más corta posible (spring/tip ground, no el caimán largo).
- Bonus perfil de corriente: shunt de 1 Ω entre Rs y el cap, canal 2 del
  osciloscopio midiendo su caída → I = V/1 Ω.

Con este arreglo además se puede **encontrar el umbral real de brown-out** de
forma reproducible: bajar V de la fuente de 100 en 100 mV hasta que el módulo
resetee durante TX, algo imposible de hacer de forma controlada con pilas.

## 5. Procedimiento con el Nucleo-WL55JC (sin serial)

Aprovecha el demo de 3 botones (`Acondicionamiento .../Programa_3_botones/`):
la TX se dispara por push-button, así que el USB no hace falta durante la medición.

1. **Flashear por USB/ST-LINK** el programa de botones. Verificar TX normal.
2. **Desconectar el USB por completo.**
3. Alimentar desde fuente + Rs + cap 470 µF por una de dos vías (UM2592):
   - **Pin 3V3** (CN6/CN7): alimenta el riel 3.3 V bypasseando el regulador.
     Simple, pero las cargas extra de la placa suman caída constante en Rs.
   - **Jumper IDD (JP2)**: retirar el jumper y alimentar el lado MCU →
     alimenta solo el dominio del STM32WL55. Medición más limpia (preferida).
4. Osciloscopio en VDD, trigger por flanco de bajada (nivel ~50–100 mV bajo el
   V de reposo), o trigger por GPIO si el firmware saca un pulso pre-TX.
5. Disparar TX con B1/B2/B3. En RC2 `SIGFOX_API_send_frame` bloquea **7–9 s y
   manda 3 frames** → capturar los 3 dips en una sola ventana (2 s/div) y
   luego hacer zoom al peor. El VDD_min del peor frame es el dato del gate.
6. Confirmación de recepción: backend Sigfox (flujo ya validado en issue #2).
7. Repetir la matriz fresca/50%/EOL de §4 y registrar VDD_min de cada caso.

## 6. Lo que la fuente NO reemplaza

El veredicto GO/NO-GO del issue #6 pide **CR2450 reales** (fresca, 50%, EOL).
La fuente sirve para caracterizar el circuito de forma reproducible, dimensionar
el cap (comparar electrolítico genérico vs polímero low-ESR) y encontrar el
umbral de colapso **antes** de quemar pilas; la corrida final del reporte se
hace con las 3 pilas físicas y se documenta en `REPORT.md`.

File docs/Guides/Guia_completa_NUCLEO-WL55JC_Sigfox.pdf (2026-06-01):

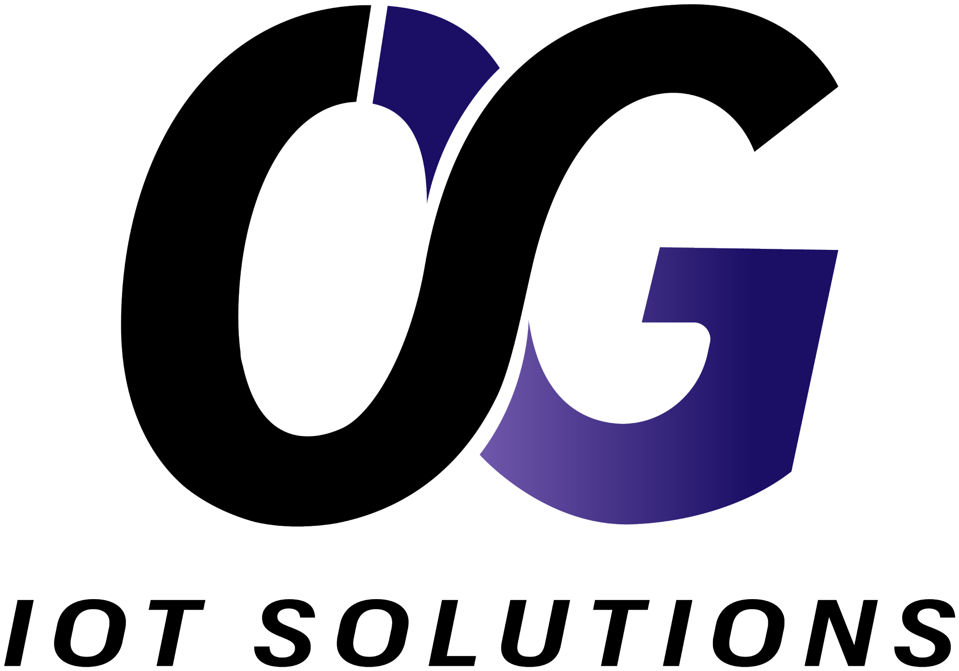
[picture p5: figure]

# Acondicionamiento del

# NUCLEO-WL55JC al backend de Sigfox

## Procedimiento de vinculacion end-to-end en la red 0G RC2

Guia tecnica de vinculacion

Flujo del ingeniero de hardware responsable

Como obtener PAC e ID del lado del chip, registrar el device en el backend Sigfox
y enviar el primer uplink al 0G Network
desde la placa NUCLEO-WL55JC con firmware

configurado para Radio Configuration 2 (RC2 Mexico).

0G IoT Solutions

Plataforma: | STMicroelectronics NUCLEO-WL55JC (MB1389)
Banda RF: | 902.2 MHz uplink (RC2 Mexico, FCC)
Tecnologia: | Sigfox 0G — Radio Configuration 2 (RC2)
Operador: | 0G IoT Solutions (previamente WND Mexico)
Stack: | STM32CubeWL V1.5.0
Documento base: | AN5480 Rev 8 (marzo 2025)
Autor: | Yahir Flores — Ingeniero de Hardware
Correo: | yflores@iotnet.mx
Fecha: | 29 de mayo de 2026
Version: | v1.0

Sitio web del operador: https://0giotsolutions.com/

Acondicionamiento del NUCLEO-WL55JC al backend de Sigfox | Pagina 2 de 27

## Resumen ejecutivo

Este documento describe el procedimiento completo para vincular una placa NUCLEO-WL55JC al backend de Sigfox bajo la configuracion regional RC2 (Mexico, 902.2 MHz uplink), incluyendo la extraccion de

credenciales del chip, su validacion en el portal sfxp de STMicroelectronics, la escritura de las credenciales en la flash del MCU y la verificacion end-to-end con el primer uplink. El procedimiento se completo exitosamente el 29 de mayo de 2026 con los siguientes resultados verificables:

- Firmware Sigfox_AT_Slave_CM4 V1.5.0 compilado y grabado en el MCU STM32WL55JCI.
- Chip certificate de 136 bytes extraido de 0x1FFF3F04 y validado por el portal my.st.com/sfxp.
- Credenciales reales emitidas por ST (ID, PAC, KEY AES-128) grabadas en 0x0803E500 (region

USER_Key_region_ROM).

- Device registrado en backend.sigfox.com con Device ID 033E07FC.
- Primer uplink exitoso recibido por la base station Sigfox 6BCE en 902.1782 MHz con RSSI -127 dBm (link quality AVERAGE).

El documento incluye los ocho pasos secuenciales del flujo, la lista de errores reales encontrados durante el procedimiento con sus soluciones, y los anexos tecnicos con direcciones de memoria, sintaxis AT compatible con V1.5.0, parametros RF normativos de RC2 Mexico y referencias oficiales.

Acondicionamiento del NUCLEO-WL55JC al backend de Sigfox | Pagina 1 de 27

## Contents

Resumen ejecutivo | 1
1 Contexto y objetivos | 4
2 Prerequisitos | 5
3 Roadmap secuencial de las 8 fases | 6
4 Fase 1: Instalacion del entorno | 7
5 Fase 2: Conexion fisica y verificacion HW | 8
6 Fase 3: Compilar y flashear Sigfox_AT_Slave_CM4 | 10
7 Fase 4: Extraer el chip certificate | 13
8 Fase 5: Portal sfxp y descarga de credenciales | 14
Acondicionamiento del NUCLEO-WL55JC al backend de Sigfox | Pagina 2 de 27

9 Fase 6: Escribir sigfox_data.bin en 0x0803E500 | 15
10 Fase 7: Validar y registrar en backend Sigfox | 17
11 Fase 8: Primer uplink y verificacion end-to-end | 19
12 Errores encontrados durante el comisionamiento y soluciones | 21
13 Anexos tecnicos | 25
14 Referencias y documentacion oficial | 26
15 Resumen ejecutivo del flujo | 27
Acondicionamiento del NUCLEO-WL55JC al backend de Sigfox | Pagina 3 de 27

## 1. Contexto y objetivos

### 1.1 Objetivo

Documentar y reproducir el procedimiento completo de vinculacion de una placa NUCLEO-WL55JC al backend de Sigfox bajo Radio Configuration 2 (RC2 Mexico), partiendo de un chip sin credenciales y

terminando con un uplink visible en el backend. El alcance cubre desde la instalacion de herramientas hasta la validacion del primer mensaje recibido por la red 0G.

### 1.2 Plataforma

- Placa STMicroelectronics NUCLEO-WL55JC (board MB1389) con MCU STM32WL55JCI (Cortex-M4 + Cortex-M0+).
- Stack STM32CubeWL V1.5.0 con la aplicacion Sigfox_AT_Slave_CM4 y la libreria propietaria

MW_SIGFOX V1.8.0.

- Red Sigfox 0G bajo RC2 Mexico (902.2 MHz uplink, 905.2 MHz downlink, FCC), operada por 0G IoT Solutions (previamente WND Mexico).

### 1.3 Resultados obtenidos

Variable | Valor
Device ID Sigfox | 033E07FC
PAC inicial (issued by ST) | B06EA49C9E0F11F4
PAC rotado post-registro | BC07485F3FFF8B71
Device Type | Nucleo_WL
Group | DHW
Contract | UnaTag_test (9 mensajes restantes tras registro previo)
Frecuencia uplink medida | 902.1782 MHz
Base station receptora | 6BCE
RSSI primer uplink | -127.00 dBm
Frames recibidos | 1 de 3 (TX1/TX2/TX3)
Link Quality Indicator | AVERAGE (3/5 barras)
Payload transmitido | 48656C6C6F (“Hello”)
Delay backend | 3.2 segundos

Table 1. Resultados del comisionamiento exitoso.

Acondicionamiento del NUCLEO-WL55JC al backend de Sigfox | Pagina 4 de 27

## 2. Prerequisitos

### 2.1 Hardware

- Placa NUCLEO-WL55JC (MB1389).
- Antena SMA macho compatible con banda 868/915 MHz (incluida en el kit estandar).
- Cable USB micro-B (longitud razonable; los muy largos a veces causan errores de enumeracion en macOS).
- Computadora con macOS, Windows o Linux (este documento detalla macOS).
- Cobertura Sigfox en el sitio de pruebas (verificar en https://coverage.sigfox.com).

### 2.2 Software

- STM32CubeIDE 2.0.0 o superior.
- STM32CubeProgrammer 2.6 o superior (critico: el boton de Sigfox Credentials se introdujo en 2.6).
- STM32CubeWL V1.5.0 descargado desde st.com, no desde GitHub (ver Capitulo 12, error 12.1).
- Cliente serial: Arduino IDE Serial Monitor, screen, o CoolTerm.
- Navegador con cookies habilitadas para my.st.com y backend.sigfox.com.

### 2.3 Cuentas y permisos

- Cuenta myST activa con acceso a sfxp.
- Cuenta admin en backend.sigfox.com con permisos sobre el grupo DHW (asignada por 0G IoT Solutions).
- Token disponible en algun contrato del grupo (al menos 1 mensaje libre para validar).
Acondicionamiento del NUCLEO-WL55JC al backend de Sigfox | Pagina 5 de 27

## 3. Roadmap secuencial de las 8 fases

El flujo completo se organiza en ocho fases consecutivas, agrupadas en cuatro etapas logicas: setup y hardware, extraccion de credenciales, flasheo y backend, y validacion final.

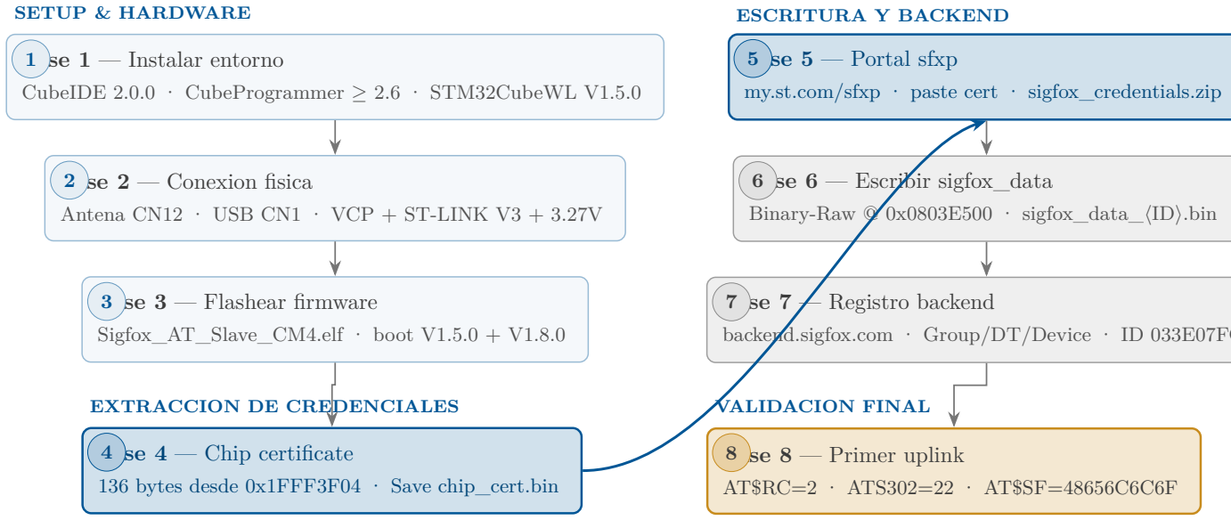
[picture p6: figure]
SETUP & HARDWARE; Fase 1 — Instalar entorno; Fase 2 — Conexion fisica; Fase 3 — Flashear firmware; EXTRACCION DE CREDENCIALES; Fase 4 — Chip certificate; Fase 5 — Portal sfxp; ESCRITURA Y BACKEND; Fase 6 — Escribir sigfox_data; Binary-Raw @ 0x0803E500 · sigfox_data_⟨ID⟩.bin; Fase 7 — Registro backend; VALIDACION FINAL; Fase 8 — Primer uplink; AT$RC=2 · ATS302=22 · AT$SF=48656C6C6F

CubeIDE 2.0.0 · CubeProgrammer ≥ 2.6 · STM32CubeWL V1.5.0

Antena CN12 · USB CN1 · VCP + ST-LINK V3 + 3.27V

Sigfox_AT_Slave_CM4.elf · boot V1.5.0 + V1.8.0

136 bytes desde 0x1FFF3F04 · Save chip_cert.bin my.st.com/sfxp · paste cert · sigfox_credentials.zip

backend.sigfox.com · Group/DT/Device · ID 033E07FC

Figure 1. Mapa de las 8 fases del procedimiento de vinculacion del NUCLEO-WL55JC al backend Sigfox RC2. Azul claro indica setup, azul fuerte la extraccion de credenciales (etapa critica), gris la escritura y backend, ambar la validacion final.

Lista textual:

1. Instalar herramientas (CubeIDE, CubeProgrammer, CubeWL desde st.com, cliente serial).
2. Conectar la placa, verificar ST-LINK V3, VCP y target voltage.
3. Compilar y flashear Sigfox_AT_Slave_CM4; validar boot banner y AT por VCP.
4. Extraer chip certificate de 136 bytes con CubeProgrammer (0x1FFF3F04).
5. Subir certificate a my.st.com/sfxp y descargar sigfox_credentials.zip.
6. Escribir sigfox_data_<ID>.bin en 0x0803E500 via CubeProgrammer.
7. Validar AT$ID y AT$PAC reales; verificar registro en backend Sigfox.
8. Enviar primer uplink AT$SF=48656C6C6F y validar recepcion en backend.
Acondicionamiento del NUCLEO-WL55JC al backend de Sigfox | Pagina 6 de 27

## 4. Fase 1: Instalacion del entorno

### 4.1 STM32CubeIDE 2.0.0

- Descarga: https://www.st.com/en/development-tools/stm32cubeide.html
- Requiere registro myST. Versiones macOS Intel/Apple Silicon disponibles.
- Instalar en ruta sin espacios. Drivers ST-LINK incluidos.

### 4.2 STM32CubeProgrammer 2.6+

Critico para nuestro flujo: la pestana Sigfox Credentials (que usaremos en Fases 4 y 6) solo existe en versiones ≥ 2.6. La version instalada en este comisionamiento fue 2.22.

### 4.3 STM32CubeWL V1.5.0 — IMPORTANTE: descargar de st.com

No clonar desde GitHub. El repositorio publico https://github.com/STMicroelectronics/STM32CubeWL no incluye la aplicacion Sigfox por restricciones de licencia (stack propietario de UnaBiz). Si clonas con git clone, la carpeta Applications/Sigfox/ no estara presente. Ver Capitulo 12, error 12.1.

Descarga oficial: https://www.st.com/en/embedded-software/stm32cubewl.html

Aceptar | el | license | agreement | (incluye | terminos | Sigfox/UnaBiz). | Bajara | un | ZIP | tipo

stm32cubewl-v1-5-0.zip de aproximadamente 78 MB.

Descomprimir en ruta limpia:

mv ~/STM32CubeWL ~/STM32CubeWL_github_old # backup del clone incompleto

mkdir -p ~/ST

cd ~/Downloads

unzip stm32cubewl-v1-5-0.zip -d ~/ST/

Verificar que ahora si trae la app Sigfox:

find ~/ST -type d -name "Sigfox_AT_Slave" 2>/dev/null

Resultado esperado:

/Users/yflores/ST/STM32Cube_FW_WL_V1.5.0/Projects/B-WL5M-SUBG1/Applications/Sigfox/Sigfox_AT_Slave

/Users/yflores/ST/STM32Cube_FW_WL_V1.5.0/Projects/NUCLEO-WL55JC1/Applications/Sigfox/Sigfox_AT_Slave

Usaremos la ruta NUCLEO-WL55JC1/... (banda alta 865–928 MHz), que es la apropiada para Sigfox RC2 Mexico (902.2 MHz uplink).

### 4.4 Cliente serial

En macOS screen viene preinstalado. Alternativas: CoolTerm (GUI), Arduino IDE Serial Monitor. Configuracion obligatoria: 9600 baud, 8N1, sin flow control, fin de linea CR (Carriage return).

Acondicionamiento del NUCLEO-WL55JC al backend de Sigfox | Pagina 7 de 27

## 5. Fase 2: Conexion fisica y verificacion HW

### 5.1 Conexion mecanica

1. Atornillar la antena SMA al conector CN12.
2. Verificar jumpers (configuracion de fabrica):
- JP1 (I_SoC): ON
- JP3 (BOOT0): ON
- JP4: posicion [1-2] (alimentacion desde ST-LINK USB)
- JP7 (5V_PWR): ON
3. Conectar USB micro-B en CN1 (lado ST-LINK).
4. Verificar que el LED5 verde (PWR) enciende.

### 5.2 Verificacion en macOS

ls /dev/cu.usbmodem*

ioreg -p IOUSB -l | grep -A 5 -i "stm32\|st-link\|stlink"

Esperado: enumera un puerto /dev/cu.usbmodemNNNN (el numero cambia entre reconexiones) y un

dispositivo USB STLINK-V3 con serial number.

El mass storage NODE_WL55JC no siempre se monta en macOS Sonoma/Sequoia. No es bloqueante porque flasheamos via SWD, no por drag-and-drop.

### 5.3 Connect en STM32CubeProgrammer

Lanzar STM32CubeProgrammer. Configurar el panel ST-LINK:

- Port: SWD
- Frequency: 12000 kHz
- Mode: Under reset (no Normal)
- Reset mode: Hardware reset
- Speed: Reliable

Si dejas Mode: Normal, frecuentemente vas a ver el error Unable to get core ID o No STM32 target found. Esto pasa porque el firmware previo (o el de Sigfox que vamos a flashear) usa modos low-power agresivos que apagan las patas SWD. Under reset resetea el MCU justo antes de la conexion, lo que mantiene SWD activo en la ventana de reset.

Click Connect. Target information esperado:

Acondicionamiento del NUCLEO-WL55JC al backend de Sigfox | Pagina 8 de 27

Board: NUCLEO-WL55JC

Device: STM32WLxx

Device ID: 0x497

Revision ID: Rev Y

NVM size: 256 KB

CPU: Cortex-M4

Target voltage: 3.27 V

Acondicionamiento del NUCLEO-WL55JC al backend de Sigfox | Pagina 9 de 27

## 6. Fase 3: Compilar y flashear Sigfox_AT_Slave_CM4

### 6.1 Backup previo del flash (recomendado)

Si la placa se uso en proyectos anteriores, conviene respaldar el flash completo antes de sobrescribir:

- CubeProgrammer → Memory & File editing
- Address 0x08000000, Size 0x40000, Data width 32-bit
- Click Read → luego Save As con nombre descriptivo, ej. backup_placa_jc2_2026-05-29.hex.

### 6.2 Mass erase

CubeProgrammer → Erasing & Programming → Full chip erase.

### 6.3 Importar el proyecto en CubeIDE

- File → Open Projects from File System
- Directory: /Users/yflores/ST/STM32Cube_FW_WL_V1.5.0/Projects/NUCLEO-WL55JC1/Applications/Sigfox/Sigfox_AT_Slave/STM32CubeIDE/
- Marcar el unico proyecto detectado → Finish.

### 6.4 Region: runtime en V1.5.0 (no compile-time)

Cambio importante respecto a versiones anteriores. En V1.4.0 y anteriores, la region se definia en rfconf.h con un #define REGION_RC2. En V1.5.0 ese archivo no existe. La region se selecciona en runtime via comando AT (AT$RC=2) y se persiste en EEPROM emulada. Ver Capitulo 12, error 12.5.

Por lo tanto: no se edita codigo fuente antes de compilar. Se compila la app tal cual viene.

### 6.5 Build

Click derecho sobre Sigfox_AT_Slave → Clean Project → Build Project. Resultado esperado:

arm-none-eabi-size Sigfox_AT_Slave.elf

text | data | bss | dec | hex filename
75512 | 312 | 10544 | 86368 | 15160 Sigfox_AT_Slave.elf

Build Finished. 0 errors, 0 warnings.

Footprint: 86 KB de 256 KB de flash. Sobra espacio.

### 6.6 Flashear via CubeProgrammer (recomendado)

Si intentas Run As → STM32 C/C++ Application desde CubeIDE 2.0.0, te pedira instalar ST-Link Server aparte. No es necesario. Es mas rapido flashear el .elf generado directamente con CubeProgrammer. Ver Capitulo 12, error 12.2.

Acondicionamiento del NUCLEO-WL55JC al backend de Sigfox | Pagina 10 de 27

Ubicar el .elf:

find /Users/yflores -name "Sigfox_AT_Slave.elf" 2>/dev/null

Esperado: /Users/yflores/ST/STM32Cube_FW_WL_V1.5.0/Projects/NUCLEO-WL55JC1/Applications/Sigfox/Sigfox_AT_Slave/STM32CubeIDE/Debug/Sigfox_AT_Slave.elf

En CubeProgrammer:

- Erasing & Programming
- File path: usar Cmd+Shift+G en el dialogo Browse para pegar la ruta completa
- Marcar: Verify programming, Run after programming
- No marcar Skip flash erase
- Click Start Programming

### 6.7 Verificacion post-flash

Tras el Run, aparecera el mensaje Warning: Connection to device is lost. No es un error. Es porque el firmware Sigfox entra inmediatamente en modo low-power tras boot y suelta SWD. Ver Capitulo 12, error 12.4.

Cerrar CubeProgrammer (Cmd+Q), presionar el boton B4 (NRST) en la placa para reset limpio, abrir

Arduino Serial Monitor:

- Port: /dev/cu.usbmodemNNNN
- Baud: 9600
- Line ending: Carriage return

El firmware debe imprimir su boot banner:

APPLICATION_VERSION: V1.5.0

MW_SIGFOX_VERSION: | V1.8.0
MW_RADIO_VERSION: | V1.4.0

ATtention command interface

SIGFOX APPLICATION READY

Test inicial:

AT

> OK

AT$ID

> FEDCBA98 | (valor TEST por defecto, sin credenciales)

> OK

AT$PAC

> 0000000000000000 | (valor TEST por defecto, sin credenciales)

> OK

Acondicionamiento del NUCLEO-WL55JC al backend de Sigfox | Pagina 11 de 27

Sintaxis AT en V1.5.0: usa el comando sin signo de pregunta (AT$ID, no AT$ID?). El ? en V1.5.0 invoca el texto de ayuda en lugar del valor. Ver Capitulo 12, error 12.5.

Acondicionamiento del NUCLEO-WL55JC al backend de Sigfox | Pagina 12 de 27

## 7. Fase 4: Extraer el chip certificate

### 7.1 Concepto

Cada STM32WL trae de fabrica un chip certificate de 136 bytes grabado en zona protegida (0x1FFF3F04 en la system memory) durante el wafer probe. Es unico por chip y solo ST puede validarlo criptograficamente.

### 7.2 Extraccion paso a paso

1. Cerrar Arduino Serial Monitor (libera VCP/ST-LINK).
2. Abrir CubeProgrammer → Mode Under reset → Connect.
3. En la barra lateral, click en el icono Sigfox Credentials (solo presente en CubeProgrammer ≥ 2.6).
4. Pestana Read → click boton Read.
5. Aparecen los 136 bytes en hex. Log esperado:

Size: 136 Bytes

Address: 0x1FFF3F04

Read progress:

Data read successfully

Time elapsed during the read operation is: 00:00:00.001

6. Click | Save | chip | certificate | → | guardar | como | chip_cert_<descripcion>.bin | (ej.

chip_cert_jc2_yflores_2026-05-29.bin).

7. Click Copy chip certificate → queda en clipboard para pegarlo en el portal.

El chip certificate es unico e irrepetible. Si pierdes el .bin, tendras que volver a extraerlo cada vez. Etiqueta fisicamente la placa con el ID Sigfox una vez emitido para mantener trazabilidad chip-credenciales.

Acondicionamiento del NUCLEO-WL55JC al backend de Sigfox | Pagina 13 de 27

## 8. Fase 5: Portal sfxp y descarga de credenciales

### 8.1 Login y submission

URL: https://my.st.com/sfxp

1. Login con cuenta myST.
2. La pagina pide pegar el chip certificate. Hay dos opciones:
- Pegar texto hex en el textarea (Cmd+V de lo copiado en CubeProgrammer).
- Subir el archivo .bin.
3. Click el boton Sigfox™ credentials.
4. Si la validacion criptografica tiene exito, se descarga automaticamente sigfox_credentials.zip.

### 8.2 Contenido del ZIP

unzip -l sigfox_credentials.zip

Archive: | sigfox_credentials.zip
Length | Date | Time | Name
48 | 05-29-2026 16:25 | sigfox_data_033E07FC.bin
1607 | 05-29-2026 16:25 | sigfox_data_033E07FC.h
- sigfox_data_<ID>.bin — 48 bytes binarios. Es lo que escribiremos al flash en Fase 6.
- sigfox_data_<ID>.h — header C alternativo (no se usa en el flujo Binary-Raw).
- El sufijo del nombre es el Device ID Sigfox. En este caso: 033E07FC.

### 8.3 Errores conocidos del portal

Si el ZIP sale de 0 bytes, hay Service unavailable, o no inicia la descarga, ver Capitulo 12 errores 12.6 y 12.7.

Acondicionamiento del NUCLEO-WL55JC al backend de Sigfox | Pagina 14 de 27

## 9. Fase 6: Escribir sigfox_data.bin en 0x0803E500

### 9.1 Por que esa direccion

En | el | linker | script | STM32WL55JCIX_FLASH.ld | del | proyecto | Sigfox_AT_Slave, | la | variable
USER_Key_region_ROM esta ubicada en 0x0803E500. | Es una zona reservada al final de la flash
que no es tocada por el firmware al programar el .elf. El binario sigfox_data.bin debe escribirse exactamente alli.

### 9.2 Estructura del sigfox_data.bin (48 bytes)

Inspeccionable con xxd:

xxd sigfox_data_033E07FC.bin

00000000: fc07 3e03 b06e a49c 9e0f 11f4 0100 0000 | ..>..n |
00000010: 51ad 0eba 0e92 e90b 7fa6 78f1 bf23 3e5d | Q.........x..#>]
00000020: 4d5f 3030 3438 5f41 4237 375f 3031 3fd5 | M_0048_AB77_01?.

Descomposicion:

Offset | Tamano | Contenido
0x00 – 0x03 | 4 bytes | Device ID en little-endian (FC 07 3E 03 = 033E07FC)
0x04 – 0x0B | 8 bytes | PAC (B0 6E A4 9C 9E 0F 11 F4)
0x0C – 0x0F | 4 bytes | Flags / version (01 00 00 00)
0x10 – 0x1F | 16 bytes | KEY AES-128 cifrada (no plaintext)
0x20 – 0x2D | 14 bytes | ASCII identificador interno del chip (M_0048_AB77_01)
0x2E – 0x2F | 2 bytes | Checksum / CRC

Table 2. Estructura del binario sigfox_data en V1.5.0.

### 9.3 Procedimiento

1. CubeProgrammer → Mode Under reset → Connect.
2. Click icono Sigfox Credentials en barra lateral.
3. Seccion inferior SigFox credential provisioning:
- Configuration: Binary-Raw
- Address: 0x0803E500 (autocompletado)
- Binary file: click Browse, usar Cmd+Shift+G para pegar ruta a sigfox_data_033E07FC.bin
- Header file: dejar vacio
4. Click Write data.
5. Resultado esperado: pop-up SigFox credential provisioning succeeded.
Acondicionamiento del NUCLEO-WL55JC al backend de Sigfox | Pagina 15 de 27

### 9.4 Verificacion

1. Disconnect en CubeProgrammer → Cmd+Q.
2. Reset fisico con B4.
3. Abrir Arduino Serial Monitor (9600, CR).
4. Probar:

AT

> OK

AT$ID

> 033E07FC (ahora si el ID real, no FEDCBA98)

> OK

AT$PAC

> B06EA49C9E0F11F4 (PAC real, no ceros)

> OK

Si ambos valores coinciden con el contenido del .h, las credenciales estan correctamente cargadas y descifradas por el firmware.

Acondicionamiento del NUCLEO-WL55JC al backend de Sigfox | Pagina 16 de 27

## 10. Fase 7: Validar y registrar en backend Sigfox

### 10.1 Acceso al backend

URL: https://backend.sigfox.com/auth/login

Login con cuenta admin de 0G IoT Solutions.

### 10.2 Caso especial: device pre-existente

En esta sesion, el device 033E07FC ya estaba registrado previamente por un colega (Jose Francisco Diaz Figueroa, 2025-10-22). Esto es frecuente con placas de laboratorio reutilizadas.

Al consultar el device en el backend se observo:

Campo | Valor observado
Identifier (hex) | 33E07FC (cero a la izquierda omitido por display)
Name | WL55_A449 (nombre del registro anterior)
PAC mostrado | BC07485F3FFF8B71 (rotado, no coincide con el .h)
Device Type | Nucleo_WL
Group | DHW
Contract | UnaTag_test
Token validity | 9 free messages left (1 sent previamente)
Last seen | 2025-10-22 18:04:30
State | OK

Table 3. Estado del device al inicio de Fase 7.

### 10.3 Por que el PAC del backend difiere del PAC del .h

El PAC del .h (B06EA49C9E0F11F4) es el PAC inicial emitido por ST. Al usarlo para registrar el device por primera vez en el backend, el PAC se consume y rota a un nuevo valor (BC07485F3FFF8B71 en este caso). Este nuevo PAC es el que se usaria para transferir el device a otra cuenta o grupo en el futuro. No es un error, es comportamiento de seguridad estandar de Sigfox.

Lo que si importa para que el device transmita correctamente es la KEY AES-128, que no cambia y esta correctamente cargada en el MCU.

### 10.4 Si fuera un device nuevo (registro desde cero)

Para devices que aun no estan en el backend, los pasos serian:

1. Menu Group → usar el grupo existente o crear uno nuevo.
2. Menu Device Type → New:
- Name: NUCLEO-WL55JC-RC2-DevTest
- Group: el seleccionado arriba
Acondicionamiento del NUCLEO-WL55JC al backend de Sigfox | Pagina 17 de 27

- Keep alive period: 0 (sin alerta) o 1440 min (1/dia)
- Payload display: Regular (raw)
- Downlink mode: Direct (permite 8 bytes de respuesta)
- Callbacks: vacio al inicio
3. Menu Device → New:
- Device ID: 033E07FC
- PAC: B06EA49C9E0F11F4 (se consumira)
- Name: descriptivo (ej. Nucleo-WL55JC-001-Yflores)
- Device Type: el creado arriba
- Prototype: dejar sin marcar para produccion real
Acondicionamiento del NUCLEO-WL55JC al backend de Sigfox | Pagina 18 de 27

## 11. Fase 8: Primer uplink y verificacion end-to-end

### 11.1 Configurar region y potencia por AT

AT$RC=2

> OK

Configura la region a RC2 (Mexico/USA/Canada). Se persiste en EEPROM emulada y sobrevive resets.

Para fijar potencia TX en 22 dBm (maximo permitido por FCC en RC2):

ATS302=22

> OK

La sintaxis de set-power en V1.5.0 puede variar; si ATS302 no responde OK, dejar la potencia default. El firmware Sigfox por defecto usa el maximo permitido por la region configurada.

### 11.2 Enviar primer mensaje

Payload elegido: “Hello” = 48 65 6C 6C 6F en hex (5 bytes, dentro del limite de 12 bytes uplink).

AT$SF=48656C6C6F

> OK (despues de ~6 segundos)

Lo que pasa internamente: la placa transmite 3 replicas (TX1, TX2, TX3) en frecuencias de hopping

distintas, cada una de aproximadamente 225 ms. El OK llega tras finalizar todas las transmisiones.

### 11.3 Verificar en backend

1. Navegar a backend.sigfox.com → Device → 33E07FC → Messages.
2. Refrescar (F5). El mensaje deberia aparecer en 2–30 segundos.

Resultado obtenido en esta sesion:

Atributo | Valor
Time | 2026-05-29 11:41:05
Delay | 3.2 s
Seq Num | 0
Data/Decoding | 48656c6c6f
Base Station | 6BCE
RSSI | -127.00 dBm
Frequency | 902.1782 MHz
Frames | 1 (de 3 transmitidas)
LQI | AVERAGE (3/5)
Location | gateway geolocalizado

Table 4. Mensaje recibido en backend Sigfox.

Acondicionamiento del NUCLEO-WL55JC al backend de Sigfox | Pagina 19 de 27

### 11.4 Troubleshooting si no llega el mensaje

Causa probable | Accion
Antena suelta o mal atornillada | Apretar firmemente en CN12
Region mal configurada | AT$RC debe responder 2
Potencia baja | verificar ATS302 ≥ 20
Sin cobertura RF | confirmar con 0G IoT Solutions el gateway mas cercano
ID/PAC del backend ̸= chip | comparar AT$ID con backend
Token consumido | ver Token validity en Info del backend
Antena inadecuada para la banda | verificar que sea antena SMA de 868/915 MHz

Table 5. Tabla de diagnostico si el uplink no llega.

Acondicionamiento del NUCLEO-WL55JC al backend de Sigfox | Pagina 20 de 27

## 12. Errores encontrados durante el comisionamiento y soluciones

Esta seccion documenta los problemas reales encontrados en la sesion del 29 de mayo de 2026, en orden cronologico. Sirve como referencia para evitar repetir los mismos pasos en falso en futuras placas.

### 12.1 Error 12.1 — GitHub no incluye la app Sigfox

Sintoma:

git clone --recursive https://github.com/STMicroelectronics/STM32CubeWL.git

cd STM32CubeWL
ls Projects/NUCLEO-WL55JC/Applications/
FatFs | FreeRTOS | LICENSE.md | LoRaWAN | SubGHz_Phy

No aparece la carpeta Sigfox.

Causa: el stack de Sigfox es propietario de UnaBiz y ST no lo incluye en el repositorio publico de GitHub por restricciones de licencia. Solo se distribuye via el ZIP oficial de st.com despues de aceptar los terminos Sigfox.

Solucion: descargar el ZIP de https://www.st.com/en/embedded-software/stm32cubewl.html, aceptar la licencia, y descomprimir. Verificar:

find ~/ST -type d -name "Sigfox_AT_Slave"

### 12.2 Error 12.2 — CubeIDE 2.0.0 pide ST-Link Server

Sintoma: al hacer Run As → STM32 C/C++ Application aparece:

ST-LINK firmware verification

ST-Link Server is required to launch the debug session.

Please download it on www.st.com

Causa: CubeIDE 2.0.0 introdujo dependencia con ST-Link Server como componente separado para sesiones de debug.

Solucion: en lugar de instalar ST-Link Server, flashear el .elf directamente desde CubeProgrammer (que ya esta instalado y funciona). El Erasing & Programming acepta archivos .elf nativamente.

### 12.3 Error 12.3 — Unable to get core ID

Sintoma:

Error: Unable to get core ID

Error: No STM32 target found! If your product embeds Debug Authentication,

please perform a discovery using Debug Authentication \end{lstlisting>

\textbf{Causa:} el mensaje sobre Debug Authentication es \emph{falso positivo}

(STM32WL55JC no tiene TrustZone). La causa real es que el firmware previo

o el de Sigfox usa modos low-power agresivos que sueltan las patas SWD.

Acondicionamiento del NUCLEO-WL55JC al backend de Sigfox | Pagina 21 de 27

\textbf{Solucion:} cambiar \emph{Mode} de \texttt{Normal} a \textbf{Under

reset} y \emph{Reset mode} de Software a \textbf{Hardware reset}, luego

Connect.

Si aun falla, mantener presionado el boton B4 (NRST) mientras se hace

Connect, soltarlo cuando empiece a buscar.

\subsection{Error 12.4 --- \texttt{Connection to device is lost} despues de Run}

\textbf{Sintoma:} tras un flasheo exitoso con \emph{Run after programming}:

\begin{lstlisting}

Download verified successfully

RUNNING Program ... Address: 0x08000000

Application is running, Please Hold on...

Start operation achieved successfully

Error: Unable to get core ID

Warning: Connection to device is lost

Disconnected from device.
\end{lstlisting>

\textbf{Causa:} \emph{esto no es un error.} El firmware Sigfox apenas

arranca entra en modo low-power (DeepSleep/STOP) entre transmisiones para

ahorrar bateria, y al hacerlo apaga las patas SWD. CubeProgrammer pierde

el debugger porque ya no hay con quien hablar via SWD.

\textbf{Solucion:} ignorar el warning. El firmware esta corriendo

correctamente. Para hablar con el ya hay que usar el VCP serial, no SWD.

\subsection{Error 12.5 --- Sintaxis AT cambio en V1.5.0}

\textbf{Sintoma:}

\begin{lstlisting}

AT$ID?

> AT$ID: Get the ID (texto de ayuda, no el valor)

> OK

Causa: en V1.5.0, el ? al final de un comando AT invoca el help text en lugar de devolver el valor. En

versiones anteriores, AT$ID? devolvia el valor.

Solucion: usar el comando sin signo de pregunta:

AT$ID

> 033E07FC

> OK

Otros cambios de sintaxis observados:

- AT$RC (sin parametro) puede no devolver valor; usar AT$RC=2 para fijar y verificar via comportamiento.
- ATI puede no existir; el firmware imprime version solo en boot banner.
Acondicionamiento del NUCLEO-WL55JC al backend de Sigfox | Pagina 22 de 27

### 12.4 Error 12.6 — Region runtime, no compile-time

Sintoma: buscar rfconf.h con Cmd+Shift+R en CubeIDE no encuentra el archivo.

Causa: en V1.5.0, ST eliminó el archivo rfconf.h con defines tipo REGION_RC2. La region se selecciona en runtime mediante el comando AT$RC=N y se persiste en EEPROM emulada (en flash, leida al boot via

E2P_Read_ConfigWords).

Confirmacion en el codigo: en sgfx_app.c de Sigfox_AT_Slave, la funcion st_sigfox_open() recibe sfx_rc_enum_t sfx_rc como parametro y hace switch sobre los casos SFX_RC1, SFX_RC2, SFX_RC3A, etc.

Solucion: no editar codigo fuente antes de compilar. Compilar tal cual y configurar region post-flash via AT.

### 12.5 Error 12.7 — Confusion entre proyectos del workspace

Sintoma: al hacer File Search por RC2 aparecen matches en dos proyectos:

- LSM1x0A_SDK_LoRaWAN_Sigfox: 5 matches en sgfx_app.c
- Sigfox_AT_Slave: 3 matches en sgfx_app.c

Causa: el workspace puede tener proyectos heredados de otras sesiones (LSM1x0A es para un modulo Murata distinto al NUCLEO).

Solucion: cerrar el proyecto irrelevante con Close Project y trabajar solo sobre Sigfox_AT_Slave. Verificar que el Build se hace sobre el proyecto correcto (click derecho sobre Sigfox_AT_Slave → Build, no Cmd+B con otro seleccionado).

### 12.6 Error 12.8 — PAC del backend distinto al PAC del .h

Sintoma: el backend muestra un PAC (BC07485F3FFF8B71) que no coincide con el PAC del header

(B06EA49C9E0F11F4).

Causa: el PAC del header es el PAC inicial emitido por ST. Al usarlo para registrar el device por primera vez, se consume y rota a un PAC nuevo (usado para futuras transferencias). Este es comportamiento de

seguridad estandar de Sigfox.

Solucion: no preocuparse. La KEY AES-128 (que es lo que autentica los uplinks) no cambia. El device

transmite correctamente.

### 12.7 Error 12.9 — ZIP de 0 bytes del portal sfxp

Sintoma: la descarga del portal genera un ZIP vacio o no inicia.

Causa: el portal my.st.com/sfxp tiene historial de inestabilidad documentada en ST Community desde 2023.

Soluciones por orden:

1. Borrar cache del browser y reintentar.
2. Usar otro navegador (Chrome ↔ Firefox).
Acondicionamiento del NUCLEO-WL55JC al backend de Sigfox | Pagina 23 de 27

3. Reintentar en horarios distintos.
4. Confirmar que el certificate copiado son los 136 bytes completos, no un truncado.
5. Abrir ticket en ST Community categoria STM32 MCUs Wireless.
6. Para volumen >10 placas: solicitar Sigfox Credential Request Agreement (CRA) a UnaBiz / 0G IoT

Solutions.

### 12.8 Error 12.10 — Mass storage NODE_WL55JC no monta en macOS

Sintoma: al conectar la placa por USB, el ls /Volumes/ no muestra NODE_WL55JC (la unidad drag-and-drop).

Causa: macOS Sonoma/Sequoia tiene problemas conocidos con el mass storage virtual del ST-LINK V3 en

cierta combinacion de firmware ST-LINK + version macOS.

Solucion: no es bloqueante. Como flasheamos por SWD via CubeProgrammer, el mass storage es prescindible. Verificar que al menos el VCP (/dev/cu.usbmodemNNNN) y el ST-LINK debug interface (visible en ioreg) sí estan presentes.

### 12.9 Tabla resumen de errores

# | Sintoma | Solucion express

12.1 GitHub no trae Sigfox | Descargar ZIP de st.com (no clone)
12.2 CubeIDE pide ST-Link Server | Flashear .elf con CubeProgrammer
12.3 Unable to get core ID | Mode: Under reset + Hardware reset
12.4 Connection lost tras Run | Es esperado, firmware low-power
12.5 AT con ? muestra help | Usar AT sin signo de pregunta
12.6 rfconf.h no existe | Region es runtime en V1.5.0
12.7 Workspace confuso | Cerrar proyectos irrelevantes
12.8 PAC backend ̸= PAC .h | Normal, PAC rota tras registro
12.9 ZIP 0 bytes del portal sfxp | Cache, browser distinto, reintentar
12.10 Mass storage no monta | No bloqueante, flasheamos por SWD

Table 6. Errores reales encontrados durante el comisionamiento.

Acondicionamiento del NUCLEO-WL55JC al backend de Sigfox | Pagina 24 de 27

## 13. Anexos tecnicos

### 13.1 Direcciones de memoria criticas

Direccion | Tamano | Region | Contenido
0x08000000 | 256 KB | Flash (todo) | Firmware Sigfox_AT_Slave_CM4
0x0803E500 | 2 KB | USER_Key_region_ROM | sigfox_data.bin (credenciales)
0x1FFF3F04 | 136 B | System memory | Chip certificate (grabado en wafer probe)
0x20000000 | 64 KB | SRAM | RAM de trabajo

Table 7. Memory map relevante en STM32WL55JCI.

### 13.2 Comandos AT compatibles V1.5.0

Comando | Funcion
AT | Test de comunicacion (responde OK)
AT$ID | Lee Device ID (4 bytes hex)
AT$PAC | Lee PAC (8 bytes hex)
AT$RC=N | Configura region (N=1..7), persiste en EEPROM
AT$SF=<hex> | Envia frame uplink (hasta 12 bytes payload)
AT$SF=<hex>,1 | Envia frame con downlink request (consume 2 tokens)
AT$SB=<bit> | Envia 1 bit (super eficiente para alarmas)
ATS302=N | Configura potencia TX en dBm (max 22 para RC2 FCC)
AT$RST | Reset del MCU

Table 8. Comandos AT principales del firmware Sigfox_AT_Slave V1.5.0.

### 13.3 Parametros RF de Sigfox RC2 Mexico

Parametro | Valor
Frecuencia uplink central | 902.2 MHz (frequency hopping FCC)
Frecuencia downlink central | 905.2 MHz
Bandwidth total | 192 kHz
Bandwidth por canal | 600 Hz
Bit rate uplink | 600 bps (D-BPSK)
Bit rate downlink | 600 bps (GFSK)
Payload max uplink | 12 bytes
Payload max downlink | 8 bytes
Potencia maxima | +22 dBm (limitada por FCC)
Mensajes/dia uplink | 140 (limite regulatorio FCC)
Mensajes/dia downlink | 4 (limite Sigfox)
Listen Before Talk | No requerido (FCC, no ETSI)

Table 9. Parametros RF normativos de RC2 Mexico.

Acondicionamiento del NUCLEO-WL55JC al backend de Sigfox | Pagina 25 de 27

## 14. Referencias y documentacion oficial

Documento | URL
NUCLEO-WL55JC | https://www.st.com/en/evaluation-tools/nucleo-wl55jc.html
UM2592 (HW MB1389) | https://www.st.com/resource/en/user_manual/
| um2592-stm32wl-nucleo64-board-mb1389-stmicroelectronics.pdf (https://www.st.com/resource/en/user_manual/um2592-stm32wl-nucleo64-board-mb1389-stmicroelectronics.pdf)
AN5480 (Sigfox + CubeWL) | https://www.st.com/resource/en/application_note/
| an5480-how-to-build-a-sigfox-application-with-stm32cubewl-stmicroelectronics.
| pdf (https://www.st.com/resource/en/application_note/an5480-how-to-build-a-sigfox-application-with-stm32cubewl-stmicroelectronics.pdf)
STM32CubeWL en st.com | https://www.st.com/en/embedded-software/stm32cubewl.html
GitHub STM32CubeWL (sin Sigfox) | https://github.com/STMicroelectronics/STM32CubeWL
Portal sfxp (credenciales) | https://my.st.com/sfxp
Backend Sigfox | https://backend.sigfox.com/
Sigfox API docs | https://support.sigfox.com/apidocs
Sigfox build (RC config) | https://build.sigfox.com/sigfox-radio-configurations-rc
Cobertura Sigfox | https://coverage.sigfox.com
Blog ST — Sigfox credentials | https://blog.st.com/stm32cubeprogrammer-sigfox/
ST Community Wireless | https://community.st.com/t5/stm32-mcus-wireless/bd-p/
| stm32-mcus-wireless-forum (https://community.st.com/t5/stm32-mcus-wireless/bd-p/stm32-mcus-wireless-forum)
0G IoT Solutions | https://0giotsolutions.com/

Table 10. URLs de referencia oficial.

Acondicionamiento del NUCLEO-WL55JC al backend de Sigfox | Pagina 26 de 27

## 15. Resumen ejecutivo del flujo

1. Instalar: STM32CubeIDE 2.0.0 + STM32CubeProgrammer ≥ 2.6 + STM32CubeWL V1.5.0 desde

st.com.

2. Conectar: placa via CN1 USB. Verificar VCP y debugger enumerados. Connect en CubeProgrammer con Mode: Under reset.
3. Flashear Sigfox_AT_Slave_CM4.elf con CubeProgrammer. Validar boot banner V1.5.0 + V1.8.0 + V1.4.0 via Serial Monitor.
4. Extraer chip cert (136 bytes) desde CubeProgrammer → Sigfox Credentials → Read. Guardar como

chip_cert.bin.

5. Subir a my.st.com/sfxp y descargar sigfox_credentials.zip con sigfox_data_<ID>.bin.
6. Escribir sigfox_data_<ID>.bin en 0x0803E500 via CubeProgrammer → Sigfox Credentials →

Write data.

7. Validar con AT$ID y AT$PAC (sintaxis sin ?). Confirmar registro en backend Sigfox.
8. Enviar AT$RC=2 → AT$SF=48656C6C6F. Verificar mensaje en backend → Device → Messages en 2–30

s.

Documento generado el 29 de mayo de 2026 Acondicionamiento del NUCLEO-WL55JC al backend de Sigfox — v1.0 Yahir Flores — Ingeniero de Hardware — 0G IoT Solutions

https: // 0giotsolutions. com/ (https://0giotsolutions.com/)

Acondicionamiento del NUCLEO-WL55JC al backend de Sigfox | Pagina 27 de 27

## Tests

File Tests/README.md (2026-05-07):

# Tests

Pruebas funcionales, de validación e integración del dispositivo 0G LockControl.

## Subcarpetas

### Lab/
Pruebas de laboratorio:
- Simulaciones de apertura de puerta (reed switch)
- Verificación de transmisión de mensajes Sigfox
- Análisis de señal RF (potencia, frecuencia, espectro)
- Medición de consumo energético (modo activo vs. sleep/stop)
- Validación de anti-rebote (debounce)
- Pruebas de rango con atenuador

### Field/
Pruebas de campo en instalaciones reales:
- Latencia extremo a extremo (apertura → notificación en app)
- Confiabilidad de transmisión en distintas condiciones
- Autonomía energética (duración de batería)
- Comportamiento en ambientes con interferencia RF
- Validación del montaje físico (carcasa + imán)

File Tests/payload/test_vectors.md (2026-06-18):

# Vectores de prueba — Payload Sigfox 12 bytes

Vectores compartidos entre el codec C (`Firmware/app/payload/payload_codec.c`) y el
parser Python (`App/Backend/payload_parser.py`). **El hex esperado debe coincidir
byte a byte entre ambas implementaciones.**

## Contrato de bytes (recordatorio)

| Byte | Campo | Notas |
|---|---|---|
| 0 | `tipo` | `0x01` alarma · `0x02` heartbeat |
| 1 | `fuente` | bitfield: bit0 `0x01` accel · bit1 `0x02` magnético |
| 2–3 | `magnitud_mg` | uint16 **BIG-ENDIAN** |
| 4 | `eje` | 0 ninguno · 1 X · 2 Y · 3 Z |
| 5 | `magnetico` | 0 cerrado · 1 abierto |
| 6 | `bateria_pct` | 0..100 |
| 7 | `temp` | `temp_c + 40` (offset para negativos) |
| 8–9 | `conteo_eventos` | uint16 **BIG-ENDIAN** |
| 10–11 | reservado | siempre `0x0000` |

---

## V1 — Alarma por acelerómetro

200 mg, eje Z, batería 90 %, 25 °C, 15 eventos.

| Campo | Valor | Byte(s) | Hex |
|---|---|---|-----|
| tipo | alarma | 0 | `01` |
| fuente | accel (`0x01`) | 1 | `01` |
| magnitud_mg | 200 (`0x00C8`) | 2–3 | `00 C8` |
| eje | Z (3) | 4 | `03` |
| magnetico | cerrado (0) | 5 | `00` |
| bateria_pct | 90 | 6 | `5A` |
| temp | 25 °C → 65 | 7 | `41` |
| conteo_eventos | 15 (`0x000F`) | 8–9 | `00 0F` |
| reservado | 0 | 10–11 | `00 00` |

**Hex esperado:** `010100C803005A41000F0000`

---

## V2 — Alarma por magnético (puerta abierta)

Sin magnitud de accel, puerta abierta, batería 88 %, 22 °C, 16 eventos.

| Campo | Valor | Byte(s) | Hex |
|---|---|---|-----|
| tipo | alarma | 0 | `01` |
| fuente | magnético (`0x02`) | 1 | `02` |
| magnitud_mg | 0 | 2–3 | `00 00` |
| eje | ninguno (0) | 4 | `00` |
| magnetico | abierto (1) | 5 | `01` |
| bateria_pct | 88 | 6 | `58` |
| temp | 22 °C → 62 | 7 | `3E` |
| conteo_eventos | 16 (`0x0010`) | 8–9 | `00 10` |
| reservado | 0 | 10–11 | `00 00` |

**Hex esperado:** `010200000001583E00100000`

---

## V3 — Alarma dual (ambas fuentes)

350 mg eje X **y** puerta abierta, batería 85 %, 30 °C, 17 eventos.

| Campo | Valor | Byte(s) | Hex |
|---|---|---|-----|
| tipo | alarma | 0 | `01` |
| fuente | accel \| magnético (`0x03`) | 1 | `03` |
| magnitud_mg | 350 (`0x015E`) | 2–3 | `01 5E` |
| eje | X (1) | 4 | `01` |
| magnetico | abierto (1) | 5 | `01` |
| bateria_pct | 85 | 6 | `55` |
| temp | 30 °C → 70 | 7 | `46` |
| conteo_eventos | 17 (`0x0011`) | 8–9 | `00 11` |
| reservado | 0 | 10–11 | `00 00` |

**Hex esperado:** `0103015E0101554600110000`

---

## V4 — Heartbeat (cuarto frío)

Keepalive de 24 h: batería 75 %, 4 °C, 0 eventos.

| Campo | Valor | Byte(s) | Hex |
|---|---|---|-----|
| tipo | heartbeat | 0 | `02` |
| fuente | ninguna (0) | 1 | `00` |
| magnitud_mg | 0 | 2–3 | `00 00` |
| eje | ninguno (0) | 4 | `00` |
| magnetico | cerrado (0) | 5 | `00` |
| bateria_pct | 75 | 6 | `4B` |
| temp | 4 °C → 44 | 7 | `2C` |
| conteo_eventos | 0 | 8–9 | `00 00` |
| reservado | 0 | 10–11 | `00 00` |

**Hex esperado:** `0200000000004B2C00000000`

---

## V5 — Edge case: temperatura negativa

Heartbeat en frío extremo: batería 60 %, **−10 °C**, 0 eventos.
Verifica el offset: `−10 + 40 = 30 = 0x1E`.

| Campo | Valor | Byte(s) | Hex |
|---|---|---|-----|
| tipo | heartbeat | 0 | `02` |
| fuente | ninguna (0) | 1 | `00` |
| magnitud_mg | 0 | 2–3 | `00 00` |
| eje | ninguno (0) | 4 | `00` |
| magnetico | cerrado (0) | 5 | `00` |
| bateria_pct | 60 | 6 | `3C` |
| temp | −10 °C → **30** | 7 | `1E` |
| conteo_eventos | 0 | 8–9 | `00 00` |
| reservado | 0 | 10–11 | `00 00` |

**Hex esperado:** `0200000000003C1E00000000`

---

## Resumen (para diff rápido C ↔ Python)

| # | Vector | Hex esperado (12 bytes) |
|---|---|---|
| V1 | Alarma accel | `010100C803005A41000F0000` |
| V2 | Alarma magnético | `010200000001583E00100000` |
| V3 | Alarma dual | `0103015E0101554600110000` |
| V4 | Heartbeat | `0200000000004B2C00000000` |
| V5 | Temp negativa | `0200000000003C1E00000000` |

> Validación Python: `py App/Backend/payload_parser.py` imprime los 5 decodificados.
> Validación C: ver `Tests/payload/test_payload_host.c`.

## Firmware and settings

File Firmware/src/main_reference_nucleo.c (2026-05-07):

/**
  ******************************************************************************
  * @file           : main_reference_nucleo.c
  * @brief          : Código de referencia validado con NUCLEO-WL55JC2
  * @description    : Este archivo contiene el código base probado en la placa
  *                   NUCLEO para detección de flanco con reed switch y envío
  *                   de mensaje Sigfox. Sirve como referencia para la
  *                   implementación en el LSM110A.
  *
  * @attention       : NO es el código final. Es referencia del código validado
  *                   en el canal #stm32wl de Slack (Oct-Ene 2025-2026).
  ******************************************************************************
  *
  * FUNCIONALIDAD VALIDADA:
  * - Detección de flanco de subida en PB1 (reed switch)
  * - Envío de payload Sigfox ("Franco" = 0x46,0x72,0x61,0x6E,0x63,0x6F)
  * - Control de LEDs como indicadores de estado
  * - Anti-rebote por HAL_Delay (50ms en loop principal)
  * - Contador de aperturas
  *
  * CREDENCIALES SIGFOX (NUCLEO):
  * - SIGFOX_KEY:  51,AD,0E,BA,0E,92,E9,0B,7F,A6,78,F1,BF,23,3E,5D
  * - SIGFOX_ID:   03,3E,07,FC
  * - SIGFOX_PAC:  B0,6E,A4,9C,9E,0F,11,F4
  * - Backend ID:  54396924
  *
  ******************************************************************************
  */

/* Includes ------------------------------------------------------------------*/
#include "main.h"
#include "app_sigfox.h"
#include "gpio.h"

/* Private variables ---------------------------------------------------------*/

/* Private function prototypes -----------------------------------------------*/
void SystemClock_Config(void);

/* ---- Función para enviar mensaje Sigfox ---- */
void EnviarMensajeFranco(void)
{
  // "Franco" en hexadecimal: 46 72 61 6E 63 6F
  uint8_t payload[] = {0x46, 0x72, 0x61, 0x6E, 0x63, 0x6F};
  uint8_t dl_msg[8] = {0x00, 0x00, 0x00, 0x00, 0x00, 0x00, 0x00, 0x00};
  uint32_t nbTxRepeatFlag = 1;  // 3 repeticiones

  // Enviar el mensaje
  SIGFOX_API_send_frame(payload, sizeof(payload), dl_msg, nbTxRepeatFlag, SFX_FALSE);

  printf("Mensaje 'Franco' enviado por Sigfox!\r\n");
}

/* ---- Función para manejar el flanco de PB_1 (Reed Switch) ---- */
void GestionarFlancoPB1(void)
{
  static uint8_t estado_anterior = 0;
  uint8_t estado_actual = HAL_GPIO_ReadPin(GPIOB, GPIO_PIN_1);
  static uint32_t contador = 0;

  // Detectar flanco de subida (LOW -> HIGH)
  if (estado_anterior == GPIO_PIN_RESET && estado_actual == GPIO_PIN_SET)
  {
    contador++;
    printf("Flanco detectado en PB1! Contador: %lu\r\n", contador);

    // Encender LEDs (indicador visual)
    BSP_LED_On(LED_RED);
    HAL_GPIO_WritePin(GPIOB, GPIO_PIN_3, GPIO_PIN_SET);
    HAL_GPIO_WritePin(GPIOB, GPIO_PIN_5, GPIO_PIN_RESET);

    // Enviar mensaje Sigfox
    EnviarMensajeFranco();

    // Mantener LEDs encendidos por 3 segundos
    HAL_Delay(3000);

    // Apagar LEDs
    BSP_LED_Off(LED_RED);
    HAL_GPIO_WritePin(GPIOB, GPIO_PIN_3, GPIO_PIN_RESET);
    HAL_GPIO_WritePin(GPIOB, GPIO_PIN_5, GPIO_PIN_SET);
  }

  estado_anterior = estado_actual;
}

/* ---- Main ---- */
int main(void)
{
  HAL_Init();
  SystemClock_Config();
  MX_GPIO_Init();

  // Inicialización Sigfox
  MX_Sigfox_Init();

  // Inicializaciones de LEDs y botones
  BSP_LED_Init(LED_BLUE);
  BSP_LED_Init(LED_GREEN);
  BSP_LED_Init(LED_RED);
  BSP_PB_Init(BUTTON_SW1, BUTTON_MODE_GPIO);
  BSP_PB_Init(BUTTON_SW2, BUTTON_MODE_GPIO);
  BSP_PB_Init(BUTTON_SW3, BUTTON_MODE_GPIO);

  // Configuración GPIO para PB3 y PB5 (salidas) y PB1 (entrada reed switch)
  GPIO_InitTypeDef GPIO_InitStruct = {0};
  __HAL_RCC_GPIOB_CLK_ENABLE();

  GPIO_InitStruct.Pin = GPIO_PIN_3;
  GPIO_InitStruct.Mode = GPIO_MODE_OUTPUT_PP;
  GPIO_InitStruct.Pull = GPIO_NOPULL;
  GPIO_InitStruct.Speed = GPIO_SPEED_FREQ_LOW;
  HAL_GPIO_Init(GPIOB, &GPIO_InitStruct);
  HAL_GPIO_WritePin(GPIOB, GPIO_PIN_3, GPIO_PIN_RESET);

  GPIO_InitStruct.Pin = GPIO_PIN_5;
  HAL_GPIO_Init(GPIOB, &GPIO_InitStruct);
  HAL_GPIO_WritePin(GPIOB, GPIO_PIN_5, GPIO_PIN_SET);

  // Entrada PB_1 (reed switch)
  GPIO_InitStruct.Pin = GPIO_PIN_1;
  GPIO_InitStruct.Mode = GPIO_MODE_INPUT;
  GPIO_InitStruct.Pull = GPIO_NOPULL;
  HAL_GPIO_Init(GPIOB, &GPIO_InitStruct);

  printf("Sistema iniciado - Esperando flancos en PB1...\r\n");

  while (1)
  {
    GestionarFlancoPB1();      // Detección de reed switch
    MX_Sigfox_Process();       // Procesar Sigfox
    HAL_Delay(50);             // anti-rebote
  }
}

/**
  * @brief System Clock Configuration (MSI 32 MHz)
  */
void SystemClock_Config(void)
{
  RCC_OscInitTypeDef RCC_OscInitStruct = {0};
  RCC_ClkInitTypeDef RCC_ClkInitStruct = {0};

  HAL_PWR_EnableBkUpAccess();
  __HAL_RCC_LSEDRIVE_CONFIG(RCC_LSEDRIVE_LOW);
  __HAL_PWR_VOLTAGESCALING_CONFIG(PWR_REGULATOR_VOLTAGE_SCALE1);

  RCC_OscInitStruct.OscillatorType = RCC_OSCILLATORTYPE_LSE|RCC_OSCILLATORTYPE_MSI;
  RCC_OscInitStruct.LSEState = RCC_LSE_ON;
  RCC_OscInitStruct.MSIState = RCC_MSI_ON;
  RCC_OscInitStruct.MSICalibrationValue = RCC_MSICALIBRATION_DEFAULT;
  RCC_OscInitStruct.MSIClockRange = RCC_MSIRANGE_10;
  RCC_OscInitStruct.PLL.PLLState = RCC_PLL_NONE;
  if (HAL_RCC_OscConfig(&RCC_OscInitStruct) != HAL_OK)
  {
    Error_Handler();
  }

  RCC_ClkInitStruct.ClockType = RCC_CLOCKTYPE_HCLK3|RCC_CLOCKTYPE_HCLK
                              |RCC_CLOCKTYPE_SYSCLK|RCC_CLOCKTYPE_PCLK1
                              |RCC_CLOCKTYPE_PCLK2;
  RCC_ClkInitStruct.SYSCLKSource = RCC_SYSCLKSOURCE_MSI;
  RCC_ClkInitStruct.AHBCLKDivider = RCC_SYSCLK_DIV1;
  RCC_ClkInitStruct.APB1CLKDivider = RCC_HCLK_DIV1;
  RCC_ClkInitStruct.APB2CLKDivider = RCC_HCLK_DIV1;
  RCC_ClkInitStruct.AHBCLK3Divider = RCC_SYSCLK_DIV1;

  if (HAL_RCC_ClockConfig(&RCC_ClkInitStruct, FLASH_LATENCY_1) != HAL_OK)
  {
    Error_Handler();
  }
}

void Error_Handler(void)
{
  __disable_irq();
  while (1)
  {
  }
}

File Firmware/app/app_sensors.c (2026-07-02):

/**
  ******************************************************************************
  * @file    app_sensors.c
  * @brief   Implementacion de la capa de sensores: eventos -> payload -> TX.
  * @author  Yahir Flores - 0G IoT Solutions
  ******************************************************************************
  */

#include <stdio.h>

#include "app_sensors.h"
#include "bsp_lockcontrol.h"
#include "lis2dw12.h"
#include "reed_switch.h"

#include "sys_app.h"          /* APP_LOG */
#include "adc_if.h"           /* SYS_GetBatteryLevel, SYS_GetTemperatureLevel */
#include "stm32_seq.h"
#include "utilities_def.h"    /* CFG_SEQ_Task_ACCEL_EVENT / CFG_SEQ_Task_REED_EVENT */
#include "st_sigfox_api.h"    /* SIGFOX_API_send_frame */

/* ----------------------------- Estado ----------------------------- */

static lis2dw12_t    s_accel;
static reed_switch_t s_reed;

/* Guard contra IRQs que lleguen entre BSP init y registro de tasks:
   agendar una task no registrada en el sequencer seria comportamiento
   indefinido, asi que las notify_*_isr() ignoran todo hasta init completo. */
static volatile bool s_initialized = false;

static app_sensor_event_t s_last_event;
static bool     s_has_event    = false;
static uint16_t s_event_count  = 0;

static uint32_t s_last_tx_tick = 0;
static bool     s_tx_done_once = false;   /* el primer TX nunca se suprime */

/* ----------------------- Prototipos privados ----------------------- */

static void AccelEventTask(void);
static void ReedEventTask(void);
static void TrySendAlarm(uint8_t fuente);

/* --------------------------- API publica --------------------------- */

void app_sensors_init(void)
{
    uint8_t who = 0;

    /* --- Acelerometro (Y1) --- */
    lis2dw12_init_handle(&s_accel, &hi2c1);

    /* El LIS2DW12 tarda ~20 ms en salir de power-on; reintenta el WHO_AM_I
       para no depender del orden exacto del boot. */
    lis2dw12_status_t st = LIS2DW12_ERR_I2C;
    for (int i = 0; i < 3 && st != LIS2DW12_OK; i++) {
        st = lis2dw12_who_am_i(&s_accel, &who);
        if (st != LIS2DW12_OK) {
            HAL_Delay(20);
        }
    }

    if (st == LIS2DW12_OK) {
        APP_LOG(TS_ON, VLEVEL_L, "Accel OK, WHO_AM_I=0x%02X\r\n", who);

        if (lis2dw12_config_wakeup(&s_accel, APP_SENSORS_WAKEUP_THRESHOLD_MG) == LIS2DW12_OK) {
            APP_LOG(TS_ON, VLEVEL_L, "Accel wake-up cfg: %u mg -> INT1 (PA0)\r\n",
                    (unsigned int)APP_SENSORS_WAKEUP_THRESHOLD_MG);
        } else {
            APP_LOG(TS_ON, VLEVEL_L, "ERROR: accel config_wakeup fallo\r\n");
        }
    } else {
        /* Sin acelerometro el producto sigue operando con el reed:
           degradacion parcial, no bloquear el boot. */
        APP_LOG(TS_ON, VLEVEL_L, "ERROR: accel WHO_AM_I=0x%02X (esperado 0x44), status=%d\r\n",
                who, (int)st);
    }

    /* --- Reed switch --- */
    reed_switch_init(&s_reed, REED_GPIO_PORT, REED_PIN, REED_DEBOUNCE_MS_DEFAULT);
    APP_LOG(TS_ON, VLEVEL_L, "Reed inicial: %s\r\n",
            (reed_switch_read_now(&s_reed) == REED_OPEN) ? "ABIERTO" : "CERRADO");

    /* --- Tasks del sequencer (Y3) --- */
    UTIL_SEQ_RegTask((1U << CFG_SEQ_Task_ACCEL_EVENT), UTIL_SEQ_RFU, AccelEventTask);
    UTIL_SEQ_RegTask((1U << CFG_SEQ_Task_REED_EVENT),  UTIL_SEQ_RFU, ReedEventTask);

    s_initialized = true;

    /* Recupera eventos que hayan llegado durante el boot (flag ya seteado
       por el driver pero task aun no agendada). */
    app_sensors_poll();
}

void app_sensors_poll(void)
{
    if (!s_initialized) {
        return;
    }
    if (lis2dw12_has_pending_event(&s_accel)) {
        UTIL_SEQ_SetTask((1U << CFG_SEQ_Task_ACCEL_EVENT), CFG_SEQ_Prio_0);
    }
    if (reed_switch_has_pending_event(&s_reed)) {
        UTIL_SEQ_SetTask((1U << CFG_SEQ_Task_REED_EVENT), CFG_SEQ_Prio_0);
    }
}

void app_sensors_notify_accel_isr(void)
{
    if (!s_initialized) {
        return;
    }
    lis2dw12_on_interrupt(&s_accel);
    UTIL_SEQ_SetTask((1U << CFG_SEQ_Task_ACCEL_EVENT), CFG_SEQ_Prio_0);
}

void app_sensors_notify_reed_isr(void)
{
    if (!s_initialized) {
        return;
    }
    reed_switch_on_interrupt(&s_reed);
    /* on_interrupt aplica debounce: solo agenda si el evento sobrevivio */
    if (reed_switch_has_pending_event(&s_reed)) {
        UTIL_SEQ_SetTask((1U << CFG_SEQ_Task_REED_EVENT), CFG_SEQ_Prio_0);
    }
}

bool app_sensors_get_last_event(app_sensor_event_t *out)
{
    /* s_last_event solo se escribe en contexto de task (sequencer), nunca
       en ISR, asi que leerlo desde otra task no requiere critical section. */
    if (out == NULL || !s_has_event) {
        return false;
    }
    *out = s_last_event;
    return true;
}

uint16_t app_sensors_get_event_count(void)
{
    return s_event_count;
}

uint8_t app_sensors_read_reed_now(void)
{
    return (reed_switch_read_now(&s_reed) == REED_OPEN)
           ? PAYLOAD_MAG_ABIERTO : PAYLOAD_MAG_CERRADO;
}

uint8_t app_sensors_battery_pct(void)
{
    uint16_t mv = SYS_GetBatteryLevel();   /* mV */

    /* CR2450: 3.0 V fresca, 2.0 V fin de vida. La curva real es plana y cae
       al final; la aproximacion lineal basta para el MVP. */
    if (mv >= 3000U) {
        return 100U;
    }
    if (mv <= 2000U) {
        return 0U;
    }
    return (uint8_t)((mv - 2000U) / 10U);
}

int8_t app_sensors_temp_c(void)
{
    /* SYS_GetTemperatureLevel devuelve Q8.8: >>8 = grados C enteros */
    int16_t t = (int16_t)(SYS_GetTemperatureLevel() >> 8);

    /* Rango representable del byte 7 del payload (offset +40) */
    if (t > 87)  { t = 87;  }
    if (t < -40) { t = -40; }
    return (int8_t)t;
}

/* ------------------------ Tasks del sequencer ------------------------ */

static void AccelEventTask(void)
{
    lis2dw12_event_t evt;

    lis2dw12_status_t st = lis2dw12_process_event(&s_accel, &evt);
    if (st != LIS2DW12_OK) {
        APP_LOG(TS_ON, VLEVEL_L, "ERROR: accel process_event status=%d\r\n", (int)st);
        return;
    }
    if (!evt.detected) {
        /* INT1 sin WU_IA: rebote del pin o lectura tardia, no es evento */
        return;
    }

    s_event_count++;

    s_last_event.fuente      = PAYLOAD_FUENTE_ACCEL;
    /* El payload solo lleva un eje: prioridad X > Y > Z si disparo multiple */
    s_last_event.eje         = evt.axis_x ? PAYLOAD_EJE_X :
                               evt.axis_y ? PAYLOAD_EJE_Y :
                               evt.axis_z ? PAYLOAD_EJE_Z : PAYLOAD_EJE_NINGUNO;
    /* El wake-up del LIS2DW12 no reporta magnitud del impacto; se informa el
       umbral superado. Mejora futura: leer OUT_X/Y/Z al procesar. */
    s_last_event.magnitud_mg = APP_SENSORS_WAKEUP_THRESHOLD_MG;
    s_last_event.reed_state  = app_sensors_read_reed_now();
    s_last_event.tick_ms     = HAL_GetTick();
    s_has_event = true;

    APP_LOG(TS_ON, VLEVEL_L, "EVT accel: src=0x%02X eje=%u conteo=%u\r\n",
            evt.raw_src, (unsigned int)s_last_event.eje, (unsigned int)s_event_count);

    TrySendAlarm(PAYLOAD_FUENTE_ACCEL);
}
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

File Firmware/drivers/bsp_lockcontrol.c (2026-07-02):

/**
  ******************************************************************************
  * @file    bsp_lockcontrol.c
  * @brief   Implementacion del BSP: I2C1 + GPIO EXTI0/1.
  * @author  Yahir Flores - 0G IoT Solutions
  ******************************************************************************
  */

#include "bsp_lockcontrol.h"

/* Lo provee la aplicacion (main.c del SDK); se declara aqui para no acoplar
   el BSP a main.h */
extern void Error_Handler(void);

/* Handle global */
I2C_HandleTypeDef hi2c1;

/* ----------------------------- I2C1 ----------------------------- */

static void MX_I2C1_Init(void)
{
    hi2c1.Instance              = I2C1;
    /* 100 kHz Standard Mode @ 16 MHz PCLK1 (HSI). Valor oficial STM32WL. */
    hi2c1.Init.Timing           = 0x10707DBC;
    hi2c1.Init.OwnAddress1      = 0;
    hi2c1.Init.AddressingMode   = I2C_ADDRESSINGMODE_7BIT;
    hi2c1.Init.DualAddressMode  = I2C_DUALADDRESS_DISABLE;
    hi2c1.Init.OwnAddress2      = 0;
    hi2c1.Init.OwnAddress2Masks = I2C_OA2_NOMASK;
    hi2c1.Init.GeneralCallMode  = I2C_GENERALCALL_DISABLE;
    hi2c1.Init.NoStretchMode    = I2C_NOSTRETCH_DISABLE;

    if (HAL_I2C_Init(&hi2c1) != HAL_OK) {
        Error_Handler();
    }
    if (HAL_I2CEx_ConfigAnalogFilter(&hi2c1, I2C_ANALOGFILTER_ENABLE) != HAL_OK) {
        Error_Handler();
    }
    if (HAL_I2CEx_ConfigDigitalFilter(&hi2c1, 0) != HAL_OK) {
        Error_Handler();
    }
}

/* MSP del I2C1: clocks + pines + NVIC */
void HAL_I2C_MspInit(I2C_HandleTypeDef *hi2c)
{
    if (hi2c->Instance != I2C1) return;

    GPIO_InitTypeDef GPIO_InitStruct = {0};
    RCC_PeriphCLKInitTypeDef PeriphClkInit = {0};

    /* I2C1 clock source = PCLK1 */
    PeriphClkInit.PeriphClockSelection = RCC_PERIPHCLK_I2C1;
    PeriphClkInit.I2c1ClockSelection   = RCC_I2C1CLKSOURCE_PCLK1;
    if (HAL_RCCEx_PeriphCLKConfig(&PeriphClkInit) != HAL_OK) {
        Error_Handler();
    }

    /* GPIO clock */
    __HAL_RCC_GPIOA_CLK_ENABLE();

    /* PA9 = SCL, PA10 = SDA */
    GPIO_InitStruct.Pin       = GPIO_PIN_9 | GPIO_PIN_10;
    GPIO_InitStruct.Mode      = GPIO_MODE_AF_OD;
    GPIO_InitStruct.Pull      = GPIO_NOPULL;     /* pull-up externos 4.7k */
    GPIO_InitStruct.Speed     = GPIO_SPEED_FREQ_HIGH;
    GPIO_InitStruct.Alternate = GPIO_AF4_I2C1;
    HAL_GPIO_Init(GPIOA, &GPIO_InitStruct);

    /* Peripheral clock */
    __HAL_RCC_I2C1_CLK_ENABLE();
}

void HAL_I2C_MspDeInit(I2C_HandleTypeDef *hi2c)
{
    if (hi2c->Instance != I2C1) return;
    __HAL_RCC_I2C1_CLK_DISABLE();
    HAL_GPIO_DeInit(GPIOA, GPIO_PIN_9 | GPIO_PIN_10);
}

/* ----------------------------- GPIO EXTI ----------------------------- */

static void MX_GPIO_LockControl_Init(void)
{
    GPIO_InitTypeDef GPIO_InitStruct = {0};

    __HAL_RCC_GPIOA_CLK_ENABLE();

    /* PA0 -> ACCEL_INT1: input EXTI rising, pull-down */
    GPIO_InitStruct.Pin  = ACCEL_INT1_PIN;
    GPIO_InitStruct.Mode = GPIO_MODE_IT_RISING;
    GPIO_InitStruct.Pull = GPIO_PULLDOWN;
    HAL_GPIO_Init(ACCEL_INT1_GPIO_PORT, &GPIO_InitStruct);

    /* PA1 -> REED: input EXTI both edges, pull-up */
    GPIO_InitStruct.Pin  = REED_PIN;
    GPIO_InitStruct.Mode = GPIO_MODE_IT_RISING_FALLING;
    GPIO_InitStruct.Pull = GPIO_PULLUP;
    HAL_GPIO_Init(REED_GPIO_PORT, &GPIO_InitStruct);

    /* NVIC */
    HAL_NVIC_SetPriority(ACCEL_INT1_EXTI_IRQn, 5, 0);
    HAL_NVIC_EnableIRQ(ACCEL_INT1_EXTI_IRQn);

    HAL_NVIC_SetPriority(REED_EXTI_IRQn, 5, 0);
    HAL_NVIC_EnableIRQ(REED_EXTI_IRQn);
}

/* ----------------------------- Watchdog ----------------------------- */

#if LOCKCONTROL_IWDG_ENABLE

static IWDG_HandleTypeDef hiwdg;

static void MX_IWDG_Init(void)
{
    /* LSI ~32 kHz / prescaler 256 = 125 Hz de conteo.
       Reload = timeout_ms * 125 / 1000 (16 s -> 2000; max 4095 ~32.7 s). */
    hiwdg.Instance       = IWDG;
    hiwdg.Init.Prescaler = IWDG_PRESCALER_256;
    hiwdg.Init.Reload    = (LOCKCONTROL_IWDG_TIMEOUT_MS * 125U) / 1000U;
    hiwdg.Init.Window    = IWDG_WINDOW_DISABLE;

    if (HAL_IWDG_Init(&hiwdg) != HAL_OK) {
        Error_Handler();
    }
}

void BSP_LockControl_Watchdog_Refresh(void)
{
    HAL_IWDG_Refresh(&hiwdg);
}

#else /* !LOCKCONTROL_IWDG_ENABLE */

void BSP_LockControl_Watchdog_Refresh(void)
{
    /* watchdog deshabilitado: ver nota en bsp_lockcontrol.h */
}

#endif /* LOCKCONTROL_IWDG_ENABLE */

/* ----------------------------- Entry point ----------------------------- */

void BSP_LockControl_Init(void)
{
    MX_I2C1_Init();
    MX_GPIO_LockControl_Init();
#if LOCKCONTROL_IWDG_ENABLE
    MX_IWDG_Init();
#endif
}

/* ----------------------------- IRQ Handlers ----------------------------- */

/* EXTI line 0 -> PA0 (ACCEL_INT1) */
void EXTI0_IRQHandler(void)
{
    HAL_GPIO_EXTI_IRQHandler(ACCEL_INT1_PIN);
}

/* EXTI line 1 -> PA1 (REED) */
void EXTI1_IRQHandler(void)
{
    HAL_GPIO_EXTI_IRQHandler(REED_PIN);
}

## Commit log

2026-05-07 feat: actualizar spec v1.0 - decisiones técnicas, pinout, arquitectura dual sensor
2026-05-07 docs: actualiza spec PDF — quita pie de página + plan MVP a 12 semanas
2026-05-07 docs: agregar justificación de arquitectura API y plan de cumplimiento normativo
2026-06-01 docs: agrega Guia completa PDF + diagrama de flujo SVG
2026-06-02 feat(drivers): driver minimalista LIS2DW12 - WHO_AM_I + wake-up 200mg
2026-06-04 feat(hw): Add verified LSM110A footprint, rename kicad to EasyEDA
    [OBJ_PCB_LSM_Module.obj]
2026-06-15 docs(hardware): BOM MVP v0 verificado en LCSC (issue #4)
    [bom-mvp-v0.csv, bom-mvp-v0.xlsx]
2026-06-15 docs(hardware): BOM MVP v0 verificado en LCSC + costos de corrida (issue #4)
    [bom-mvp-v0.xlsx]
2026-06-18 docs(sigfox): configuración de custom payload y callback uplink
2026-06-29 docs(hardware): datasheets de componentes verificados en LCSC (issue #5)
2026-07-02 feat(drivers): event API lis2dw12 + reed switch + BSP con IWDG parametrizado
    - lis2dw12: API de interrupcion ISR-safe (on_interrupt/has_pending/process_event)
    - reed_switch: driver con debounce 50 ms por software
    - bsp_lockcontrol: I2C1 + EXTI0/1 + IWDG opcional (Y5, default off por Stop2;
    timeout 16 s por TX Sigfox RC2 bloqueante de 7-9 s)
    - fix: Error_Handler declarado extern para no acoplar el BSP a main.h
    [bsp_lockcontrol.c, bsp_lockcontrol.h, lis2dw12.c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]
2026-07-02 feat(app): app_sensors — pipeline evento->payload->TX Sigfox (Y1/Y2/Y3)
    - Y1: WHO_AM_I con 3 reintentos + config wake-up 200 mg + log por UART
    - Y2: tasks procesan eventos, arman payload 12 bytes (codec F1) y transmiten
    con SIGFOX_API_send_frame + cooldown 60 s
    - Y3: CFG_SEQ_Task_ACCEL_EVENT/REED_EVENT enganchadas a stm32_seq desde EXTI
    - API para F3/F4: get_last_event, battery_pct (CR2450), temp_c, read_reed_now
    Build headless CubeIDE: 0 errors, 6 warnings pre-existentes del SDK.
    [app_sensors.c]
2026-07-02 docs(fw): parches SDK documentados + handoff M2 actualizado + reporte avance
    - sdk-patches.md: registro reproducible de los 6 parches al clone del SDK
    (HAL I2C/IWDG, task IDs, main.c, app_sigfox.c, .project/.cproject) y los
    3 hallazgos (drivers nunca compilados, HAL I2C off, include paths virtuales)
    - HANDOFF-FW-M2: secciones 2.4/3.3/4/5.1 reflejan estado real post-aplicacion
    - reporte-m2-2026-07-01: resumen de sesion, verificacion y plan de subida
2026-07-02 docs(spec): roadmap de milestones alineado al plan MVP de 12 semanas
2026-07-02 docs(sigfox): persistencia de credenciales via seccion NOLOAD en el linker
    Fix documentado del STM32WL55JCIX_FLASH.ld: la seccion de credenciales en
    0x0803E500 pasa a (NOLOAD) para que el ELF no lleve las credenciales TEST
    del SDK y las reales del portal sfxp sobrevivan cada re-flasheo.
2026-07-02 feat(demo): programa 3 botones — TX Sigfox por push-button en Nucleo
    B1 (PA0) -> "Hola", B2 (PA1) -> "Mundo", B3 (PC6) -> "0G": demo end-to-end
    del backend 0G sobre Sigfox_AT_Slave V1.5.0 conservando la interfaz AT.
    Incluye buttons_app.c/.h y parches documentados al SDK (stm32wlxx_it,
    sgfx_app, utilities_def, .project).
2026-07-09 feat(demo): multisensor flujo/hall/distancia sobre Sigfox_AT_Slave
    Cuatro apps de usuario seleccionables por feature flag en app_features.h,
    compartiendo el TX de radio y la interfaz AT del Sigfox_AT_Slave V1.5.0:
    - flow_app (YF-S201, activa): totalizador de volumen
    - distance_app + vl53l0x (VL53L0X ToF): puerta abierto/cerrado con histeresis
    - hall_app: sensor Hall magnetico + boton
    - buttons_app: push B1/B2/B3
    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
2026-07-09 docs(hardware): guía de fuente variable + emulación de CR2450 para GATE 2 (issue #6)
    Por qué la alimentación por USB/serial invalida la medición del cap de
    470uF, requisitos de la fuente (lineal, 10mV/1mA, flotante), modelos
    recomendados con disponibilidad MX (Korad KA3005D/KD3005D, Rigol DP711),
    red de emulación de IR con resistencia serie (fresca/50%/EOL) y
    procedimiento sin serial usando el demo de 3 botones.
    Claude-Session: https://claude.ai/code/session_01MLMDznKqFEee6oMYC2QyXt
2026-07-09 refactor(demo): separar multisensor en 3 carpetas por sensor
    Divide Programa_Sensores_Flujo_Hall_Distancia en carpetas independientes,
    una por sensor, cada una como snapshot autocontenido:
    - Programa_Sensor_Flujo (YF-S201) -> USE_FLOW_APP=1
    - Programa_Sensor_Distancia_VL53L0X -> USE_DISTANCE_APP=1
    - Programa_Sensor_Hall_Magnetico -> USE_HALL_APP=1
    Cada app_features.h activa solo el flag de su sensor (antes las tres
    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
2026-07-10 docs(readme): diagramas de arquitectura v2 (producto + sistema) con datos FCC verificados
    Claude-Session: https://claude.ai/code/session_01WVxr3SwickNKGtPZFRE4bV
2026-07-10 docs(fcc): expediente FCC del LSM110A + datos críticos de diseño RF
    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
2026-07-10 fix(docs): traza RF corregida a CPWG 1.0/0.15mm según User Manual FCC
    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
2026-07-10 docs(hardware): especificaciones de diseño PCB con reglas RF certificadas
    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
2026-07-13 docs: Programa_Sensor_Hall_Puerta (EXTI + hora downlink) + guia sistema minimo LSM110A v0
    - Programa standalone (regla 1 programa = 1 proyecto = 1 .ioc): modulo
    hall_door_app (EXTI ambos flancos, debounce, gap, tope diario), payload
    6B con bit de hora-confiable, hora por downlink Sigfox (F0 -> epoch UTC)
    con siembra __TIME__ y AT$TIME de respaldo; server de pruebas del
    callback BIDIR (backend/sigfox_time_server.py) + patches vs AT_Slave.
    - Guia de sistema minimo LSM110A para prototipo v0 (cierra M1/M3):
    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
